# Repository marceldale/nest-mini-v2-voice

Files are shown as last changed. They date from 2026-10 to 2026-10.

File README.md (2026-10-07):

# Open voice satellite board for the Google Nest Mini (2nd gen)

A drop-in replacement board that turns a Google Nest Mini (2nd gen) into a fully local voice
assistant for Home Assistant. Started from the open design by
[iMike78](https://github.com/iMike78/nest-mini-drop-in-pcb) (nest-mini-drop-in-pcb,
CERN-OHL-S v2) and since then reworked, verified and extended into its own board. Everything
that was changed, and why, is in [CHANGES.md](CHANGES.md); the people and projects this one
stands on are named under [Credits](#credits).

> [!WARNING]
> **Status (5 Oct 2026): rev A2 in production at JLCPCB (2 boards, ordered 2 Oct 2026, completion
> expected around 14 Oct 2026).** Every change has been
> verified on paper only — netlist, ERC, DRC with schematic parity, datasheets, firmware source.
> The rotations of all 31 changed or new parts were checked in JLCPCB's assembly preview, and the
> board was ordered with the two fixed options (via filling, ENIG). **Nothing has been checked on
> hardware yet.** Until bring-up results are published here, **do not manufacture from these
> files.** Watch the repository for updates.

> [!NOTE]
> This status line changes again when the boards have been brought up. The steps are tracked in
> the roadmap below; the order itself is in [CHANGES.md](CHANGES.md#rev-a2-ordered-2-oct-2026).




## What it is

The Google Nest Mini (2nd gen) is a well-built little speaker: a good 40 mm driver, a
clean enclosure, two microphones and a touch surface. What ties it to Google is only the
circuit board inside.

This project replaces that board. You open the Nest Mini, take out Google's electronics
and put this board in its place. Speaker, housing, base plate and touch surface stay as
they are. What you get is a fully local voice assistant for Home Assistant: wake word,
speech and echo cancellation run on the device (ESP32-S3 + XMOS XU316), nothing leaves
your network, and the speaker still plays music and announcements.

Under the hood it follows the Home Assistant Voice Preview Edition: same processor
pair, same audio architecture, same ESPHome firmware base — fitted into the Nest Mini's
size, power and mounting constraints.

**What you need:** a Nest Mini (2nd gen), this board (assembled), a Home Assistant
installation and a USB-C cable for the ESP32. The XMOS gets its first image from the ESP32 itself
(a two-step button in Home Assistant; written and compiled, not yet run on hardware — see
Highlights), or over JTAG (J4, an XTAG4 adapter). Wi-Fi can be set up over Bluetooth (Improv,
confirmed by touching the centre button, as on Voice PE). If you
run it from USB rather than from the Nest Mini's own 14 V base plate, use a supply that can give
**1 A** — at full LED brightness the board draws up to 0.8 A, so a plain 500 mA charger is not
enough. On USB alone the amplifier has no supply — PVDD comes only from the 14 V rail (R66) — so
the speaker stays silent while microphones, LEDs and Wi-Fi work; the log then shows a PVDD
under-voltage fault or a `tas58xx` set-up error. That is expected, not a defect.

**What it is not:** a finished consumer product. It is an open hardware design at
prototype stage (see status above). No affiliation with Google.

## Highlights

* **XMOS flash written from the ESP32.** A bus switch (U16, after the Satellite1 principle) lets
  the ESP32 write the XMOS flash directly; the ESPHome component
  [`xmos_flasher`](firmware/esphome/components/xmos_flasher/README.md) does it from a two-step
  button in Home Assistant. **Written and compiled, not yet run on hardware.** JTAG stays as the
  fallback: J4 is an xSYS2 pad field, an XTAG4 plugs on 1:1. Later updates run over I²C (DFU) from
  the ESP32.

  **What the button overwrites:** the whole **1 MiB boot partition** of the XMOS flash U11 is
  erased (256 sectors) and rewritten with the factory image `firmware/xmos/ffva_v1.3.1_factory.bin`
  (286 720 bytes), checked against its MD5 and read back; everything after the image must read
  FFh. An image that a later DFU update put there is replaced by 1.3.1 as well. The data partition
  above 1 MiB is not touched, and the flash status registers are only read, never written — a
  write-protected flash is reported, not unlocked. It works on USB alone or on 14 V (all LEDs
  are switched off meanwhile; load below 0.5 A), needs the enable switch first and takes about 15 s;
  on success the ESP32 restarts.

* **Audio path as on Voice PE.** ESP32 feeds the amplifier and the echo reference on one
  line; XU316 is the clock master. Works with the unmodified Voice PE XMOS firmware.

* **Power without operating rules.** Upstream, USB-C and the 14 V supply must never be
  connected at the same time, and even USB alone back-feeds the 14 V rail through the
  buck converter (a known issue). This board adds an ideal diode (LM66100) behind the
  5 V converter and a small switch that disables the USB supply while 14 V is present.
  Result: plug in USB, 14 V or both, in any order, without risk to the board or the host
  PC.

* **XU316 core on a buck converter.** Upstream feeds the 0.9 V core from a 200 mA linear
  regulator dropping 2.4 V, while the XU316 draws about 300 mA typical and up to 1 A under
  DSP load: the regulator would overheat and the XMOS would brown out. This board uses the
  TPS62065 with 2 A. Also: touch controller wired, antenna matching at the antenna, mic-3 path removed, EasyEDA-checked
  footprints, every part with an LCSC number.

* **Expansion connector (12-pin FPC)** for an add-on ring board. We wanted more than a
  voice satellite: presence detection (radar over UART), temperature/humidity (I²C), IR
  transmit and receive for controlling TV or air conditioning, and an LED ring. None of
  this fits inside the Nest Mini housing (the mounting plate sits flush on the board), so
  the connector stays unpopulated there and the board works as a plain Nest Mini
  replacement. In a custom enclosure it connects to a ring board — LEDs, IR emitters and
  receivers, radar module — that is planned as the next project. The main board carries
  the signals, the ring board carries the sensors.

## Roadmap

- [x] Design review against upstream, Voice PE and Gen1 ([CHANGES.md](CHANGES.md))
- [x] Rev A2 schematic and layout: XMOS flash via ESP32, Voice PE audio path, power without
      operating rules, expansion connector routed
- [x] Rev A2 silkscreen: pin-1 marks, test point labels, revision and date; no DRC warnings left
- [x] Independent audit of rev A2; critical and layout-relevant findings fixed (CHANGES.md section 10)
- [x] Rev A2 manufacturing files regenerated after the audit fixes (`fertigung/`, 1 Oct 2026)
- [x] Rotation check of the 31 changed or new parts in the fabricator's assembly preview
      (JLCPCB preview, 2 Oct 2026; U18, U16, U5, Q4 corrected in the CPL beforehand, Y1 by order remark)
- [x] ESP32-side flasher for the XMOS image — written and compiled, not yet run on hardware
      (`firmware/esphome/components/xmos_flasher/`; fallback: J4 with an XTAG4)
- [x] Rev A2 ordered: 2 assembled boards (5 bare PCBs), JLCPCB, 2 Oct 2026
- [ ] Bring-up: resistance check, power rails, XMOS flash via ESP32
- [ ] Audio, microphones, echo cancellation, touch, LEDs
- [ ] Wi-Fi sensitivity against a reference device
- [ ] Firmware release (ESPHome YAML + XMOS factory image)
- [ ] Ring board and enclosure files
- [ ] Certification plan
- [ ] Crowd Supply campaign

## Trademarks

Google and Google Nest Mini are trademarks of Google LLC. This project is not affiliated with,
endorsed by or sponsored by Google. Home Assistant and ESPHome are projects of the Open Home
Foundation / Nabu Casa. XMOS and xcore are trademarks of XMOS Ltd. All trademarks belong to
their respective owners and are used here only to say what this board is compatible with.

## Licences

| What | Licence |
|---|---|
| Hardware — schematic, layout, our footprints, manufacturing data | **CERN-OHL-S v2** |
| ESPHome YAML, Python tools, documentation | **MIT** |
| XMOS firmware image under `firmware/xmos/` | **XMOS Public Licence v1** — not ours |
| ESPHome component `xmos_flasher` under `firmware/esphome/components/` | **GPL-3.0-only** for the C++ files — derived from [FutureProofHomes/Satellite1-ESPHome](https://github.com/FutureProofHomes/Satellite1-ESPHome) (`memory_flasher`, © Mischa Siekmann, commit `8f8906c`), whose `LICENSE` is the ESPHome licence: C/C++ under GPLv3 without "or any later version", Python under MIT. `__init__.py`, the README and the host test are **MIT**. See [`LICENSES/GPL-3.0-only.txt`](LICENSES/GPL-3.0-only.txt) |
| ESPHome component `tas58xx` under `firmware/esphome/components/` | **GPL-3.0-or-later** — © mrtoy-me, based on work by Andriy Malyshenko (sonocotta); patched by us (start-up order, loop bandwidth), see [`firmware/esphome/PATCH.md`](firmware/esphome/PATCH.md) |
| KiCad library excerpts in `lib_lokal/` | **CC-BY-SA-4.0**, © KiCad Libraries Contributors |
| Parts of `lib_lokal/` (vendor footprints and symbols) | **terms not established** — see below |

Full texts are in [`LICENSES/`](LICENSES/). Files that can carry a comment header do carry an
`SPDX-License-Identifier`; for KiCad documents, Gerbers and binaries the assignment is in
[`REUSE.toml`](REUSE.toml), following the [REUSE](https://reuse.software) specification.

**One honest gap**, written up in
[`LICENSES/LicenseRef-Vendor-Model-Terms-Not-Established.txt`](LICENSES/LicenseRef-Vendor-Model-Terms-Not-Established.txt):

* The vendor 3D models the board references are **not** part of this repository: we hold no
  licence document for any of them. The 3D view therefore shows those parts without a body;
  fabrication and assembly do not need them.
* Parts of `lib_lokal/` have a similar problem: ten of the 23 footprints in `Onju.pretty` carry a
  SnapEDA or EasyEDA note, `New_Library.kicad_sym` is SnapEDA, and the Seeed and reSpeaker symbols
  come from Seeed's project. They arrived with the upstream design and we pass them on unchanged.
  This directory **cannot** be left out — without it the design does not open.

**`lib_lokal/` and the two library tables are versioned on purpose.** The design references every
symbol and footprint through `${KIPRJMOD}/lib_lokal/`, so a clone without them opens with empty
placeholders. The directory holds trimmed excerpts, not whole libraries: `Device.kicad_sym` is
17 kB here against 2 374 kB in a KiCad 9.0.9 installation. KiCad's library licence grants an
exception for designs that *use* the libraries but states that it does not apply when they are
redistributed as a collection — which is what this directory does — so those files keep
CC-BY-SA-4.0 with attribution.

The C++ code in this repository is the patched copy of the ESPHome component `tas58xx`
(GPL-3.0-or-later) and the component `xmos_flasher` (GPL-3.0-only, because its source states GPLv3
without "or later"), both under `firmware/esphome/components/`; see the table above.
CERN-OHL-S v2 is a **strongly reciprocal** licence: if you make and distribute a board from
these files, or from a modified version of them, you have to make the complete source of your
version available under the same licence. See
[`LICENSES/CERN-OHL-S-2.0.txt`](LICENSES/CERN-OHL-S-2.0.txt), sections 3.2 and 4.

---

# For reference

Everything below is the technical detail — useful once you have a board in your hand, and not
needed to understand what the project is.

## Test points

Eighteen pads, all bare copper, nothing to populate. Sixteen are on the microphone side; the touch
electrodes are on the LED side. The silkscreen carries a short name next to each pad — the full net
name would not fit on a 68 mm board.

| Marking | Ref | Net | Side | Position | What you should see |
|---|---|---|---|---|---|
| `3V3` | TP1 | `+3V3` | microphone side | 163.00 / 74.50 | 3.3 V |
| `5V_SW` | TP3 | `/Power/+5V_SW` | microphone side | 121.40 / 102.00 | about 5 V, **before** the ideal diode U18 |
| `1V8` | TP4 | `+1V8` | microphone side | 145.70 / 71.50 | 1.8 V |
| `VDD` | TP5 | `VDD` | microphone side | 130.40 / 81.60 | 0.9 V |
| `3V3` | TP6 | `+3V3` | microphone side | 107.40 / 94.60 | 3.3 V |
| `XRST` | TP11 | `XU316_RST` | LED side | 126.10 / 66.50 | logic; high = XU316 held in reset |
| `MUTE` | TP12 | `MUTE` | microphone side | 140.90 / 116.80 | logic; follows the mute slider |
| `PA_EN` | TP13 | `AUDIO_PA_EN` | microphone side | 130.70 / 109.10 | logic; high = amplifier enabled |
| *(no marking)* | TP14 | `ELEC2` | LED side | 159.20 / 89.90 | touch electrode, right |
| *(no marking)* | TP15 | `ELEC1` | LED side | 135.82 / 119.53 | touch electrode, centre |
| *(no marking)* | TP16 | `ELEC0` | LED side | 114.20 / 88.90 | touch electrode, left |
| `5V` | TP17 | `+5V` | microphone side | 122.42 / 105.55 | about 5 V, **after** U18 — below TP3 by I × 79 mΩ (LM66100 R_ON): ≈ 8 mV per 100 mA, 55…65 mV at 0.7…0.8 A |
| `14V` | TP18 | `+14V` | microphone side | 143.90 / 109.43 | 14 V from the base plate |
| `RST` | TP19 | `ESP_RST` | microphone side | 118.58 / 79.30 | logic; low = ESP32 in reset |
| `BOOT` | TP20 | `ESP_BOOT` | microphone side | 121.84 / 81.75 | logic; low at power-up = boot mode |
| `GND` | TP21 | `GND` | microphone side | 120.58 / 64.74 | 0 V reference, next to U8 |
| `GND` | TP22 | `GND` | microphone side | 128.74 / 104.08 | 0 V reference, next to U14 |
| `VMIC` | TP23 | `VDD_MIC` | microphone side | 105.10 / 88.35 | 3.3 V microphone supply |

The three touch points carry no silkscreen: they sit inside the electrode rings on the LED side,
where any lettering would end up on copper. Their names are `T_R`, `T_C` and `T_L` in the schematic.

**The pair TP3 / TP17 is the one to measure first.** TP3 sits before the ideal diode U18, TP17
after it. The difference is the load current times U18's on-resistance (79 mΩ typical, LM66100 datasheet):
under 20 mV at idle, about 55…65 mV at 0.7…0.8 A; in USB-only operation TP3 should read
roughly 0 V, because the 14 V rail is then dead and the diode blocks the path back into it.

## Connectors

The board carries a designator and a pin-1 dot for every connector; the pinouts are here rather than
on the silkscreen, where they would not be legible at 0.5 mm pitch.

### J6 — ribbon cable to the LED ring board, 12 way, 0.5 mm pitch

| Pin | Net | | Pin | Net |
|---|---|---|---|---|
| 1 | `GND` | | 7 | `UART_RX` |
| 2 | `+5V` | | 8 | `I2C_SDA` |
| 3 | `+5V` | | 9 | `I2C_SCL` |
| 4 | `GND` | | 10 | `IR_TX` |
| 5 | `LED_DOUT` | | 11 | `IR_RX` |
| 6 | `UART_TX` | | 12 | `+3V3` |

Pin 1 is the one nearest the dot. `LED_DOUT` continues the LED chain from LED6 through R80, so the
ring board's first LED is index 6 as far as the firmware is concerned.

### POWER_IN1 — flat flex to the base plate, 10 way, 0.5 mm pitch

| Pin | Net | | Pin | Net |
|---|---|---|---|---|
| 1 | `GND` | | 6 | `GND` |
| 2 | `MUTE` | | 7 | `+14V` |
| 3 | `GND` | | 8 | `+14V` |
| 4 | `GND` | | 9 | `+14V` |
| 5 | `GND` | | 10 | `+14V` |

**Confirmed pin for pin against an independent design:** the schematic of
[Onju Voice](https://github.com/justLV/onju-voice) (`hardware/Onju-Home.SchDoc`, a replacement
board for the same Nest Mini 2nd gen) has the same ten-way connector as J1, and all ten pins
agree — 1 and 3–6 `GND`, 2 `MUTE`, 7–10 `14V`. Metering it on an original is optional; the quick
check is in `CHANGES.md` ("POWER_IN1: the pinout is now confirmed against a second source").

### J4 — XMOS JTAG pad field, 2×5, 1.27 mm pitch, unpopulated

The pin-out is the **xSYS2 JTAG-only header** of the XU316 datasheet (appendix G.3, figure 25), so
an XTAG4 plugs on **1:1** — pin 1 to pin 1. Pin 1 is marked by the silkscreen dot.

| Pin | Net | | Pin | Net |
|---|---|---|---|---|
| 1 | `+1V8` (VREF) | | 2 | `TMS` |
| 3 | `GND` | | 4 | `TCK` |
| 5 | `GND` | | 6 | `TDO` |
| 7 | `GND` | | 8 | `TDI` |
| 9 | `GND` | | 10 | `RST_N` |

VREF is 1.8 V on pin 1, with 100 nF (C103) right next to it. There is no 5 V and no 3.3 V on this
field. Up to the audit fixes of 1 Oct 2026 the field carried a rotated, non-standard pin-out with
VREF on pin 6; a board made from an older revision needs an adapter.

## Before bring-up

> [!NOTE]
> **Amplifier driver.** The ESPHome core component `tas58xx` (TAS5805M) arrives with ESPHome 2026.10.
> Until then use ESPHome `dev`, or the patched copy under `firmware/esphome/components/tas58xx`, which
> `nest-mini-v2-voice.yaml` loads by default and which builds with ESPHome 2026.9.0. A configuration for
> the core component is [`nest-mini-v2-voice-kerntreiber.yaml`](nest-mini-v2-voice-kerntreiber.yaml)
> (ESPHome `dev` / 2026.10 or later; it adds the 175 kHz loop bandwidth the core component does not set yet).

> [!CAUTION]
> **Do not burn `EFUSE_STRAP_JTAG_SEL` on the ESP32-S3.** Rev A2 uses GPIO3 and GPIO39 to
> GPIO42 as an SPI bus to the XMOS flash. In the factory state JTAG runs over the
> USB-Serial/JTAG controller and those pins are free; burning the eFuse switches JTAG to
> those pins and breaks the XMOS flash path. Details in
> [CHANGES.md](CHANGES.md#do-not-burn-efuse_strap_jtag_sel-esp32-s3).

## Manufacturing files

**`fertigung/` holds the rev A2 set**, generated after the audit fixes on 1 Oct 2026: Gerbers and
Excellon drill files, `gerber_jlcpcb.zip` for upload, BOM and CPL for JLCPCB, BOM and assembly
drawing for PCBWay. [`fertigung/ABLAUF.md`](fertigung/ABLAUF.md) documents the commands that
produce it and the checks each one prints — nothing in that directory is edited by hand.
**It is not released**: the board has never been fabricated, and two checks are still open (see
below).

Before ordering, these are the points to watch; the full list with the evidence is under
["Before you order" in CHANGES.md](CHANGES.md#before-you-order-the-seven-things-to-get-right):

* **0.10 mm minimum track width** for the two UART signals — fabricable at JLCPCB without a
  surcharge, but not everywhere.
* **Via-in-pad:** board vias reach into 23 pads (58 vias, all same-net), among them three signal
  pads and the large pads of U8 and U10. Order the vias **Epoxy Filled & Capped**.
* **U11 must be the `IQ` variant** of the W25Q32JV, not `IM` — the footprint cannot tell them
  apart, and only `IQ` has the QE bit set at the factory.
* Seven same-net via pairs sit exactly at the **0.2 mm hole-to-hole limit**.
* **J1** (Molex 1054500101, C134092) is stocked but flagged “process difficult” in the BOM
  check — confirm it by hand.
* Stack-up: 4 layers, 1.6 mm, **JLC04161H-7628**; surface finish chosen at order time.

Placement corrections by hand are **no longer needed**: rev A1 shipped a CPL with 19 of them, and
rev A2 fixes the footprint origins themselves instead (X1, J5, J1), so the CPL exporter
writes a correct CPL directly; the remaining nineteen corrections are applied automatically.

**Two things are still open**, both for the operator and both listed in
[`fertigung/DREHLAGEN_PRUEFEN.md`](fertigung/DREHLAGEN_PRUEFEN.md):

1. **31 parts need checking in JLCPCB's assembly preview** — those whose LCSC number changed
   since rev A1 (U5, LED2–LED5, J6, R76, R77, R80, X1, J1) or that are new (U16, U18, U19, Q4),
   nine from the audit fixes (L1, L2 with a new footprint; C20, C100 with new numbers;
   C105–C109 new, all unpolarised), and seven from the pin audit and the order (Y1 with a new number — the one
   where rotation matters, a 90° error puts the crystal on the ground pads, and it has no model in
   the preview, so the order carries the remark "Y1 orientation per silkscreen pin-1 corner mark
   (top-left)"; R72, C17, C63, C98, R35 with new numbers; R81 new). The first preview on 2 Oct 2026
   found U18 and U16 turned; a recomputation of all 42 polarised parts against the fabricator's
   footprints corrected four rotations (U18, U16, U5, Q4) — see `CHANGES.md`. C110 is not fitted and not in the CPL.
   For them the fabricator's own footprint decides the zero orientation, and that has not been
   compared yet. Everything else was checked in rev A1 and has not moved since.
2. **Two order options are fixed for this board** and have to be selected because they are not in
   the Gerbers: via covering ***Epoxy Filled & Capped*** (vias reach into 23 pads) and surface
   finish **ENIG** — decided, not optional (0.40 mm pitch, QFN thermal pads, the J4
   spring-contact field, test points and touch electrodes). Both are in "Before you order" in
   `CHANGES.md`.

The upstream design and its own documents are at
[iMike78/nest-mini-drop-in-pcb](https://github.com/iMike78/nest-mini-drop-in-pcb).

## Credits

This board exists because other people published theirs first.

* **[iMike78](https://github.com/iMike78/nest-mini-drop-in-pcb)** — *nest-mini-drop-in-pcb*,
  the design this one forks. The board outline, the mounting geometry, the microphone and touch
  arrangement and a great deal of the layout are the designer's work.
* **[Onju Voice](https://github.com/justLV/onju-voice)** (Justin Alvey) — the first drop-in
  board for the Nest Mini, and the origin of the `Onju` footprint library this project still uses.
* **[Home Assistant Voice PE](https://github.com/esphome/home-assistant-voice-pe)**
  (Nabu Casa / Open Home Foundation) — the audio architecture this board follows: the same
  ESP32-S3 + XMOS XU316 pair, the same clocking, and the XMOS firmware it runs.
* **[Satellite1](https://github.com/FutureProofHomes/Satellite1-ESPHome)** (FutureProofHomes)
  — the method for flashing the XMOS from the ESP32, which is what makes this board
  programmable without a debugger.
* **[ESPHome](https://esphome.io) and [Home Assistant](https://www.home-assistant.io)** — the
  firmware and the platform all of it runs on.

## How to follow or contribute

Star or watch the repository. **Issues and Discussions are handled here, in this repository:**
Discussions for questions, Issues for errors in the design or the documentation. Hardware
support starts after bring-up. Reference thread: Home Assistant community, topic 860001.

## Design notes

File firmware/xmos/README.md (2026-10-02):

# XMOS XU316 factory flash image

`ffva_v1.3.1_factory.bin` is the factory boot image for **U10 (XU316-1024-QF60B-C24)** and its
boot flash **U11 (W25Q32JVSSIQ, 4 MB)**. It contains the XTC boot loader and the factory
application, ready to be written to the SPI flash.

## Source notice (XMOS Public Licence v1, clause 2.3)

This file is compiled code. **The source code of the software it is built from is available under
the terms of the XMOS Public Licence v1** — a copy of which is in this directory as
`LICENCE-XMOS-PUBLIC-LICENCE-v1.rst` — from:

* <https://github.com/esphome/voice-kit-xmos-firmware> — the FFVA firmware for the Home Assistant
  Voice Preview Edition, tag **`v1.3.1`** (released 2024-09-17)

Nothing in the firmware was changed here. The `.xe` release artefact was repackaged into a flash
image by `xflash`; no source file was modified, added or removed.

Clause 2.2.2 of that licence permits commercial distribution only while the software is used on a
device designed, licensed or developed by XMOS. That is the case here: it runs on the XU316.

## Provenance

| | |
|---|---|
| Built from | `ffva_v1.3.1.xe`, 5 779 572 bytes, MD5 `7233589645bce7f7289c47136c0792ae` |
| Downloaded from | <https://github.com/esphome/voice-kit-xmos-firmware/releases/download/v1.3.1/ffva_v1.3.1.xe> |
| Tool | XMOS XTC Tools **15.3.1**, `xflash` build 61-0e6d8350 (2024-07-04) |
| Built on | 2026-09-30 |

## How this file was produced

```
xflash --factory ffva_v1.3.1.xe --boot-partition-size 0x100000 -o ffva_v1.3.1_factory.bin
```

The build is deterministic and the result does not depend on the target description: the same
286 720 bytes come out with `--target-file NC-VOICE-KIT.xn`, with an XN whose flash `Type` is changed
from `S25FL116K` to `W25Q32JV`, and with `--boot-partition-size` set to `0x80000` or omitted
entirely. The target description is compiled into the `.xe`, and the boot-partition size is metadata
rather than padding. So this file can be reproduced from the public release asset at any time, and
the checksums in `MD5SUMS` are the check.

## Size against the flash

| | Bytes | Share |
|---|---|---|
| This image | 286 720 (280.0 KiB) | — |
| Boot partition (`0x100000`) | 1 048 576 | 27.3 % used |
| U11 flash (W25Q32JVSSIQ) | 4 194 304 | **6.8 % used** |
| Left for the data partition | 3 145 728 (3 MiB) | — |

## Writing it

This image is for an external programmer or for assembly-time programming. **Over JTAG you do not
need it** — `xflash` writes directly from the `.xe`:

```
xflash --quad-spi-clock 50MHz --factory ffva_v1.3.1.xe --boot-partition-size 0x100000
```

The XTAG4 goes onto the J4 pad field **1:1**: J4 follows the xSYS2 JTAG-only pin-out of the XU316
datasheet (appendix G.3) — 1 VREF (`+1V8`), 2 TMS, 4 TCK, 6 TDO, 8 TDI, 10 RST_N, 3/5/7/9 GND; pin 1
is marked by the silkscreen dot. The pad
field is unpopulated — solder or use spring contacts. `xflash --list-devices` must show the adapter
and the device first. Afterwards power-cycle the board: the ESPHome log has to show
`[voice_kit] DFU version: 1.3.1` (about 3 s after the ESP32 resets the XU316) and must not show
`Communication with Voice Kit failed` before the first-time programming counts as done. From then on
updates go over DFU via I²C from the ESP32.

None of the XTC tools is on the search path on the design machine; load the environment per call:

```
cmd /c "cd /d <dir> && "C:\Program Files\XMOS\XTC\15.3.1\SetEnv.bat" && xflash …"
```

`W25Q32JV` is one of the 15 flash devices natively supported by `libquadflash`
(`target/include/QuadSpecEnum.h`, `WINBOND_W25Q32JV = 13`), so no `--spi-spec` file is needed and
nothing depends on SFDP auto-detection.

One thing to watch on the first write: the firmware's own target description sets
`QE_REGISTER = flash_qe_location_status_reg_0` and leaves `QE_BIT` commented out. Our part carries the
`IQ` order suffix, where the QE bit is factory-fixed to 1, so it should not be needed. If `xflash`
complains about the QE bit, set it in a local XN.

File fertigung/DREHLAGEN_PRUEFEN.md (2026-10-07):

# Drehlagen und Positionen fuer die JLCPCB-Vorschau — Soll-Zustand

Stand: **02.10.2026**, nach der JLCPCB-Vorschau berichtigt (U18, U16, U5, Q4; Y1-Bemerkung; R35).
Zuvor: 01.10.2026, erzeugt aus `CPL_JLCPCB.csv` und der Platine (rev A2 Endstand).
Die Fassung vom 21.09.2026 ist ersetzt; sie nannte U1, U2, C1, C2, R37, R38, R51, R64
und FB3, die es nicht mehr gibt, und kannte die in E2.3, E4, E5c und F7.3 neu
eingefuegten Bauteile nicht.

**Grundlage:** `ft_cpl.py` (Logik des Fabrication Toolkit) plus
`werkzeug/jlc_korrektur.csv` (19 Zeilen). Die Korrekturen stammen aus einem Abgleich mit
dem EasyEDA-Footprint der jeweiligen LCSC-Nummer; dieser Footprint bestimmt JLCPCBs
Nullage und Mittelpunkt.

* **Konvention**, an den laut Vorschau richtigen Teilen bestaetigt:
  * oben: CPL-Drehung = Drehung des EasyEDA-Footprints
  * unten: CPL-Drehung = 360° − Drehung des gespiegelten EasyEDA-Footprints
  * Bestaetigt oben an U8 und U9, unten an U10, U11, Q1, Q3 und X1; am 02.10.2026 an allen
    42 gepolten und mehrpoligen Teilen nachgerechnet (Abschnitt „Berichtigung").
* **Pin 1** ist die Lage von Pad 1 relativ zur Padmitte, in der Ansicht der Vorschau:
  oben in Draufsicht, unten in Unteransicht — also seitenverkehrt zur Draufsicht.
  Die Werte unten sind aus unserem Footprint gerechnet.
* In der Vorschau pruefen: rosa Punkt an der angegebenen Ecke; Bestueckungsdruck-Marke
  an derselben Ecke; das Gehaeuse deckt alle Pads.

## Berichtigung nach der JLCPCB-Vorschau vom 02.10.2026

Die Bestellung wurde angehalten: die Vorschau zeigte U18 mit Pin 1 oben links statt unten links
(VIN/VOUT vertauscht), U16 mit Pin 1 unten rechts statt unten links und Y1 nur als Platzhalter.
Daraufhin wurde **jedes gepolte oder mehrpolige Bauteil** (42 Zeilen, Tabelle unten) gegen den
EasyEDA-Footprint seiner LCSC-Nummer nachgerechnet, nicht nur die drei gemeldeten: Footprint laden,
an die CPL-Mitte legen (unten in x gespiegelt), in 45°-Schritten drehen und gleichnamige Pads
zaehlen (`werkzeug/easyeda_abgleich.py`, Daten `pruefung/easyeda_pads_2026-10-02.json`).

**Vier Drehungen waren falsch**, alle vier jetzt in `werkzeug/jlc_korrektur.csv` (19 Zeilen):

| Bauteil | LCSC | Seite | CPL bisher | CPL jetzt | Abgleich mit dem EasyEDA-Footprint | Folge der alten Drehung |
|---|---|---|---|---|---|---|
| **U18** | C2869734 | oben | 270° | **0°** | 6/6 Pads in gleicher Reihenfolge; Pin 1 unten links (`/Power/+5V_SW`). EasyEDA setzt die Padreihen bei ±1,10 mm, unser Footprint bei ±0,89 mm — 0,21 mm je Reihe, symmetrisch nach aussen, die Anschluesse liegen auf den Pads | Gehaeuse quer, VIN/VOUT vertauscht (Meldung aus der Vorschau) |
| **U16** | C129313 | unten | 90° | **0°** | 10/10 Pads, max. 0,04 mm; Pin 1 in der Vorschau (Unteransicht) unten links | Pin 1 unten rechts (Meldung aus der Vorschau) |
| **U5** | C133796 | oben | 0° | **270°** | 5/5 Pads, max. 0,13 mm; EasyEDA hat Pin 1 unten rechts (Endung `-BR`), unser Footprint unten links | Eingangs- und Ausgangsseite quer; die alte Korrekturzeile „unverdreht deckungsgleich" war falsch |
| **Q4** | C383201 | oben | 0° | **180°** | 3/3 Pads, max. 0,03 mm; Pin 1 (`USB_EN_GATE`) oben links | Gate/Source auf der Drain-Seite; Q1 und Q2 mit derselben Nummer waren richtig, weil fuer sie eine andere Regel greift |

Alle uebrigen 38 Zeilen stimmen mit dem EasyEDA-Footprint. Nicht als Zaehlung, sondern im
Einzelnen belegt sind:

* **J5:** EasyEDA zerlegt jeden der beiden 7-mm-Kontaktstreifen in zwei Pads (1+4, 2+3); bei 225°
  liegen 1 und 4 auf unserem Streifen 1, 2 und 3 auf Streifen 2 — richtig.
* **D6:** 1→1 und 2→2 bei 270°, je 0,32 mm Versatz (anderer Padabstand), richtig.
* **U3/U7:** 16/17 — das Waermepad ist bei uns in Teilflaechen zerlegt; alle Anschlusspads 0,04 mm.
* **MK1/MK2:** 4/8 — Massering wie unter „Einzelhinweise".
* **SW1/SW2:** 2/4 — Taster, 180°-symmetrisch, Pads 1/2 und 3/4 paarweise verbunden.

**Y1 (C49158179):** EasyEDA liefert fuer die Nummer kein Bauteil („Component not found",
abgefragt 02.10.2026); die Vorschau zeigt nur einen Platzhalter, und der Bestuecker legt das
Teil von Hand auf. Die Drehung in der CPL (270°) bleibt; massgeblich ist die Bestueckungsdruck-Marke:
der Winkel im Bestueckungsdruck sitzt an der Ecke **oben links**, und dort liegt Pad 1
(`XTAL_N`) — aus der Platine nachgemessen (Winkel 117,03…119,57 / 67,83…70,77 mm, Pad 1 bei
117,75 / 68,60). **Bemerkung fuer JLCPCB im Bestellformular:**

> Y1 orientation per silkscreen pin-1 corner mark (top-left).

**R35:** neue Nummer **C100510** (LIZ Elec CR0402FF6800G, 680 Ω 1 % 0402) statt C25130, Ersatz auf
Angabe des Betreibers. Ungepolt; Zeile in der Tabelle des Pin-Audits.

Quelle der Footprint-Daten: JLCEDA/EasyEDA Official Library (https://lceda.cn/,
https://easyeda.com), abgerufen am 02.10.2026 ueber
`easyeda.com/api/products/<LCSC>/components`.

## JLCPCB-DFM-Rückfrage LED-Polarität (05.10.2026) — Ansichtskonvention und Sollage

**Ansicht in JLCPCBs DFM-Bildern:** Die Unterseite wird **links-rechts gespiegelt** gezeigt, so dass
der Bestückungsdruck lesbar ist: **J1 oben links**, auf der LED-Seite liegt **LED5 links, LED2 rechts**.
Das ist dieselbe Ansicht wie KiCads „Flip board view“ (Spiegelung um die senkrechte Achse) und wie die
Spalte „Pin 1 in der Vorschau“ dieser Datei für Bauteile auf der Unterseite. Die Oberseite wird
ungespiegelt gezeigt (J1 oben rechts).

**Befund (Betreiber, DFM-Bild zu SMT026100262223):** Das JLCPCB-Modell zeigte bei LED2–LED5 „+“ und den
Pin-1-Punkt **unten links**, „−“ oben rechts, DI oben links, DO unten rechts. In dieser Ansicht liegt
unser Pad 1 (+5V) aber **oben rechts** → Modell **um 180° falsch**. LED1 war richtig. Der Betreiber hat
JLCPCB um eine 180°-Drehung von LED2–LED5 und ein neues Bild gebeten (05.10.2026). **Ergebnis:** JLCPCB hat
LED2–LED5 um 180° korrigiert; neues Bild vom 05.10.2026 zeigt +5V oben rechts in der gespiegelten
Unteransicht — vom Betreiber freigegeben. LED1 bestätigt, **LED6 nicht ausdrücklich bestätigt** (Sichtprüfung
bei der Inbetriebnahme, Arbeitsnotizen, nicht veröffentlicht: HANDGRIFFE Schritt 0.7). Fertigung freigegeben, Fertigstellung ca. 14.10.2026.

**Merkregel für künftige Vorschauen bei JLCPCB:** Oberseite ungespiegelt (J1 oben rechts); Unterseite
links-rechts gespiegelt (J1 oben links). Die Spalte „Pin 1 in der Vorschau“ dieser Datei gilt genau in dieser
Ansicht. Ein Modell, dessen Pin-1-Punkt an einer anderen Ecke liegt, ist zu beanstanden — auch wenn der
EasyEDA-Abgleich nummerngleich passt (LED2–LED5, 05.10.2026).
Widerspruch zum EasyEDA-Abgleich vom 02.10.2026: dort passen bei CPL 90° alle 4 Pads des EasyEDA-Footprints
von C2909058 nummerngleich auf unsere Pads. JLCPCBs Bestückmodell weicht also vom EasyEDA-Footprint ab
(Pin-1-Lage), oder die Nummerierung im EasyEDA-Footprint passt nicht zum Gehäuse — ungeklärt. Für eine
Folgefertigung: Arbeitsnotizen (nicht veröffentlicht), HANDGRIFFE Abschnitt 6, F4.

**Sollage je LED in JLCPCBs Ansicht**

| Bauteil | Seite / Ansicht | +5V | GND | DIN | DOUT | Gehäusemerkmal |
|---|---|---|---|---|---|---|
| LED2, LED3, LED4, LED5 (SK6812-EC20, Pin 1 = VDD) | unten, gespiegelt (J1 oben links) | **oben rechts** (Pad 1) | unten links (Pad 3) | unten rechts (Pad 4) | oben links (Pad 2) | Kerbe auf der Gehäuseunterseite an der Kante +5V/DOUT, also **oben**; IC-Chip an der Kante GND/DIN (unten) |
| LED1 (SK6812D-EC3210R, westliche Lasche) | oben, ungespiegelt (J1 oben rechts) | 2. Pad von Süden (Pad 4) | 2. Pad von Norden (Pad 1) | Südende (Pad 3) | Nordende (Pad 2) | Linse nach Westen (Platinenkante); kein Punkt im Datenblatt |
| LED6 (SK6812D-EC3210R, östliche Lasche) | oben, ungespiegelt | 2. Pad von Norden (Pad 4) | 2. Pad von Süden (Pad 1) | Nordende (Pad 3) | Südende (Pad 2) | Linse nach Osten (Platinenkante) |

Reihenfolge auf der LED-Seite in dieser Ansicht von links nach rechts: LED5, LED4, LED3, LED2; der DO jeder
LED zeigt zum DI der links benachbarten. Sollbild: `pruefung/jlcpcb_led_sollage_2026-10-05.png` (dort in der
anderen Spiegelung, oben/unten — Pad-Netze gleich).

## Was nach rev A1 neu zu pruefen ist

Fuer diese **15** Bauteile hat sich die LCSC-Nummer geaendert oder das Bauteil ist neu.
JLCPCB hinterlegt dann einen anderen EasyEDA-Footprint, und der bestimmt die Nullage.
**Nur diese Zeilen muss der Betreiber in der Vorschau durchsehen** — alles andere war
in rev A1 abgeglichen und ist seither unveraendert.

| Bauteil | Seite | Drehung | Mitte X / Y | Pin 1 (Netz) | warum neu |
|---|---|---|---|---|---|
| **J1** | oben | 135° | 152.9000 / -65.8000 | unten (GND) | in E5.3 als FP_SMD gekennzeichnet, Position daher aus dem Ursprung |
| **J6** | oben | 270° | 157.9750 / -93.7810 | unten rechts (GND) | neu in E5c; Nummer in E7 von C25744/C324723 auf C424659 berichtigt |
| **Q4** | oben | 180° | 157.0000 / -83.9000 | oben links (/Power/USB_EN_GATE) | neu in E4; Nummer C383201 erst in E7 eingetragen; Drehung am 02.10.2026 von 0° berichtigt |
| **R76** | oben | 0° | 156.4000 / -81.8000 | links (+14V) | Nummer in E7 von C17168 (0 Ohm!) auf C26083 (1 M) berichtigt |
| **R77** | oben | 0° | 157.1000 / -80.8000 | links (/Power/USB_EN_GATE) | Nummer in E7 von C17168 (0 Ohm!) auf C25778 (330 k) berichtigt |
| **R80** | oben | 0° | 154.7000 / -90.6900 | links (/LEDs/LED6_DOUT) | Nummer in E7 von C25744 (10 k!) auf C25076 (100 R) berichtigt |
| **U5** | oben | 270° | 141.0000 / -75.9650 | unten links (+3V3) | Typ MIC5365-1.8 -> TLV70018DCKR (C626087 -> C133796), E5.2; Drehung am 02.10.2026 von 0° berichtigt |
| **U18** | oben | 0° | 124.8000 / -106.7000 | unten links (/Power/+5V_SW) | neu in E4; Nummer C2869734 erst in E7 eingetragen; Drehung am 02.10.2026 von 270° berichtigt |
| **LED2** | unten | 90° | 125.2624 / -89.1135 | oben rechts (+5V) | Typ SK6805-EC20 -> SK6812-EC20 (C2890036 -> C2909058), E6 |
| **LED3** | unten | 90° | 132.2500 / -89.1000 | oben rechts (+5V) | Typ SK6805-EC20 -> SK6812-EC20 (C2890036 -> C2909058), E6 |
| **LED4** | unten | 90° | 139.2000 / -89.1000 | oben rechts (+5V) | Typ SK6805-EC20 -> SK6812-EC20 (C2890036 -> C2909058), E6 |
| **LED5** | unten | 90° | 146.1000 / -89.1000 | oben rechts (+5V) | Typ SK6805-EC20 -> SK6812-EC20 (C2890036 -> C2909058), E6 |
| **U16** | unten | 0° | 121.5000 / -70.2500 | unten links (unconnected-(U16-D1+-Pad1)) | neu in E2.3; Drehung am 02.10.2026 von 90° berichtigt |
| **U19** | unten | 0° | 118.4500 / -84.4500 | unten rechts (GND) | neu in F7.3; Nummer C12495 erst in E7 eingetragen |
| **X1** | unten | 270° | 133.0000 / -59.5000 | oben links (Net-(U10-XIN)) | Ursprung in E5.3 auf das Bezugszentrum gesetzt |

Bei den vier Ring-LEDs ist die Erwartung, dass sich **nichts** aendert: beide LED-Typen
haben die Anschluesse an denselben Stellen (Datenblaetter SK6805-EC20-001 Rev. A1 und
SK6812-EC20-001 Rev. A/2, je Seite 4), und die CPL-Werte sind vor und nach dem Wechsel
gleich. Zu pruefen ist allein, ob JLCPCBs Footprint fuer C2909058 dieselbe Nullage hat
wie der fuer C2890036. **Ergebnis 05.10.2026: nein** — JLCPCBs Modell lag um 180° falsch (Abschnitt
„JLCPCB-DFM-Rückfrage LED-Polarität“).

## Nach den Audit-Fixes vom 01.10.2026 zusaetzlich zu pruefen

Die CPL ist aus dem Stand nach den Audit-Fixes neu erzeugt. **Neun** Zeilen kommen hinzu. Alle sind
ungepolt (Kondensatoren, Spulen); in der Vorschau zu pruefen ist nur, dass das Gehaeuse mittig auf
beiden Pads sitzt und nichts versetzt ist.

| Bauteil | Seite | Drehung | Mitte X / Y | LCSC | warum neu |
|---|---|---|---|---|---|
| **L1** | oben | 90° | 121.0125 / -109.5615 | C719179 | neuer Footprint `L_Bourns_SRP4020TA` (Audit M18): Pads 1,5 x 2,4 mm bei ±1,85 mm statt Cenker-Landmuster; LCSC-Nummer unveraendert |
| **L2** | oben | 90° | 112.0000 / -98.0500 | C719179 | wie L1 |
| **C100** | oben | 0° | 133.6000 / -82.3000 | C40059 | neue Nummer (120 pF statt 22 pF, Audit M2) |
| **C20** | oben | 0° | 137.5896 / -75.1115 | C1779 | neue Nummer (4,7 µF statt 10 µF, Audit M2) |
| **C105** | unten | 270° | 124.3000 / -115.9800 | C307331 | neu (Audit M1), 0402 auf B.Cu unter U3 |
| **C106** | unten | 270° | 115.7500 / -106.4300 | C1525 | neu (Audit M1), 0402 auf B.Cu unter U7 |
| **C107** | oben | 0° | 143.0000 / -65.9400 | C19702 | neu (Audit M3), 0603 |
| **C108** | oben | 315° | 105.6000 / -85.1000 | C1525 | neu (Audit M11), 0402 schraeg neben MK1 |
| **C109** | oben | 0° | 168.6000 / -92.2000 | C1525 | neu (Audit M11), 0402 neben MK2 |

J4 (xSYS2-Padfeld, Audit K2) ist DNP und steht nicht in der CPL.

## Nach dem Pin-Audit vom 02.10.2026 zusaetzlich zu pruefen

Die CPL ist aus dem Stand nach H1–H6 und den Entscheidungen vom 02.10.2026 neu erzeugt. **Sieben** Zeilen kommen hinzu (C110 ist DNP und steht nicht in der CPL). Y1 ist das einzige
Teil, bei dem die Drehung zaehlt: um 90° verdreht laegen die Quarzanschluesse (Pins 1/3) auf den
GND-Pads (2/4). Um 180° verdreht ist gleichwertig (der Quarz ist symmetrisch).

| Bauteil | Seite | Drehung | Mitte X / Y | LCSC | warum neu |
|---|---|---|---|---|---|
| **Y1** | oben | 270° | 118.3000 / -69.3000 | C49158179 | neue Nummer (JLYE Y201640MDBCX, ±10 ppm, Pin-Audit H1); Pin 1 oben links (Net-(U8-XTAL_N)), Pin 3 zu XTAL_P — JLYE-Datenblatt „Connection“: 1/3 Quarz, 2/4 GND. **Kein EasyEDA-Modell**, Bemerkung an JLCPCB: „Y1 orientation per silkscreen pin-1 corner mark (top-left)“ |
| **R72** | unten | 180° | 139.8100 / -82.1000 | C25798 | neue Nummer (75 kΩ statt 200 kΩ, H2) |
| **C17** | oben | 180° | 138.9700 / -73.1150 | C19702 | neue Nummer (10 µF statt 4,7 µF, H4); dieselbe Nummer wie C13/C18/C107 |
| **R81** | unten | 270° | 116.1000 / -84.9000 | C25744 | neu (H3), 0402 auf B.Cu neben U19 |
| **C63** | unten | 0° | 122.7550 / -60.7500 | C52923 | neue Nummer (1 µF statt 100 nF, U10-B1) |
| **C98** | unten | 180° | 139.8000 / -83.1000 | C1525 | neue Nummer (100 nF statt 1 µF, MPR121-Datenblatt) |
| **R35** | unten | 90° | 131.6000 / -60.6000 | C100510 | neue Nummer (LIZ Elec CR0402FF6800G, 680 Ω 1 %, statt C25130), Ersatz bei der Bestellung 02.10.2026 |

## Alle gepolten und mehrpoligen Bauteile

Spalte „Abgleich": Herkunft der Drehung. Zusaetzlich sind **alle** Zeilen am 02.10.2026 gegen
den EasyEDA-Footprint nachgerechnet (Abschnitt „Berichtigung").

| Bauteil | Seite | Drehung | Mitte X / Y (mm) | Pin 1 in der Vorschau (Netz) | Abgleich |
|---|---|---|---|---|---|
| AE1 | oben | 45° | 113.7747 / -66.9253 | unten links (Net-(AE1-Pad1)) | rev A1 |
| C89 | oben | 315° | 155.5934 / -110.5934 | oben links (PVDD) | rev A1, korrigiert |
| D3 | oben | 45° | 149.9606 / -69.5323 | unten links (GND) | rev A1 |
| D4 | oben | 45° | 149.2606 / -68.8323 | unten links (GND) | rev A1 |
| D5 | oben | 0° | 114.4502 / -81.4710 | links (ESP_3V3) | rev A1 |
| J1 | oben | 135° | 152.9000 / -65.8000 | unten (GND) | **NEU PRUEFEN** |
| J5 | oben | 225° | 160.8106 / -105.6288 | unten rechts (Net-(C86-Pad1)) | rev A1, korrigiert |
| J6 | oben | 270° | 157.9750 / -93.7810 | unten rechts (GND) | **NEU PRUEFEN** |
| LED1 | oben | 270° | 100.5202 / -89.0869 | oben rechts (GND) | rev A1, korrigiert |
| LED6 | oben | 90° | 171.1100 / -89.0668 | unten links (GND) | rev A1, korrigiert |
| MK1 | oben | 225° | 104.1227 / -82.3469 | rechts (Net-(MK1-DATA)) | rev A1 |
| MK2 | oben | 45° | 167.4438 / -96.0810 | links (Net-(MK2-DATA)) | rev A1 |
| POWER_IN1 | oben | 0° | 141.3104 / -120.2010 | oben rechts (GND) | rev A1, korrigiert |
| Q4 | oben | 180° | 157.0000 / -83.9000 | oben links (/Power/USB_EN_GATE) | **NEU PRUEFEN**, EasyEDA 02.10., korrigiert |
| R76 | oben | 0° | 156.4000 / -81.8000 | links (+14V) | **NEU PRUEFEN** |
| R77 | oben | 0° | 157.1000 / -80.8000 | links (/Power/USB_EN_GATE) | **NEU PRUEFEN** |
| R80 | oben | 0° | 154.7000 / -90.6900 | links (/LEDs/LED6_DOUT) | **NEU PRUEFEN** |
| SW1 | oben | 270° | 115.3000 / -85.0000 | oben rechts (ESP_RST) | rev A1 |
| SW2 | oben | 270° | 119.0200 / -85.0000 | oben rechts (ESP_BOOT) | rev A1 |
| U3 | oben | 270° | 122.0500 / -114.5625 | oben links (Net-(L1-Pad1)) | rev A1, korrigiert |
| U4 | oben | 0° | 153.4000 / -84.7000 | unten links (+5V) | rev A1, korrigiert |
| U5 | oben | 270° | 141.0000 / -75.9650 | unten links (+3V3) | **NEU PRUEFEN**, EasyEDA 02.10., korrigiert |
| U6 | oben | 180° | 135.7000 / -78.8600 | oben rechts (GND) | rev A1, korrigiert |
| U7 | oben | 270° | 112.9800 / -103.2300 | oben links (Net-(L2-Pad1)) | rev A1, korrigiert |
| U8 | oben | 90° | 124.4000 / -70.0000 | unten links (Net-(U8-LNA_IN)) | rev A1 |
| U9 | oben | 90° | 127.2000 / -60.3000 | unten rechts (/ESP32-S3R8/SPI_CS0) | rev A1 |
| U14 | oben | 270° | 136.2000 / -103.3000 | oben links (GNDA) | rev A1, korrigiert |
| U18 | oben | 0° | 124.8000 / -106.7000 | unten links (/Power/+5V_SW) | **NEU PRUEFEN**, EasyEDA 02.10., korrigiert |
| Y1 | oben | 270° | 118.3000 / -69.3000 | oben links (Net-(U8-XTAL_N)) | **NEU PRUEFEN** (neue Nummer C49158179, H1; kein EasyEDA-Modell, nach Bestueckungsdruck) |
| D1 | unten | 225° | 152.2606 / -64.3323 | oben rechts (GND) | rev A1 |
| D6 | unten | 270° | 138.4000 / -76.2000 | oben (Net-(U12-2Y)) | rev A1 |
| LED2 | unten | 90° | 125.2624 / -89.1135 | oben rechts (+5V) | **NEU PRUEFEN** |
| LED3 | unten | 90° | 132.2500 / -89.1000 | oben rechts (+5V) | **NEU PRUEFEN** |
| LED4 | unten | 90° | 139.2000 / -89.1000 | oben rechts (+5V) | **NEU PRUEFEN** |
| LED5 | unten | 90° | 146.1000 / -89.1000 | oben rechts (+5V) | **NEU PRUEFEN** |
| Q1 | unten | 180° | 137.3000 / -56.6000 | oben links (VBUS) | rev A1 |
| Q2 | unten | 270° | 123.0000 / -63.0000 | unten links (Net-(Q2-G)) | rev A1, korrigiert |
| Q3 | unten | 180° | 138.2800 / -94.5000 | oben links (Net-(Q3-B)) | rev A1 |
| U10 | unten | 180° | 137.8749 / -64.6003 | unten rechts (/XMOS/QSPI_D1) | rev A1 |
| U11 | unten | 90° | 127.2000 / -76.2000 | unten rechts (/XMOS/QSPI_CS_N) | rev A1 |
| U12 | unten | 180° | 135.0000 / -76.5000 | oben rechts (GND) | rev A1, korrigiert |
| U13 | unten | 180° | 132.9625 / -94.5000 | oben links (+5V) | rev A1, korrigiert |
| U15 | unten | 90° | 142.9000 / -83.6000 | unten rechts (/ESP32-S3R8/TOUCH_IRQ) | rev A1, korrigiert |
| U16 | unten | 0° | 121.5000 / -70.2500 | unten links (unconnected-(U16-D1+-Pad1)) | **NEU PRUEFEN**, EasyEDA 02.10., korrigiert |
| U19 | unten | 0° | 118.4500 / -84.4500 | unten rechts (GND) | **NEU PRUEFEN** |
| X1 | unten | 270° | 133.0000 / -59.5000 | oben links (Net-(U10-XIN)) | **NEU PRUEFEN** |

## Ungepolt oder 180°-symmetrisch

Widerstaende, Kondensatoren, Spulen und die beiden Taster. Hier ist die Drehung ohne
Bedeutung; zweipolige ungepolte Teile und SW1/SW2 zeigen gegenueber dem
EasyEDA-Footprint teils 180° Unterschied, was nicht geaendert wurde.

| Footprint | Bauteile |
|---|---|
| `BLM18PG121SN1D` | FB2 90°, FB4 90°, FB5 0° |
| `C_0402_1005Metric` | C5 180°, C16 180°, C24 90°, C26 0°, C27 180°, C28 270°, C29 180°, C30 90° (unten), C31 0°, C32 0°, C33 90° (unten), C34 90° (unten), C35 90° (unten), C36 0°, C37 180°, C38 90°, C39 90°, C40 90°, C41 0°, C42 90°, C43 90°, C44 270°, C45 0°, C46 0°, C47 180°, C48 90° (unten), C49 180°, C50 0°, C51 0°, C52 180°, C53 180°, C54 0° (unten), C55 0°, C56 0°, C57 270°, C58 180° (unten), C59 180°, C60 0°, C61 180° (unten), C62 180° (unten), C63 0° (unten), C65 180° (unten), C66 0° (unten), C67 0°, C68 270° (unten), C69 270° (unten), C70 270° (unten), C71 225°, C72 45°, C78 180°, C83 90°, C88 0°, C92 90°, C93 180° (unten), C94 180° (unten), C95 180° (unten), C96 180° (unten), C97 270°, C98 180° (unten), C99 0° (unten), C100 0°, C101 180° (unten), C103 0°, C104 90° (unten) |
| `C_0603_1608Metric` | C6 90°, C7 90°, C8 270°, C9 270°, C12 270°, C13 270°, C17 180°, C18 180°, C21 270°, C25 270°, C64 180° (unten), C74 180°, C75 180°, C76 180°, C77 180°, C80 270°, C82 270°, C90 90°, C91 90° |
| `C_0805_2012Metric` | C3 270°, C4 270°, C10 180°, C11 270°, C14 270°, C15 270°, C19 0°, C20 0°, C22 270°, C23 270°, C79 90°, C81 90°, C84 270°, C85 270°, C86 90°, C87 270° |
| `L_0402_1005Metric` | L3 270°, L4 90°, L5 270° |
| `L_Cenker_CKCS4020` | L1 90°, L2 90° |
| `L_Murata_DFE201610P` | L8 270° |
| `MTQH404030S100MBT` | L6 180°, L7 180° |
| `R_0402_1005Metric` | R1 315°, R2 225° (unten), R3 225° (unten), R5 135°, R7 180°, R8 180°, R9 180°, R14 180°, R15 180°, R20 0°, R21 0°, R22 180°, R24 0°, R27 0°, R28 0°, R29 270°, R30 270°, R31 180°, R32 90°, R33 180°, R34 180° (unten), R35 90° (unten), R36 180° (unten), R39 180° (unten), R40 0° (unten), R41 180° (unten), R42 0° (unten), R43 180° (unten), R44 180° (unten), R45 270° (unten), R46 270° (unten), R47 0° (unten), R48 180° (unten), R49 0° (unten), R50 180° (unten), R52 90° (unten), R53 180° (unten), R54 90° (unten), R55 180°, R56 90° (unten), R57 0°, R58 270° (unten), R59 135°, R60 315°, R62 45°, R63 315°, R65 90° (unten), R70 0°, R71 90°, R72 180° (unten), R73 180° (unten), R74 90°, R75 0°, R79 0° |
| `R_0603_1608Metric` | FB1 225° (unten), R11 0°, R12 270°, R13 90°, R17 0°, R18 270°, R19 90°, R67 180° (unten) |
| `R_0805_2012Metric` | R68 270°, R69 90° |
| `R_1206_3216Metric` | R66 90° |

## Einzelhinweise

* **Y1:** Auch fuer die neue Nummer C49158179 liefert EasyEDA keinen Footprint ("Component not
  found", 02.10.2026; vorher ebenso fuer C424431); **nicht abgleichbar**. Bei einem 4-Pin-Quarz
  vertauscht eine 90°-Drehung Quarz- und Masseanschluesse. Pin 1 (XTAL_N) muss oben links liegen,
  an der Ecke mit dem Winkel im Bestueckungsdruck. Bemerkung an JLCPCB: „Y1 orientation per
  silkscreen pin-1 corner mark (top-left)".
* **MK1/MK2:** EasyEDA teilt den Massering in vier Flaechen, unser Footprint hat einen
  Ring mit zwei Pads. Die Signalpads und die Schallöffnung decken sich; in rev A1 war
  das in der Vorschau richtig.
* **C89** (Polymer-Elko): Pad 1 ist **PVDD**, also der Plus-Anschluss. Die
  180°-Korrektur der Fabrication-Toolkit-Regel `^C_Elec_` ist zurueckgenommen.
* **J1** (USB-C): die vier Schirmlaschen sitzen in durchkontaktierten Langloechern.
  Pruefen, dass das Gehaeuse auf allen 24 Signalpads und den vier Laschen liegt.

Erzeugt mit `scratchpad/e6/h1_drehlagen.py` aus CPL und Platine; Berichtigung vom 02.10.2026
von Hand nach `werkzeug/easyeda_abgleich.py`, jede geaenderte Zahl dort nachgerechnet.

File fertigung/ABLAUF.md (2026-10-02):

<!--
SPDX-FileCopyrightText: 2026 marceldale
SPDX-License-Identifier: MIT
-->

# How this directory is generated

Everything in `fertigung/` is produced from the KiCad files by the scripts in `werkzeug/`.
Nothing here is edited by hand. Run the steps in this order from the project root; each one
overwrites its own output.

## Step zero: check the BOM fields

```bash
python fertigung/werkzeug/bom_pruefen.py .
```

**Run this before generating anything.** It exists because E7 found ten wrong or missing part
numbers, and none of them was visible to ERC, DRC or the schematic-parity check — those look at
nets, not at order fields. The worst of them would have fitted R76 and R77, the divider that sets
Q4's gate voltage, with **0 Ω links**, which is a short from +14 V to ground.

It checks six things: schematic against layout for every component (number and value); no
populated part without a number; no number hiding in a field no exporter reads (`LCSC`,
`Supplier Part`); one number under two different values; resistor-style MPNs or descriptions on
parts that are not resistors; and, for the Uniroyal `0402WGFxxxxTCE` numbers, the encoded value
against the value field. It exits non-zero if it finds anything.

One known-good exception is built in: `C221897` sits on SW1 and SW2 with the value fields "Reset"
and "BOOT" — the same button, labelled differently.

What it cannot do is check a number against its LCSC product page. It prints the list of all 86
numbers with their URLs and the components that use each one; that part is handwork, and it is
where the J6, R80, R76 and R77 errors were actually settled.

```bash
python fertigung/werkzeug/fertigung.py nest-mini-v2-drop-in-pcb.kicad_pcb nest-mini-v2-drop-in-pcb.kicad_sch fertigung
```

That one command produces the JLCPCB set: Gerbers and Excellon drill files in `gerber/`
(plus drill maps as PDF), `gerber_jlcpcb.zip` for upload, `BOM_JLCPCB.csv` and
`CPL_JLCPCB.csv`. It prints three things worth reading:

* **BOM zusammengefasst** — part numbers used by more than one value or footprint. Two are
  expected: `C383201` (Q1, Q2, Q4 — the same MOSFET on two footprint variants of SC-70-3)
  and `C221897` (SW1, SW2 — the same button, labelled Reset and BOOT). Anything else means
  a part number is on the wrong component; that is how the J6 and R80 errors were found.
* **ohne LCSC** — components with no part number. Must be empty.
* **in CPL, nicht in BOM / in BOM, nicht in CPL** — both must be empty.

Then the PCBWay set:

```bash
python fertigung/werkzeug/bom_einzeln.py . fertigung/werkzeug/bom_einzeln.csv
python fertigung/werkzeug/pcbway_bom.py fertigung/werkzeug/bom_einzeln.csv
python fertigung/werkzeug/pcbway_xlsx.py fertigung/werkzeug/bom_einzeln.csv fertigung/pcbway/BOM_PCBWay.xlsx
```

`pcbway_bom.py` fetches manufacturer, MPN, description and package for every part number from
JLCPCB's parts API and **compares the MPN against the schematic**. Two differences are known
and deliberate — the part number names what is actually ordered, the MPN field what the design
asked for:

| Part | Schematic | Ordered |
|---|---|---|
| J5 | TE 1775443-2 | TE 5-1775443-2 (C5162845), variant of the same series |
| D6 | RB521S30T1G | RB521S30T1G-DW (C27636108), packaging variant |

Any **third** difference is a finding, not noise. (Until the audit fixes of 1 Oct 2026 there were
four: L8 and C100 now carry the ordered part in the schematic — L8 Sunlord WPN201610U1R0MTY01,
Isat 3.0 A min / 3.5 A typ per the Sunlord catalogue; C100 is FH 0402CG121J500NT, 120 pF.)

The assembly drawing needs KiCad's own Python, because it plots through pcbnew:

```bash
"C:/Program Files/KiCad/9.0/bin/python.exe" fertigung/werkzeug/bestueckzeichnung.py nest-mini-v2-drop-in-pcb.kicad_pcb <scratch>/kopie.kicad_pcb
"C:/Program Files/KiCad/9.0/bin/python.exe" fertigung/werkzeug/bestueck_plot.py <scratch>/kopie.kicad_pcb <scratch>/plot
```

The two resulting PDFs are joined into `pcbway/Bestueckungszeichnung.pdf`. `bestueckzeichnung.py`
works on a **copy** — it adds designators, outlines, pin-1 dots and polarity marks to the Fab
layers and removes DNP parts, and none of that belongs in the design file.

Finally `pcbway/Positionen_KiCad.csv`, the plain KiCad position export, as a cross-check against
the CPL:

```bash
kicad-cli pcb export pos --format csv --units mm --side both --exclude-dnp --output fertigung/pcbway/Positionen_KiCad.csv nest-mini-v2-drop-in-pcb.kicad_pcb
```

## Before handing anything to a fabricator

1. **Run `bom_pruefen.py` and read the LCSC pages it lists.** See above.
2. Zones must be filled and the fill must be current. Check it, do not assume it: fill the zones
   in a copy and compare the filled areas against the saved ones. For the set generated after the
   production state (2 Oct 2026, after C110): 11 582.99 mm² over 15 zone layers (13 zones), saved and
   refilled equal. One zone (`+14V` on In2) can alternate between 147.28 and 147.32 mm² from one fill
   to the next — a fill-iteration effect, 0.03 %; the Gerbers are made from the saved state. (After the audit
   fixes of 1 Oct 2026 the total was 11 596.11 mm²; H6 perforates the `VDD` area on In2 under U10.)
3. Read `DREHLAGEN_PRUEFEN.md` and work through the **15 + 9 + 7 new rows** (rev A1 → A2, the
   audit fixes and the pin-audit fixes; Y1 is the one where rotation matters, and it has no model in the preview) in JLCPCB's
   assembly preview. Those are the parts whose LCSC number changed since rev A1, or that are new;
   for them the fabricator's own footprint decides the zero orientation, and nobody has compared
   it yet.
4. Read "Before you order" in `CHANGES.md` — seven points, including the 0.10 mm track width and
   the `IQ` variant of U11.
5. **Select the two order options.** They are not in the Gerbers; nobody will ask twice:
   * **Via covering: *Epoxy Filled & Capped*.** The board vias reach into **23 pads (58 vias, all same-net)**, measured after the pin-audit fixes of 2 Oct 2026: the via centre lies inside 14 pads — J6.11, R79.2, R80.1 (signal), C99.1, U11.6, L1.2 (supply), C47.2 and C60.2 (GND, on F.Cu above the U10 paddle, two of the H6 vias), and the large pads of U8 (9 vias) and U10 (32 vias: 16 GND, 4 in each VDD paddle) — and in 9 more pads part of the drilled hole reaches into the solder-mask opening (C65.1, J1.B6, J4.4, J4.6, LED2.1, TP21, TP22, U19.2, U19.4).
     An open via wicks solder out of the joint in reflow. Our vias are 0.30 mm drill / 0.40 mm
     diameter, inside the 0.15–0.55 mm range the process supports.
   * **Surface finish: ENIG.** 0.40 mm pitch on four parts, QFN thermal pads, the J4 spring-contact
     pad field, eighteen test points and three touch electrodes all want a planar finish. Exposed
     copper is 7.64 % of the board area, well under the 30 % above which JLCPCB adds an area
     surcharge.

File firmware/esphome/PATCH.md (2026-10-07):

<!--
SPDX-FileCopyrightText: 2026 marceldale
SPDX-License-Identifier: MIT
-->

# Local copy of `tas58xx` with a start-up patch

`components/tas58xx/` is the ESPHome external component
[mrtoy-me/esphome-tas58xx](https://github.com/mrtoy-me/esphome-tas58xx) at commit
`89f29cfd687200e908a6459404abfbb513adb17d` (branch `main`, the newest state on 1 Oct 2026),
copied unchanged in one commit and patched in the next, so `git diff` between the two shows the
patch exactly. `nest-mini-v2-voice.yaml` loads it with `external_components: source: type: local`.

## Why

The TAS5805M on this board is wired for PBTL (outputs 23+26 and 17+20 paralleled). The original
start-up writes a register table (`tas58xx_minimal.h`) that ends with

```
{ 0x02, 0x00 },   // DEVICE_CTRL_1: BTL
{ 0x54, 0x00 },   // AGAIN: 0 dB
{ 0x03, 0x03 },   // DEVICE_CTRL_2: PLAY
```

and only afterwards `configure_registers_()` sets PBTL (`set_dac_mode_`, DEVICE_CTRL_1 bit 2) and
the analog gain (`set_analog_gain_`, −12 dB). For that short time the amplifier plays in BTL at
full analog gain into paralleled outputs. The TAS5805M datasheet (SLASEH5D, 7.5.3.1 step 4) asks
for the device to be set into Hi-Z, configured, and only then put into PLAY.

## The patch

| File | Original | Patched |
|---|---|---|
| `tas58xx_minimal.h` | `{ 0x03, 0x03 }` (PLAY) at the end of the table | `{ 0x03, 0x02 }` (Hi-Z) |
| `tas58xx.h` | `ControlState tas58xx_control_state_;` — never initialised (the comment says "initialised in setup", `setup()` does not) | `ControlState tas58xx_control_state_{CTRL_HI_Z};` |
| `tas58xx_minimal.h` | `{ 0x53, 0x00 }` — class-D loop bandwidth 80 kHz | `{ 0x53, 0x60 }` — 175 kHz (pin audit U14-B2, added 2 Oct 2026) |
| `tas58xx.cpp` `update()` | every fault is cleared on the next 1 s update, DC and over-current included | DC and over-current faults (CHAN_FAULT bits 0–3) are not cleared; nothing is cleared while one is present, the output stays off until the device restarts (added 5 Oct 2026, as in the ESPHome core component; SLASEH5D 7.5.3.3.1/2: a DC fault re-trips only after 570 ms) |

With both, `configure_registers_()` runs: `set_deep_sleep_off_()` (no write, state is Hi-Z) →
`set_modulation_scheme_()` → `set_dac_mode_(PBTL)` → `set_analog_gain_(−12 dB)` →
`set_state_(CTRL_PLAY)`, which now writes PLAY because the state differs. Without the
initialisation, a random start value could equal `CTRL_DEEP_SLEEP` (then `set_deep_sleep_off_`
writes PLAY before PBTL) or `CTRL_PLAY` (then PLAY would never be written).

**Why 175 kHz (U14-B2).** Register 0x02 is 0x04 here (FSW_SEL = 000 = 768 kHz, PBTL, BD). The
datasheet's field description of ANA_CTRL (table 7-27) says "With Fsw=768kHz, 175kHz bandwidth should
be selected for high audio performance", section 7.3.8.2 says "Same Fsw, Better THD+N performance
with higher BW", and table 7-3 allows 175 kHz for BD at 768 kHz (rule Fsw ≥ 3 × BW: 768 ≥ 525 kHz).
The datasheet's PBTL curves are measured with exactly this set-up (768 kHz, 10 µH / 0.68 µF, BD,
175 kHz), and its example start-up script writes `w 58 53 60`. The value is written while the device
is still in Hi-Z. On the sample: read back 0x53 (expect 0x60) and compare THD+N before/after.

Not changed: the undocumented register `0x46 = 0x01`, whose source comment says "SR 96KHz; for
48KHz use 0x11" while this bus runs at 48 kHz. TI lists the address as reserved; the effect has to
be checked on the sample (read back register 0x71 for clock errors) before touching it.

## Licence

The upstream repository has no licence file. Its README states that the component is based on
work by Andriy Malyshenko (sonocotta) licensed under GPL-3.0, so the copy is distributed here under
**GPL-3.0-or-later** (`LICENSES/GPL-3.0-or-later.txt`), with mrtoy-me and Andriy Malyshenko named as
authors and our two modifications marked with a dated notice at the top of each changed file
(GPL-3.0 section 5 a). The assignment is in `REUSE.toml`. This file (`PATCH.md`) is our own text, MIT.

The same change was submitted to the upstream repository as PR #4. Status: PR #4 closed; per maintainer's comment in mrtoy-me/esphome-tas58xx#4 the start-up order is covered by his development branch and by the ESPHome core driver (esphome/esphome#19971).

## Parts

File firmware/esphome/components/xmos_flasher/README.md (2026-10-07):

<!--
SPDX-FileCopyrightText: 2026 marceldale
SPDX-License-Identifier: MIT
-->

# `xmos_flasher` — write the XU316 factory image from the ESP32

The XU316 boots from its own SPI flash U11 (W25Q32JVSSIQ), which is **empty as delivered**. Once an
image is in it, `voice_kit` keeps it current over I²C (DFU). This component fills an empty or damaged
U11 from the ESP32-S3, without a JTAG adapter: it writes `firmware/xmos/ffva_v1.3.1_factory.bin`
(286 720 bytes) over the bus switch U16, verifies it and restarts.

## Operation (Home Assistant)

1. Supply the board from USB or from 14 V (base plate or bench supply at TP18); see "Supply" below.
   The device must have been up for 30 s, and its last restart must not have been a brown-out.
2. Switch on **"XMOS-Flash freigeben"** (configuration entity). It switches itself off after 60 s.
3. Press **"XMOS-Flash schreiben"** within those 60 s. The wake word, the voice assistant and media
   playback are stopped first.
4. Watch **"XMOS-Flash Status"** (`connect` → `identify` → `erase` → `write` → `verify` → `done`) and
   **"XMOS-Flash Fortschritt"** (%). It takes about 15 s (erase 256 × 45 ms typical, 1 120 pages of
   about 1.5 ms, 1 MiB read back at 4 MHz); each `loop()` call works for up to 20 ms, so the write is
   not paced by ESPHome's 16 ms loop interval.
5. On success the ESP32 restarts after 3 s; the log must then show `[voice_kit] DFU version: 1.3.1`.
   On failure the status reads `failed: <stage> <reason> at 0x<address>`, the bus is released and the
   XU316 is let out of reset; nothing restarts. Pressing the button again repeats the whole write.

Nothing happens at start-up: the component only acts on the button.

## What it does on the bus

| Step | Action | Evidence |
|---|---|---|
| connect | GPIO46 high: Q2 pulls `RST_N` low (XU316 in reset) **and** U16 connects D± to its 2D side (`S` = 1, `OE` = GND), so GPIO39 reaches `QSPI_CS_N` and GPIO40 `QSPI_D1`. 10 ms settle. SPI2 is set up on GPIO3 (CLK), GPIO4 (MOSI = D0), GPIO40 (MISO), GPIO39 (CS), mode 0, 4 MHz. | Netlist: `XU316_RST` = U8.52 GPIO46, R47, U16.9 S, TP11; `QSPI_CLK` = U8.8, U11.6, U10.5; `QSPI_D0` = U8.9, U11.5, U10.59; `XMOS_SPI_CS_N` = U8.44, U16.8; `XMOS_SPI_MISO` = U8.45, U16.7; U16.3/4 = `QSPI_CS_N`/`QSPI_D1`. TS3USB221 table 7-1: OE low, S high → D = 2D. In reset the XU316's GPIOs are inputs with weak pull-downs (XU316 datasheet section 8). |
| identify | First 16 clocks of FFh (ends a continuous-read mode the XU316 may have left), wait while BUSY (an interrupted DFU erase/program), then 66h + 99h software reset (tRST 30 µs) — never during BUSY, the datasheet warns of data corruption. Then 9Fh must return **EF 40 16**; 35h is read and **QE must be 1** (the IQ part has QE fixed at 1; with QE = 0 `/HOLD` would be active and is pulled low by the XU316 in reset). SR1 BP0–2/TB/SEC and SR2 CMP must be 0 (otherwise erase/program would be ignored silently) — the status registers are never written, a protected flash is reported, not unlocked. | W25Q32JV datasheet: JEDEC ID table, QE bit S9 ("factory fixed default for … IQ"), section "Enable Reset (66h) and Reset Device (99h)", block-protect bits. |
| erase | 06h + 05h (WEL must be set), 20h for each 4 KiB sector of the **whole 1 MiB boot partition** (256 sectors), busy-polled with 05h, 1 s timeout per sector. The data partition above 1 MiB is not touched. | tSE 45 ms typ / 400 ms max. Boot partition 0x100000 as the image was built (`firmware/xmos/README.md`). |
| write | One 256-byte page per loop: 06h, 02h, busy-poll (10 ms timeout), then 03h read-back and byte compare. The last page is padded with FFh. | tPP 0.4 ms typ / 3 ms max; 03h up to fR = 50 MHz. |
| verify | 03h over the whole boot partition, 4 KiB per loop: MD5 of the first 286 720 bytes against `MD5SUMS`, and every byte after the image must be FFh (no stale upgrade image). | |
| release | SPI bus freed, **GPIO3/4/39/40 back to floating inputs first**, then GPIO46 low: U16 isolates CS/MISO and the XU316 boots from U11. On success the ESP32 restarts (`App.safe_reboot()`), so `voice_kit`, the microphones and the amplifier come up in their normal order. | |

The image is **embedded at compile time** (`image_file`, `md5_file` in the YAML). The build fails if
its MD5 does not match `MD5SUMS` or if it does not fit the boot partition. There is no download at
run time. Cost: firmware image 2 283 639 → 2 600 735 bytes (32.0 % of an 8 MB OTA slot).

## Limits

* No lock against a running `voice_kit` DFU update or against automations that restart the wake word
  during the write: the flash is not at risk (the XU316 is in reset, the ESP owns the bus), but a DFU in
  progress is aborted and audio components log errors until the restart.
* The SPI pins are given as plain numbers, so ESPHome does not flag a second use of GPIO3/4/39/40 in the
  YAML; keep them free (the YAML comment lists them as reserved).
* After a failure the wake word stays stopped until the next restart.

## Supply: USB alone or 14 V

Since 2 Oct 2026 the write is allowed on **USB alone** as well as on 14 V (operator's decision; before
that it was refused without PVDD). Conditions, checked in the YAML before the button is accepted:

* **`+5V` present.** The board has no voltage sensor for `+5V` or VBUS that the ESP32 can read — the
  only VBUS sense (`VBUS_DETEC`, Q1) goes to the XU316 (X1D09), which is held in reset while writing.
  The check is therefore one of plausibility: the ESP32 runs from `+5V` through U7, has been up for at
  least **30 s** with Wi-Fi (transmit bursts) and its last restart was **not a brown-out**
  (`esp_reset_reason() != ESP_RST_BROWNOUT`). During the write the load is lower than in that
  operation (table below), so a supply that carried it carries the write. That `+5V` (TP17) is above
  4.5 V is measured once at bring-up (USB alone: TP17 ≈ VBUS − I × 50 mΩ, AP22802 R_DS(on)).
* **All LEDs off** while writing: switched off before the write starts and held off by a 250 ms
  `interval` for as long as `xmos_flasher.in_progress` is true (touch feedback included).

**Load during the write**, from `+5V` (U7 and U6 efficiency taken as 90 % and 85 % — an assumption, not a
datasheet figure for this operating point):

| Consumer | Datasheet | from `+5V` |
|---|---|---|
| ESP32-S3R8, Wi-Fi connected (receive) | RX 88 mA (ESP32-S3 datasheet v2.2, table 5-8, CPU idle) | 65 mA |
| ESP32-S3R8, CPU busy (SPI, MD5) | + 33 mA (table 5-9: dual core 66.2 mA against WAITI 32.9 mA at 240 MHz) | 24 mA |
| ESP32-S3R8, transmit burst | TX 802.11b at 21 dBm, 340 mA peak (table 5-8); the YAML sends at 8.5 dBm | + 185 mA peak |
| U11 W25Q32JV, page program / sector erase | I_CC5 page program / I_CC6 sector erase **25 mA** max., 20 mA typ. (W25Q32JV datasheet rev. G, DC electrical characteristics) | 18 mA |
| rest of `3V3` (U9 flash, VDDIO, `1V8`, MPR121, TAS5805M DVDD) | flash 10 mA, DVDD 18 mA (SLASEH5D 6.5), rest estimated 20 mA | 35 mA |
| XU316 core `VDD` 0.9 V, **in reset** | no reset figure in the datasheet; bounded by I(VDD) typ. 300 mA running (XM014429B fig. 36) | ≤ 64 mA |
| microphones `VMIC` | a few mA (10 mA taken) | 10 mA |
| LEDs | off | 0 |
| amplifier | stopped; PVDD absent on USB | 0 |
| **Sum** | | **≈ 0.22 A typical, ≈ 0.40 A with a transmit burst — below 0.5 A** |

U4 (current limit ≥ 2.2 A, AP22802) and U18 (1.5 A) are far above this. A USB 2.0 port without power
negotiation supplies 500 mA, a USB 3.x port 900 mA; the receptacle presents 5.1 kΩ on CC (R1/R5).

## Origin and licence

Derived from **FutureProofHomes/Satellite1-ESPHome** (commit `8f8906c`, 2 Oct 2026), components
`memory_flasher` and `satellite1/memory_flasher` (`xmos_flashing.cpp/.h`) by Mischa Siekmann. That
repository is under the ESPHome licence: C/C++ files under **GPLv3**, Python under **MIT**. It does
not say "or any later version", so the C++ files here are marked **GPL-3.0-only** (not "or later")
and `__init__.py` **MIT**, both naming the original author.

Taken over: the stage machine run from `loop()` one bounded step at a time; page program with WEL
check, busy poll and read-back compare; padding of the last page with FFh; MD5 over the written image
against the expected value; JEDEC check before writing; image embedded as a PROGMEM array with a
compile-time MD5 check; progress weighting by time rather than bytes.

Changed for this board (the line-by-line comparison is in the project's working notes):

* **Bus access.** Satellite1 switches all lines through its own bus and stays an `spi` device of its
  hub. Here CLK and D0 are wired permanently to the XU316, so the SPI bus exists only during a write
  and the pins are returned to floating inputs before the XU316 leaves reset. One GPIO (46) does reset
  and switching together.
* **Erase range.** Satellite1 erases the image sectors plus one (the upgrade-header sector). Here the
  whole 1 MiB boot partition is erased and verified as FFh after the image, because the target is an
  empty *or damaged* flash.
* **Verification.** Satellite1 hashes the stream it writes and keeps a persistent record. Here the
  flash is read back after writing and the MD5 is taken from the flash itself, plus the FFh tail.
* **Not taken over:** remote (HTTP) images, full-chip erase, factory-reset action, the persistent
  resume record across reboots and the unique-ID check. A write interrupted by a power loss leaves an
  invalid image; the remedy is simply to press the button again (the XU316 then fails its version
  read, and `voice_kit` reports it).
* Read with 03h instead of 0Bh (fast read); 4 MHz default instead of the hub's SPI clock.

## Files

| File | Licence |
|---|---|
| `xmos_flasher.h`, `xmos_flasher.cpp` | GPL-3.0-only (derived) |
| `flash_plan.h` | GPL-3.0-only (constants and `static_assert` checks) |
| `__init__.py` | MIT (derived) |
| `README.md` | MIT |
| `../../tests/test_xmos_flasher.py` | MIT — host test against a simulated W25Q32JV |

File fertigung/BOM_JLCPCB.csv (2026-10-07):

Comment | Designator | Footprint | LCSC Part #
2450AT18A100E | AE1 | Johanson_2450AT18x100 | C89334
22uF | C3,C10,C14,C22,C79,C81,C84,C85 | C_0805_2012Metric | C45783
10uF | C4,C15 | C_0805_2012Metric | C15850
10nF | C5,C16 | C_0402_1005Metric | C15195
4.7uF | C6,C80,C90 | C_0603_1608Metric | C19666
100nF | C7,C8,C25,C82,C91 | C_0603_1608Metric | C14663
220pF | C9,C21 | C_0603_1608Metric | C156398
100nF | C11,C19,C23 | C_0805_2012Metric | C49678
2.2uF | C12,C64 | C_0603_1608Metric | C23630
10uF | C13,C17,C18,C107 | C_0603_1608Metric | C19702
4.7uF | C20 | C_0805_2012Metric | C1779
1uF | C24,C31,C35,C39,C44,C53,C63,C68,C78 | C_0402_1005Metric | C52923
12pF | C26,C27,C29 | C_0402_1005Metric | C1547
1.2pF | C28 | C_0402_1005Metric | C327292
100nF | C30,C32,C33,C34,C37,C38,C41,C42,C43,C45,C46,C47,C49,C50,C51,C52,C55,C56,C57,C58,C59,C60,C61,C62,C65,C66,C67,C69,C70,C71,C72,C92,C93,C94,C95,C96,C97,C98,C99,C101,C103,C104,C106,C108,C109 | C_0402_1005Metric | C1525
2.4pF | C36 | C_0402_1005Metric | C48346
10uF | C40 | C_0402_1005Metric | C15525
20pF | C48,C54 | C_0402_1005Metric | C1554
0.22uF | C74,C75,C76,C77 | C_0603_1608Metric | C107083
100nF | C83,C88,C105 | C_0402_1005Metric | C307331
0.68uF | C86,C87 | C_0805_2012Metric | C107133
220uF | C89 | C_Elec_6.3x7.7 | C46550464
120pF | C100 | C_0402_1005Metric | C40059
TPD1E10B06DPYR | D1 | TPD1E05U06DPYR | C48260
PESD0402V05 | D3,D4 | D_0402_1005Metric | C19626254
LRB520S-30T1G | D5 | D_SOD-523 | C83680
RB521S30T1G | D6 | DIOM168X70N | C27636108
30R | FB1 | R_0603_1608Metric | C17305
120R | FB2,FB4 | BLM18PG121SN1D | C14709
600R | FB5 | BLM18PG121SN1D | C85833
usb_c | J1 | USB-C-SMD_TYPE-C-USB-18 | C134092
1775443-2 | J5 | 1775443-2 | C5162845
FH34SRJ-12S-0.5SH(50) | J6 | HRS_FH34SRJ-12S-0.5SH_50_ | C424659
2.2uH | L1,L2 | L_Bourns_SRP4020TA | C719179
3.3nH | L3 | L_0402_1005Metric | C16526
2.7nH | L4 | L_0402_1005Metric | C434826
2.2nH | L5 | L_0402_1005Metric | C162540
10uH | L6,L7 | MTQH404030S100MBT | C51883185
1uH | L8 | L_Murata_DFE201610P | C395545
SK6812D-EC3210R | LED1,LED6 | LED-SMD_4P_SK6812D-EC3210R | C2890041
SK6812-EC20 | LED2,LED3,LED4,LED5 | SK6805-EC20 | C2909058
MMICT390200012 | MK1,MK2 | MIC_T3902 | C3171752
FH34SRJ-10S-0.5SH_50_ | POWER_IN1 | HRS_FH34SRJ-10S-0.5SH_50_ | C324723
LBSS138WT1G | Q1,Q2,Q4 | SC-70-3_L2.1-W1.3-P0.65-LS2.1-BR / SOT-323_SC-70 | C383201
BC847B | Q3 | SOT-23 | C20069135
5.1k | R1,R5 | R_0402_1005Metric | C25905
22R | R2,R3 | R_0402_1005Metric | C25092
0R | R7,R14,R22,R24,R27,R28,R29,R30,R31,R40,R42,R43,R44,R45,R46 | R_0402_1005Metric | C17168
100k | R8,R9,R15,R41,R75 | R_0402_1005Metric | C25741
49.9R | R11,R17 | R_0603_1608Metric | C23185
210k | R12 | R_0603_1608Metric | C22952
40k | R13 | R_0603_1608Metric | C861392
68.1k | R18 | R_0603_1608Metric | C25976
22.1k | R19 | R_0603_1608Metric | C25961
10k | R20,R21,R49,R58,R79,R81 | R_0402_1005Metric | C25744
4.7k | R32,R33,R50,R70 | R_0402_1005Metric | C25900
1M | R34,R73,R76 | R_0402_1005Metric | C26083
680R | R35 | R_0402_1005Metric | C100510
47k | R36,R52,R65,R71 | R_0402_1005Metric | C25792
100R | R39,R47,R55,R56,R59,R60,R62,R63,R80 | R_0402_1005Metric | C25076
470k | R48,R54 | R_0402_1005Metric | C25790
3.3k | R53 | R_0402_1005Metric | C25890
1k | R57 | R_0402_1005Metric | C11702
0R | R66 | R_1206_3216Metric | C17888
0R | R67 | R_0603_1608Metric | C21189
0R | R68,R69 | R_0805_2012Metric | C17477
75k | R72 | R_0402_1005Metric | C25798
51k | R74 | R_0402_1005Metric | C25794
330k | R77 | R_0402_1005Metric | C25778
Reset / BOOT | SW1,SW2 | SW-SMD_4P-L4.2-W3.2-P2.15-LS4.5 | C221897
TPS62130 | U3,U7 | VQFN-16-1EP_3x3mm_P0.5mm_EP1.68x1.68mm_ThermalVias | C337502
AP22802AW5-7 | U4 | SOT-23-5 | C211404
TLV70018DCKR | U5 | SOT65P210X110-5N | C133796
TPS62065DSGR | U6 | Texas_DSG0008A_WSON-8-1EP_2x2mm_P0.5mm_EP0.9x1.6mm | C398352
ESP32-S3R8 | U8 | QFN40P700X700X90-57N | C2913194
W25Q128JVSIQ | U9 | SOIC-8_5.3x5.3mm_P1.27mm | C97521
XU316-1024-QF60B-C24 | U10 | XU316-1024-QF60B-C24 | C6617472
W25Q32JVSSIQ | U11 | SOIC-8_5.3x5.3mm_P1.27mm | C179173
SN74LVC125APWR | U12 | SOP65P640X120-14N | C7813
TLV73333PDBVR | U13 | TLV73333PDBVR | C134139
TAS5805MPWPR | U14 | TAS5805MPWPR | C478472
MPR121QR2 | U15 | MPR121QR2 | C91322
TS3USB221ERSER | U16 | TS3USB221ERSER | C129313
LM66100DCK | U18 | SOT-363_SC-70-6 | C2869734
74AHCT1G125 | U19 | SOT-353_SC-70-5 | C12495
24MHz 12pF | X1 | X4-SMD-2.0X1.6MM | C252273
40MHz | Y1 | Crystal_SMD_2016-4Pin_2.0x1.6mm | C49158179

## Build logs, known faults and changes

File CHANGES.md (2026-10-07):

# Changes relative to upstream

This design is a modified version of **[iMike78/nest-mini-drop-in-pcb](https://github.com/iMike78/nest-mini-drop-in-pcb)**.
The upstream design is licensed under the **CERN-OHL-S v2** (see `LICENCE`), and this
modified version is licensed under the same licence.

This file is the modification notice required by CERN-OHL-S v2 section 3.3(b).

Some entries point to the maintainer's working notes (`AENDERUNGEN.md` with its section numbers,
`AUDIT_REV_A2.md`, "the project notes"). **These notes are not published.** Each statement in this
file therefore carries its own evidence — datasheet page, source file and line, or a figure measured
on the design files in this repository — and the pointer only says where the work was logged.

| | |
|---|---|
| Upstream base | commit `7de6eec6` ("v2 hardware", 2026-05-16) |
| Modified by | marceldale, 2026-09-19 to 2026-10-02 |
| Tools | KiCad 9.0.9 (ERC/DRC/netlist via `kicad-cli`); ESPHome 2026.9.0 for the firmware configuration |
| Status | **Not yet manufactured or tested.** Every change below is verified on paper only: netlist, ERC, DRC and datasheets. None has been verified on hardware. |

## How each change was checked

For every change we compared the netlist before and after, ran ERC, and ran DRC with
schematic parity. The final state of the design is:

* **DRC: no errors, no unconnected pads, schematic parity clean.** 249 parts (including the
  unpopulated C110), 196 nets (after the decisions of 2 Oct 2026, section 11).
* **Eight warnings remain, all of them understood:**
  * Seven `hole_to_hole` at via pairs 0.500 mm apart, which leaves 0.200 mm between the
    0.300 mm holes against KiCad's 0.2495 mm setting. All seven pairs are **same-net**
    vias on `+14V` (3 pairs), `+5V`, `+3V3`, `ESP_3V3` and `PVDD` (one each), and JLCPCB's limit for same-net vias is exactly
    **0.2 mm**, so these are at the limit but inside it. They come from upstream.
  * One `connection_width` of 0.0864 mm in the `GND` zone on B.Cu, at 98.700 / 54.500 — a
    point **50.7 mm from the board centre**, so outside the 34.600 mm board outline. It is a
    neck in a part of the zone that the board edge cuts away; nothing is manufactured there.
* **No DRC exclusions.** The four that rev A1 needed are gone: the three
  `copper_edge_clearance` findings at the touch-electrode rings were solved by pulling the
  rings back from the hole edge (E5b.2), and `courtyards_overlap` J3/J4 went with J3 (E3).
* **No silkscreen warnings.** The 23 that rev A1 carried were worked off one by one in E5b.5.
* ERC reports **66** messages. **None of them is a circuit error** — they break down as:

  | Kind | Count | What it is |
  |---|---|---|
  | `power_pin_not_driven` | 21 | no `PWR_FLAG` on rails that are fed from a connector or a regulator whose output pin is not typed as a power output. Cosmetic. |
  | `unconnected_wire_endpoint` | 18 | wire stubs on the **root sheet**, left over from parts removed in E1, E5.1, E5.4 and E5.5. Cosmetic; they carry no net. |
  | `pin_to_pin` | 14 | 12 are "Unspecified meets Passive" from upstream symbols whose pins have no type. **Two are errors and both are deliberate**: U14 pins 26/23 (OUT_A+/OUT_A−) and 17/20 (OUT_B+/OUT_B−) are tied together because the TAS5805M runs in **PBTL** (datasheet figure 8-9) — the two bridges in parallel into one 4 Ω driver. That is the intended wiring, and ERC has no way to know it. |
  | `label_dangling` | 6 | labels with nothing on them: `XMOS_USB_P`/`XMOS_USB_N` (left from U2, removed in E1), `XL_DN0`/`XL_DN1` (left from R37/R38, E5.4), `SPI_CS_N`, `MIC_DATA_2`. |
  | `global_label_dangling` | 2 | `I2C2_SCL`, `I2C2_SDA` — a second I²C bus that this board does not use. |
  | `same_local_global_label` | 2 | `I2C_SCL` and `I2C_SDA` exist as both a local and a global label on the ESP32 sheet. Same net either way. |
  | `multiple_net_names` | 2 | `GNDA`/`DGND` at U14 (the amplifier has one ground reference, which is intended) and `I2S_DIN_SEC`/`I2S_DOUT` on the XMOS sheet. |
  | `pin_not_driven` | 1 | LED2's `DIN` is fed from LED1's `DOUT`, but LED1's symbol types its pins as *Unspecified* while LED2's types them properly. A symbol-library difference, not a wiring one. |

  The 26 messages in the first four rows that are **left-over artefacts** (6 dangling labels,
  2 dangling global labels, 18 wire stubs) sit on the root sheet and are worth cleaning up in
  the editor; they change nothing electrically. Everything else is either a property of the
  upstream symbols or, in the case of the two PBTL errors, the design working as intended.

---

## 1. Audio reference path and clocking (XU316 ↔ I²S)

**Why:** The firmware runs the ESP32 as I²S clock *secondary* and expects the XU316 to
generate the word clock and bit clock. On the board, however, the XU316 was not connected to
the I²S bus that feeds the amplifier. As a result, nobody generated the I²S clocks: no audio,
and no echo-cancellation reference.

**What:** We connected the XU316 to the I²S bus.

| Measure | Change | Commit |
|---|---|---|
| C1 | XU316 X1D01 (pin 10) → `I2S_LRCK` (tap at R29). The fan-out of pad 8 (VDDIO) and pad 9 (X1D00) was re-routed to make room. | `f6ecf19` (schematic), `09bdf3d`, `c01c038` (layout) |
| C2 | X1D10 (pin 13) → `I2S_BCLK` (tap at R30) | `64e04b1` |
| C3 | X1D34 (pin 53) → `I2S_DIN_ESP` (tap at R25). R25 was first set DNP, so ESP32 GPIO11 no longer drove the same net; in E5c-P5 **R25 was removed from the design altogether** and X1D34 (U10.53) now carries an explicit **no-connect**. **Superseded by E5d — see the note below.** | `bee3bd9`, `2d0813b` |
| C4 | X1D11 (pin 14) → `I2S_MCLK` | `1a7fdb9` |
| C6 | R23 and R26 were first set DNP, which separates ESP32 GPIO9 and GPIO12 from the MCLK node; in E5c-P5 **R23, R25 and R26 were removed from the design** — symbols, pads and stubs — because their pads walled in the east region. R24 (populated) stays, and so does R31 (X1D11 ↔ X0D36). No MCLK pin is used in the firmware. | `fed148e` |
| C7 | XU316 reset `XU316_RST` moved from ESP32 GPIO17 (U8.23) to **GPIO46** (U8.52), to match the routing. There was no via space for GPIO17 next to `AUDIO_PA_EN`. | `3dc22d3` |

**Correction to C3 (rev A2, E5d, 28.09.2026):** C3 gave the amplifier its I²S data from the
XU316 (X1D34 → `I2S_DIN_ESP` → U14.8/SDIN). That makes audio depend on the XU316 firmware
forwarding the stream. E5d moves U14.8 to `I2S_DIN_SEC` instead, so the amplifier now takes its
data straight from the ESP32:

    GPIO10 → R24 (0R, fitted) → I2S_DIN_SEC → U14.8 (SDIN)
                                             └→ R40 (0R, fitted) → X1D00 (XU316, AEC reference)

The clocks are unchanged and still come from the XU316 (C1: X1D01 → `I2S_LRCK`,
C2: X1D10 → `I2S_BCLK`). After E5d, X1D34 (U10.53) drives no target. R25 was removed in E5c-P5,
and U10.53 carries an explicit no-connect. `I2S_DIN_SEC` keeps its name on purpose, because it
still describes its source (the ESP32's second I²S peripheral). The net `I2S_DIN_ESP` no longer
exists.

**Why X1D34 stays a no-connect (E5d-N, 30.09.2026):**

* **Voice PE:** X1D34 goes through **R73 (0R, fitted)** to the AIC3204 input `DIN/MFP1`. ESP32
  GPIO11 also reaches that net, through R97 (0R, fitted).
* **The Voice PE firmware does not use that input.** ESPHome sets up the AIC3204 so that it
  takes its playback data on `SCLK/MFP3`, which is `I2S_DIN_SEC` from GPIO10
  (`aic3204.cpp`, lines 40–43). The XU316 firmware (ffva v1.3.1) writes no playback data to
  X1D34 at all: in `voice-kit-xmos-firmware` v1.3.1 the only `rtos_i2s_tx()` call on the playback
  bus is commented out (`src/ffva/src/main.c`, line 208) and the TDM branch is disabled
  (`appconfI2S_TDM_ENABLED 0`), so the output port 1K on X1D34 (`NC-VOICE-KIT.xn`, lines 50–65)
  only ever sends an empty buffer.
* **The TAS5805M has no equivalent.** It has a single SDIN, which now sits on `I2S_DIN_SEC`. A
  DNP resistor from X1D34 would therefore serve no purpose.
* **An XMOS-fed amplifier ("path F")** would need a modified XU316 firmware *and* a layout change.

Logged in the working notes (AENDERUNGEN, sections 83a and 100).

**Evidence:**

* The XU316 ports X1D01, X1D10, X1D11 and X1D34 are the ones the Home Assistant Voice PE
  (same ESP32-S3 + XU316 combination) uses for this I²S bus.
* **C7 strapping:** ESP32-S3 datasheet v2.2, Tab. 3-1 and 3-3. GPIO46 has a weak pull-down,
  and R48 (470 kΩ to GND) holds it low at reset.

## 2. Power

| Measure | What | Why | Evidence | Commit |
|---|---|---|---|---|
| A1 | 0.9 V core supply of the XU316 changed from LDO **TPS7A0309 (U6, SOT-23-5)** to a buck converter **TPS62065DSGR** (WSON-8) with 1 µH (L8), divider 51 k / 100 k (R74/R75), 22 pF feed-forward (C100; 120 pF since audit fix M2). C13/C18/C20 are now 10 µF (C20 4.7 µF since M2). | The LDO is rated 200 mA (TPS7A03 datasheet), while the XU316 core draws about 225–300 mA (XU316 datasheet). The LDO would also dissipate about 0.5 W in a SOT-23-5. The Voice PE also uses a buck converter for this rail. | TPS62065 datasheet: Vout = 0.6 V × (1 + 51/100) = 0.906 V; XU316 VDD range 0.855–0.945 V | `daf86a4`, `3ff45d1`, `ec8229c`, `9600d92`, `2506c3c`, `9f279f2`, `3c7bb45` |
| A2 | DEF pin of both TPS62130 (U3, U7) to GND through 0 Ω (R7, R14; previously 100 k); PG pull-ups R10/R16 DNP (PG left open) | On U3, DEF and PG were pulled up to +14 V through 100 kΩ, but their absolute maximum is 7 V. DEF high also raised both outputs by 5 %, to 5.25 V and 3.43 V, leaving 0.17 V margin to the ESP32-S3's 3.6 V limit. PG is not used. | TPS62130 datasheet (TI SLVSAG7F) sections 7.1 and 8.3; after the change +5V = 5.00 V and +3V3 = 3.27 V | `7ac93e5` |
| — | Three GND vias for ground islands without a via to the plane (at C25/C70 and two on B.Cu); one dangling via on `LED1-DOUT` removed | Found by filling the zones: isolated copper | DRC on the filled copy shows no islands | `0dcb0e5` |
| A1b | **FB3 removed**: the 600 Ω ferrite bead between the converter output and `VDD` is gone, `+0V9` and `VDD` are now one net (named `VDD`), and the 1.47 mm gap is closed with a 0.80 mm track on F.Cu. C13/C18/C20 stay. This also puts the converter's feedback (R74) on the same net as the XU316's VDD pins. | The bead's DC resistance eats the core rail's margin. See the table below. | Worst-case VDD at 830 mA: 0.746 V with the bead, 0.829 V with a 0 Ω link, **0.871 V without** — against a lower limit of 0.855 V | this commit |

| E5.2 | **U5 changed from MIC5365-1.8 to TLV70018DCKR** (LCSC C133796). Type, value,
manufacturer and part number only — the footprint stays. | The MIC5365 had no stocked part number;
the TLV70018 is a current TI part in the same package and is pin-compatible. | TI TLV700 datasheet
(SLVSA00E): the **DCK** suffix is SC70-5, which is the footprint already in use — not the DBV
(SOT-23-5) variant. Pin order IN/GND/EN/NC/OUT is the same in both (Micrel MIC5365/6 Rev. 3.1, pin
description p. 5; TI TLV700 SLVSA00E, pin functions p. 4). U5 runs from `+3V3` with `EN` tied high
and feeds **`+1V8`** — the XU316's VDDIOB18 bank (U10 pins 17, 26 and 31), the JTAG reference on
J4.6 and TP4. The swap raises the rating from 150 to **200 mA**, lowers the minimum input from 2.5
to 2.0 V and gives 85 mV dropout at 100 mA; the 1 µF in and out stay as they are. The land pattern
was checked against TI drawing DCK0005A (4214834/G, 11/2024): pitch 0.650 mm and pad width
0.400 mm match to the hundredth. | `737b487` |

**L8, the inductor of that converter, checked against the manufacturer's datasheet.** The
design asks for 1 µH at **≥ 2 A** saturation. The ordered part is not the Murata the design
names: LCSC C395545 is the **Sunlord WPN201610U1R0MTY01**, and LCSC publishes no product page for
that number, so the figures had to come from the manufacturer. From the Sunlord WPN datasheet,
table *WPN201610U Series*:

| | |
|---|---|
| Saturation current `Isat` | **3.60 / 3.80 A** |
| RMS current `Irms` | 3.10 / 3.40 A |
| DC resistance | 0.05–0.06 Ω |
| Self-resonant frequency | 63 MHz |

**The ≥ 2 A requirement is met with margin.** `Irms` also covers the 1 A peak the XU316 core
draws under DSP load. The Murata DFE201610P-1R0M the design was dimensioned around has 3.1 A and
70 mΩ, so the ordered part is equal or better in every figure that matters here.

**Checked, no change needed:**

* **A3:** All input capacitors on +14 V / PVDD are rated ≥ 25 V. This is why C83 and C88 keep
  the 50 V part instead of being merged into the 16 V one — see section 7.
* **A5:** D1 is fixed as TPD1E10B06DPYR (C48260). The value field and the footprint name disagreed; both are the same X1SON-2 package.

### Why the ferrite bead in the core path had to go (A1b)

Both references — the Home Assistant Voice PE and the designer's Gen1 board — put a ferrite bead
between the 0.9 V converter and the XMOS core rail. **This fork does not**, and the reason is
arithmetic.

The load is the XU316-1024-QF60B-**C24**: I(VDD) typically **225 mA**, maximum **830 mA**
(XU316-1024-QF60B datasheet, power consumption section, row I24). VDD must stay within
0.9 V ± 5 %, i.e. **0.855 … 0.945 V**.

The supply is the TPS62065 in PWM mode (MODE tied to +5 V through 0 Ω). From **SLVS833E**
(March 2010, revised October 2020), table "OUTPUT", p. 5: `Vref` 600 mV, `VFB(PWM)`
−1.5 % … +1.5 %, load regulation −0.5 %/A. With R74 = 51 k and R75 = 100 k the nominal output is
0.6 V × (1 + 51/100) = **0.906 V**. Worst case adds ±0.675 % from the 1 % divider resistors
(sensitivity (R1/R2)/(1+R1/R2) = 0.338).

The bead was a **BLM18KG601SN1D**, 600 Ω @ 100 MHz, **DCR 150 mΩ**, rated 1.3 A (LCSC C85833,
retrieved 30 Sep 2026) — so the current rating was never the problem; the DC resistance was. The
copper from the converter to the XU316 pins adds 14.5 mΩ over 18.22 mm.

| | with the 600 Ω bead | with a 0 Ω link (≤ 50 mΩ) | **without FB3** |
|---|---|---|---|
| VDD at 225 mA (typical) | 0.848 V | 0.871 V | **0.882 V** |
| VDD at 830 mA (maximum) | 0.746 V | 0.829 V | **0.871 V** |
| margin to the 0.855 V limit at 830 mA | **−109 mV** | **−26 mV** | **+16 mV** |

Only removing the bead holds in every calculated case. A 0 Ω link — considered first — still falls
26 mV short at maximum current, and raising the divider is no way out either: at 0.93 V nominal the
upper tolerance reaches 0.950 V, past the 0.945 V limit. Tapping the feedback behind the bead would
regulate the drop away, but it puts roughly 1 µH in the control loop of a 3 MHz converter (a pole
near 50 kHz) and needs an 18 mm high-impedance sense line across the board.

Two honest caveats: the ±1.5 % is a datasheet limit over temperature and input voltage, typically
the error is near 0 %; and 830 mA is the XU316's absolute maximum with all tiles at full clock,
while the FFVA firmware stays well below it. The calculation is the worst case — but a design that
does not survive the worst case has no margin left.

What the bead used to do, decoupling the core rail from the converter's switching noise, is now left
to the output capacitors (C17 4.7 µF, C18 10 µF, C20 10 µF) and the VDD decoupling at the XU316
(nine capacitors). **The 0603 land pattern is gone**, so re-fitting a bead is no longer a
no-cost option — if bring-up shows noise on the core rail, the fix is a bead of a few mΩ in the
0.80 mm link, which means a layout change.

`TP5`, the test point on this rail, now reads `VDD` rather than `+0V9`.

**A4, back-feed into +14V — corrected:** an earlier version of this file said this happens
only when USB-C and the 14 V supply are connected at the same time. That is wrong. It already
happens on **USB alone**, which is the documented way to flash the board ("Disconnect
POWER_IN before USB flashing" on the silkscreen):

* With the barrel connector unplugged, U4 (AP22802) puts VBUS on +5V.
* +5V reaches the `SW` node of U3 (TPS62130) through L1. With `VIN` at 0 V, `SW` exceeds its
  absolute maximum of `VIN` + 0.3 V (TPS62130 datasheet SLVSAG7F, page 4).
* The body diode of the integrated high-side switch conducts and charges the whole +14V rail,
  including PVDD with about 340 µF.
* Once +14V rises, R8 also enables U3, which then runs at 100 % duty cycle and ties `VIN` to
  `SW`. The +14V rail and PVDD end up at about +5V.

**Solved in rev A2:** the ideal diode U18 (LM66100DCK) in the output of U3 blocks the path, and Q4
with R76/R77 keeps U4 disabled while +14V is present. Both supplies may now be connected at the
same time, and the +14V rail stays at 0 V while the board runs from USB. See "Back-feed from USB
into +14 V — solved in rev A2" below, which gives the evidence (working notes: A4, finding 20; E4).

## 3. Amplifier (TAS5805M)

| Measure | What | Why / evidence | Commit |
|---|---|---|---|
| B1 | `ADR/FAULT` of U14: R70 changed from 0 Ω to GNDA to **4.7 kΩ to DVDD** | Sets the I²C address, TAS5805M datasheet Table 7-5 | `8a6df77` |
| B2 | C78 at `VR_DIG` changed from 100 nF to **1 µF** | Datasheet Table 8-5 (PBTL with inductor filter) | `fbccc6c` |
| B3/B4 | Firmware only: PBTL mode, address 0x2C, `analog_gain: -12dB` | See section 8 | — |
| K1 (audit) | **PBTL output pairing corrected:** U14 pins 26 + 23 (OUT_A+/OUT_A−) now go to L6, pins 17 + 20 (OUT_B+/OUT_B−) to L7. Upstream paired A+ with B+ and A− with B−, which in PBTL mode shorts half-bridges switching in opposite phase. Schematic and tracks only, all on F.Cu; the bootstrap capacitors stay on their own OUT pin | TAS5805M datasheet Figure 8-9, "Mono (PBTL) System Application Schematic", p. 84 | see git log |
| M8 (audit) | Speaker path L6/L7 → C86/C87 → J5 and the joining tracks at L6/L7 widened from 0.5 to **0.8 mm**; the B.Cu bridge of `Net-(C86-Pad1)` now uses **three vias at each end** instead of one | IPC-2221: 0.8 mm × 35 µm carries 2.03 A at 10 K rise; the speaker draws 1.31 A RMS with `analog_gain: -12dB` and 2.26 A unthrottled (12.6 K rise) | see git log |

## 4. Microphones, touch and antenna

| Measure | What | Why / evidence | Commit |
|---|---|---|---|
| D2 | MK3, C73, R61 set to DNP; R64 stayed populated. | The third microphone is not used: its data line is re-used by C4. (An earlier version of this file said R64 keeps U12 `1OE` at a defined level. That is wrong: R64 sits between `VDD_MIC` and MK3 `SELECT`, and U12 pad 1 had no copper. Fixed by B6.) | `ad378c0` |
| E5.1 | **The whole MK3 branch is now gone**: MK3, C73, R61, R51 and R64 are removed from the schematic and the board, together with their wires, three GND symbols and the label `MIC_DATA_M_2`. TP23 (`VDD_MIC`) was moved onto the copper that remains. | Leaving a populated-but-pointless branch in the design was the last reason for the two unconnected items DRC reported, and R64 fed a `VDD_MIC` stub that went nowhere. Netlist: 245 → 242 parts, 200 → 198 nets, no other net or node changed. | `5513330` |
| B6 | U12 (SN74LVC125A) pin 1 `1OE` connected to **GND** in the schematic and on the board. Pad 1 lies fully in the B.Cu GND fill that also connects pads 4 and 7, so no track is needed. Channel 1 is now permanently enabled: `1Y` = `1A` = `MUTE_ON`, a defined level on `MIC_DATA_2`, which goes to no XU316 port. | Pad 1 had no copper, so `1OE` was an open CMOS input on a populated part. The SN74LVC125A has no internal pull resistors and requires defined input levels. Built the same way as `2OE` (pin 4), which is already on GND. Netlist diff: only U12.1 `MIC_DATA_M_2` → `GND`. ERC unchanged. DRC: no new violation, unconnected items 3 → 2. | `b74d48b` |
| E1 | MPR121 touch controller (U15) connected: electrode ELEC1 and `TOUCH_IRQ` routed; the designer's copper rings around the three screw holes (B.Cu) serve as electrodes; test points TP14–TP16 placed on the board. | The touch electrodes were not connected in the layout. The schematic needed no change. | `26fb018` |
| G4 | Antenna matching network L3/L4/C28 moved next to the antenna feed. The mismatched feed line shrank from 7.47 mm to 4.29 mm (the antenna keep-out prevents going closer). One fence via removed. | Before the change, 7.47 mm of mismatched line (about 39° at 2.45 GHz) lay between the antenna and its matching network; now 4.29 mm (about 22°). | `14cee7d` |
| — | Antenna keep-out allows pads; GND via plus fill-exclusion area at the C46/C47 neck (0.072 mm copper neck removed) | DRC `items_not_allowed` / `connection_width` | `18d52cd` |

**G4b, RF trace width (`9f4e9bd`):**

* **What changed:** only the widths; no part and no trace was moved.
  * `LNA_IN` (ESP32 pin 1 → C28) went from 0.2 to **0.3 mm**.
  * The antenna feed `AE1-Pad1` (AE1 → L3) went from 0.2 to **0.4 mm**.
* **Clearance to the GND pour:**
  * Smallest gap per net: 0.1275 mm before and after (net-class clearance 0.125 mm).
  * The pour changes only at these traces: F.Cu GND −0.565 mm².
* **Checks:** DRC with schematic parity shows no new violations; ERC and the netlist are
  unchanged.
* **Impedance:** On the ordered stack-up (section 6) the 0.2 mm traces were estimated at
  about 65–73 Ω, and 0.4 mm at 50 Ω. By that estimate the feed is now close to 50 Ω, and
  `LNA_IN` at 0.3 mm is still above 50 Ω.
* **Teardrops (`11a1853`):** regenerated in the KiCad editor for the whole board.
  * The three teardrops on the RF nets now match the new widths.
  * 410 teardrops were added on 75 other nets, at pads and vias on all four copper layers
    (+49 mm² copper). None of them is on the RF nets.
  * Clearance of the RF nets, including their teardrops, to the GND pour stays 0.1275 mm.
  * DRC with schematic parity shows no new violations.

### The LED data line now has a 5 V level shifter (finding 10)

**What changed (F7.3):** a single buffer **U19 (74AHCT1G125GW, SOT-353-5, LCSC C12495)** sits
between the ESP32-S3 and the first LED. `OE` is tied to GND, `VCC` runs from +5V with a 100 nF
capacitor **C104** (LCSC C1525) 2.00 mm from the VCC pad. The old net `ESP_WS2812` was split into
`LED_DATA_3V3` (U8.27 → U19.2) and `LED_DATA_5V` (U19.4 → LED1.3).

**Why.** The LEDs run from +5V, and the SK6805/SK6812 family specifies `VIH` as **0.7 × VDD**, so
**3.5 V** at a 5 V supply. The ESP32-S3 guarantees only `VOH` ≥ **0.8 × VDD = 2.64 V**. Driving
`DIN` straight from a 3.3 V GPIO is therefore outside the LED's specification — it usually works
because the real threshold sits lower, but nothing in either datasheet promises it, least of all
across temperature and part spread. The 74AHCT1G125 closes both ends of the chain:

| Stage | Value | Requirement | Margin |
|---|---|---|---|
| ESP32-S3 `VOH` min → U19 `A` | 2.64 V | AHCT `VIH` max **2.0 V** | +0.64 V |
| U19 `Y` `VOH` min → LED1 `DIN` | **4.4 V** (VCC 4.5 V, I_OH −4 mA) | SK6812D `VIH` 3.5 V | +0.9 V |

The AHCT family is the right one here precisely because its inputs are TTL-compatible (`VIH` 2.0 V
instead of the 0.7 × VCC = 3.5 V an AHC or LVC part at 5 V would demand), so a 3.3 V logic level
drives it with margin while the output swings to the full 5 V rail.

**Deviation from Gen1 and the Voice PE.** Both drive their LEDs directly from a 3.3 V GPIO and work.
That is evidence the arrangement often functions, not that it is within specification; this board
keeps the shifter because the cost is one SC-70 part and one capacitor, and the first LED is the one
whose colour fidelity a marginal level would degrade first.

**Routing.** The outer layers have no corridor between U19 and U8, which is why the original line
already ran on In1.Cu. So the inner-layer run was brought to U19 instead of being detoured on the
LED side: the old 27.15 mm diagonal on In1.Cu was replaced by 15.27 mm (`LED_DATA_3V3`, from the U8
side) and 20.75 mm (`LED_DATA_5V`, on to LED1), with one via each next to the pads (T1
116.762/84.450, T2 120.138/83.900) and 1.61 mm of new copper on B.Cu. The alternative — cutting the
diagonal at its closest point to U19 — was found and rejected: it needed 36.0 mm of extra B.Cu track
across the LED side.

**Placement.** U19 sits at **118.450/84.450 on B.Cu** (LED side), 8.26 mm north-west of LED2,
8.84 mm from the nearest screw-hole edge and 7.44 mm outside the ELEC0 touch ring. The operator
confirmed on the sample that the clearance there — next to the shielded Google part — takes the
1.1 mm package. Sketch: `pics/u19_lage.svg`, drawn as seen when looking at the LED side.

**Checks.** ERC 72 (unchanged). Netlist: 241 → **243** parts, 201 → **202** nets, and per-pin the
diff shows only the five lines above. DRC with schematic parity **33 violations, 2 unconnected,
0 parity problems** — the same as before the change. Copper graph: both new nets form one component
each, no dangling ends. Zone islands 0. Clearances of the new copper ≥ 0.127 mm. Teardrops are
unchanged at 1051; the five new vias get theirs when the board is next opened in the editor.

### Why LED1 and LED6 sit on the microphone side, and stay there

The two edge LEDs on the tabs (`SK6812D-EC3210R`, side-emitting) are on **F.Cu**, the microphone
side, while the four ring LEDs are on B.Cu. That looks inconsistent, and an early prototype photo of
the designer's suggested it might be an oversight — in that photo every LED was still on one side.

It is not an oversight. On a dismantled H2C the original's **volume LEDs also sit on the underside,
the microphone side, and emit sideways outward**, into the light guides beside the two touch areas.
LED1 and LED6 reproduce that. Their purpose is the volume indication: the firmware turns `left_led`
(index 0 = LED1) and `right_led` (index 5 = LED6) on while the corresponding touch area is held.
LED6 is also the link that carries the chain onward — its output goes through R80 to J6.5 and the
LED ring board — so removing the two would mean re-wiring the chain end and shifting every LED index
in the firmware.

**Orientation checked.** The light has to leave toward the board edge, not toward the middle. The
part is a side emitter (LCSC C2890041: "SMD-4P 3.2 × 1.0 × 1.08 mm", mounting **side view**), and its
footprint marks the emitting face: `Onju:LED-SMD_4P_SK6812D-EC3210R` carries a closed silkscreen
rectangle from (−1.000 / 0.681) to (1.000 / 1.100), running the full length of the part and lying
outside its 1.0 mm wide body; the top-emitting footprint `Onju:SK6805-EC20` used for the ring has
no silkscreen at all (the footprint keeps that name; the part in it is now the SK6812-EC20,
which has the same outline and the same pad positions). Solving the part-to-board transform from the measured pad positions — not from an
assumed rotation convention — and checking it against all four pads gives:

| | Rotation | Emitting face points | Part lies | Result |
|---|---|---|---|---|
| LED1 | −90° | west (−x) | west of centre | **outward** |
| LED6 | +90° | east (+x) | east of centre | **outward** |

Both are correct, and the two are exact mirror images of each other. The one thing not proven from a
document is that the silkscreen rectangle really is the lens: the package drawing in the datasheet is
an image, and its text could not be extracted. Lighting LED1 on the sample settles it in seconds.

### What the LED ring draws from +5V (rev A2)

With LED2–LED5 changed to the SK6812-EC20, all six LEDs draw the same **12 mA per colour**; the
SK6805 was a 5 mA part, so the ring used to be visibly dimmer than the two edge LEDs.

| Item | Was | Now |
|---|---|---|
| LED2–LED5 | 4 × 3 × 5 mA = 60 mA | 4 × 3 × 12 mA = **144 mA** |
| LED1, LED6 (SK6812D-EC3210R) | 72 mA | 72 mA |
| TAS5805M `DVDD` through U7 | not counted | + 13 mA |
| **+5V total** | about 550 mA typical, 700 mA peak | **about 647 mA typical, 800 mA peak** |

U18 (LM66100, 1.5 A) and U3 (TPS62130, 3 A) still have plenty of margin, and the drop across U18
stays at about 63 mV.

**One thing to know when you power it from USB:** at full brightness the board pulls up to 0.8 A
from VBUS plus converter losses, so a plain 500 mA charger will not do. The receptacle is wired for
the full current anyway (R1/R5 = 5.1 kΩ), so any supply that can deliver 1 A or more is fine.

## 5. Footprints and fabrication rules

| Measure | What | Why | Commit |
|---|---|---|---|
| F2 | J1 (USB-C) SMD pads: `solder_paste_margin` changed from −100 to 0 | The 24 pads would have received no solder paste | `ba1286a` |
| F3 | J1 shield pads renamed from `"0"` to SH1–SH4 on GND | The shield had no net. This removes 4 parity errors. | `1d4c356` |
| F4 | Three extra 0.85 mm Edge.Cuts circles over the microphone ports removed | The footprint already has the 0.5 mm port; TDK T3902 DS-000357 p. 18 recommends 0.5–1 mm | `8b8205a` |
| — | U6 now uses the KiCad standard footprint `Texas_DSG0008A` | Part of A1 | `3ff45d1` |
| V2 | **Thermal holes enlarged to 0.3 mm, pads to 0.6 mm**; positions unchanged. U14: 24 pads 0.2 / 0.3 mm → **0.3 / 0.6 mm**. U3, U7: 4 pads each 0.2 / 0.5 mm → **0.3 / 0.6 mm**. The annular ring is now **0.15 mm**, the JLCPCB minimum for plated component holes (multilayer, 1 oz). The smallest hole on the board is now 0.3 mm. | 0.2 mm holes need a special drill option and cost more. These holes are marked as component holes in the drill file, and for those JLCPCB requires a 0.15 mm annular ring. Ring to ring: U14 0.60 mm, U3/U7 0.58 mm. Ring to copper of other nets: F.Cu ≥ 0.169 mm (U3/U7 pad 1), In2 0.50 mm (+5V plane), In1/B.Cu ≥ 1.0 mm. DRC with parity shows no new violations; ERC and the netlist are unchanged. Fill changes only at U14, U3 and U7. | `9d27103`, `3fd705f` |
| V3 | **Three tap vias moved out of their pads**, positions of the parts unchanged. R23.2 (`I2S_MCLK`) 129.900 / 73.200 → **129.400 / 74.271**; R29.2 (`I2S_LRCK`) 126.700 / 75.500 → **126.880 / 75.341**; R30.2 (`I2S_BCLK`) 127.500 / 75.500 → **128.060 / 75.831**. Each gets a 0.2 mm stub from the pad centre, and the track that continues on the other layer follows to the new via (R23 on In2.Cu, R29 and R30 on B.Cu). Since E5c-P5 R23 no longer exists; its via at 129.400 / 74.271 stays and remains part of the `I2S_MCLK` path (X1D11 to R24/R31), the 0.2 mm stub went with the pad. The three old 0.15 mm stubs and nine teardrops at the old positions were removed. | These three vias came from this fork (C1, C2 and C4). Their rings overlapped the pad copper and their drilled holes sat inside the pads' solder-mask openings, which a Eurocircuits DFM run reported as "Bohrungen in SMD". Via edge to its own pad is now 0.134–0.454 mm, smallest clearance to other copper 0.132 mm. DRC with schematic parity is unchanged; netlist identical, stub test unchanged. Pairings "hole inside a mask opening": 31 → 28. | `f0d524f` |
| V1 | **Five vias moved out of small pads** and connected with a 0.2 mm stub from the pad centre. U6 pad 1 (GND) 136.500 / 78.200 → 137.370 / 78.070; U9 pad 4 (GND) 130.788 / 58.395 → 131.907 / 58.095; C13 pad 2 (GND) 136.000 / 82.800 → 135.330 / 82.633; C70 pad 2 (GND, bottom) 131.500 / 80.350 → 131.060 / 80.180; C100 pad 1 (+0V9) 133.000 / 82.400 → 133.600 / 82.800, with the B.Cu track from 132.0 / 82.4 extended to the new via. The old in-pad stubs of C13 and C100 and three via teardrops at the old positions were removed. | A via in a small pad needs resin filling and a copper cap. The U9 via came from upstream, the other four from this fork (A1, `9f279f2`; C70 in `0dcb0e5`). Checked against the current board: no via is left in any SMD pad. Via edge to its own pad is 0.127–0.595 mm, to copper of other nets ≥ 0.127 mm, and the four GND vias connect to the In1 GND plane. DRC with parity shows no new violations; ERC and the netlist are unchanged. All fill changes lie within 0.7 mm of an old or new via position. Vias in SMD pads: 31 → 26. | `07ece05` |
| — | L6/L7 footprint changed from `XAL4040-103MEC` to `MTQH404030S100MBT`: lands 1.6 × 4.1 mm at ±1.35 mm; tracks unchanged | Replacement inductor, see section 7 | `f4fd33f` |
| — | DRC severities `lib_footprint_issues` / `lib_footprint_mismatch` set to *ignore*; DRC exclusions set for the electrode rings and J3/J4 | The upstream footprint libraries are not in the repository | `18d52cd`, `6836fe7` |

**Checked, no change needed: inner annular ring (IAR).** A Eurocircuits check run on the rev A1
data reported: *"Der gemessene Wert für Innenlagenrestring (IAR) (0,000 mm) stimmt mit keiner
der verfügbaren Optionen überein."* We measured every one of the 438 holes against all copper
on In1 and In2 (zone fills, pads, vias, tracks, teardrops):

| | In1.Cu | In2.Cu |
|---|---|---|
| 397 vias (0.3 / 0.4 mm) | 0.05 mm | 0.05 mm |
| U14 thermal holes | 2.52 mm | 0.149 mm |
| U3 / U7 thermal holes | 0.204 mm | 0.149 mm |
| J1 (4 slots) | 0.394 mm | 0.200 mm |

* **No hole meets inner copper without a ring.** The smallest inner ring is 0.05 mm, at the
  vias, on both inner layers.
* The **non-plated** holes (MK1 and MK2 at 0.5 mm; MK3 and U1 are gone since E5.1 and E1) have no copper
  at all on the inner layers; the nearest copper is 0.127 mm away. They are in their own file
  `…-NPTH.drl`, which carries the Gerber attribute `NonPlated`.
* No pad and no via uses "remove unused layers"; every one keeps its ring on all four layers.
* **This is not a design error.** The reported 0.000 mm does not match any hole in the data.
  The most likely reason is that the non-plated holes were measured as if they were plated,
  which happens when the NPTH file is not recognised as non-plated on upload.

**Checked, no change needed: C13 and C24 (Eurocircuits DFM).** The same check run reported
*"Bohrungen in SMD"* at C13, C30 and C38, and *"Bauteil möglicherweise außerhalb der Kontur"*
at C24.

* **C13 is clear since V1.** The via sits at 135.330 / 82.633, outside the pad: 0.145 mm from
  the pad copper and 0.115 mm from its solder-mask opening; the drilled hole is 0.195 mm from
  the copper and 0.165 mm from the opening. In `production/` (before V1) the via was still
  inside the pad, which explains the message if that data set was checked.
* **C24 is well inside the outline.** Its pads and mask opening are 8.53 mm from the nearest
  `Edge.Cuts` element, its courtyard 8.23 mm. The part sits at 116.400 / 81.000 and the board
  spans 98.6 / 54.7 to 173.1 / 125.0, 3212.6 mm².
  * `Edge.Cuts` holds the outline plus **four inner cut-outs** (18.9 mm² at 145.9 / 72.6,
    10.8 mm² each at 107.0 / 87.2 and 161.0 / 87.2, 9.1 mm² at 134.1 / 114.2). The nearest one
    is the 8.23 mm away. A checker that takes one of these as the board outline reports most
    parts as outside; that would explain the message, but we could not confirm it.
* **C30 has no via in the pad.** The nearest via is 0.090 mm from the pad copper, its hole
  0.140 mm; both vias belong to the same net and come from upstream.
* **C38 / C39:** see "Via holes inside a pad's solder-mask opening" under the known issues.

### When ordering: the board needs 0.10 mm minimum track width

Two signals, `UART_TX` and `UART_RX`, use the net class **`UART-eng`** with a track width of
**0.100 mm**; everything else stays at 0.150 mm and the clearance is 0.127 mm throughout. The
narrow sections are what makes the expansion connector J6 reachable at all (see "A track ran
lengthwise under the whole pad row of J6" under the known issues). A rule file
`nest-mini-v2-drop-in-pcb.kicad_dru` relaxes `track_width` and `connection_width` for this net
class only, so the DRC checks the rest of the board against 0.127 mm as before.

**JLCPCB fabricates this without a surcharge**, both pages retrieved 30 Sep 2026:

* `jlcpcb.com/capabilities/pcb-capabilities` — multilayer, 1 oz outer copper:
  "0.09 / 0.09 mm (3.5 / 3.5 mil)".
* `jlcpcb.com/help/article/in-what-cases-will-there-be-charged-extra` — extra cost only "if the
  trace width or spacing of multi-layer boards is 3.0-3.5mil" (20 % of the order amount for
  4–8 layers). **0.10 mm is 3.94 mil**, above that threshold; the margin to it is 0.011 mm.

**With any other fabricator, check this first.** A house that quotes 4 mil (0.1016 mm) as its
minimum would reject or surcharge these two tracks. Should that happen, the fix is not to widen
them — the channel to J6 does not fit two 0.15 mm tracks — but either to widen the channel (move
the ELEC2 electrode ring or the screw hole at 162.815 / 89.076) or to accept one of the two UART
signals staying unconnected, as rev A2 stood before this change.

### When ordering: the XMOS flash U11 stays at 4 MB (W25Q32JVSSIQ)

U11 is a **W25Q32JVSSIQ**, 32 Mbit = **4 MB**, LCSC C179173, 8-pin SOIC 208-mil. An 8 MB part was
considered and rejected. The reason is worth recording, because the three boards this design takes
its cues from do not agree with each other:

| Board | Flash at the XU316 | Size | Source |
|---|---|---|---|
| **Gen1** (`home-mini-DiP-v1`) | W25Q32JVSSIQ | **4 MB** | U9 on the XMOS sheet; `pruefung/gen1.net` puts U9 on `/XMOS/QSPI_CLK`, `QSPI_CS_N` and `QSPI_D0…D3`, so it is the XU316's boot flash (in Gen1 the XU316 is U8) |
| Satellite1 rev 6.1 | W25Q64JVSSIQ | 8 MB | `FutureProofHomes/Satellite1-Hardware`, `hat/rev6.1hatSCH.pdf`, U18, next to U17 `XU316-1024-QF60B-I32` |
| Voice PE v1.0 | ZB25VQ128DSJG | 16 MB | `home_assistant_voice_pe_schematic_v1.0_241009.pdf`, U15 |
| **this board, rev A2** | **W25Q32JVSSIQ** | **4 MB** | — |

**Why 4 MB and not more.** Two independent pieces of evidence point the same way:

* **The firmware says 4 MB.** The FFVA firmware this board runs describes its own target in
  `src/ffva/bsp_config/NC-VOICE-KIT/NC-VOICE-KIT.xn` (`esphome/voice-kit-xmos-firmware`, tag
  `v1.3.1`):

      <Device NodeId="0" Tile="0" Class="SQIFlash" Name="bootFlash" Type="S25FL116K"
              PageSize="256" SectorSize="4096" NumPages="16384">

  16384 pages × 256 bytes = **4 194 304 bytes = 4.00 MiB**. That is the geometry `xflash` is given
  when the image is built, and the boot partition the build system asks for is 0x100000 = 1 MiB. So
  the firmware is not merely *able* to live in 4 MB — 4 MB is what its target description declares,
  even though the Voice PE hardware it was written for physically carries 16 MB.
* **Gen1 proves it in hardware.** Gen1 runs this firmware family on exactly this 4 MB part, and
  Gen1 is built and shipped. For the 8 MB part there is no such proof on an XU316 of *this* variant:
  Satellite1 uses it, but with an `XU316-1024-QF60B-I32`, a different order grade.

Going to 8 MB would therefore have bought a margin nothing asks for, at about $0.55 more per piece,
and would have replaced a part proven in hardware with one that is not. If more room is ever
needed — a second firmware image, a larger data partition — `W25Q64JVSSIQ` (LCSC C179171) is the
drop-in: same package code `SS`, same `IQ` order suffix (QE bit factory-fixed to 1, so IO2/IO3 are
quad pins from power-up), tVSL 20 µs, Fast Read Quad I/O `EBh` (Winbond W25Q64JV, Rev J,
2018-03-27). Only the device ID changes with the capacity, so a boot image that hard-codes it must be
rebuilt.

**Measured.** The factory image was built with XTC Tools 15.3.1 and is **286 720 bytes
(280.0 KiB)**:

    xflash --factory ffva_v1.3.1.xe --boot-partition-size 0x100000 -o ffva_v1.3.1_factory.bin

That is **27.3 % of the 1 MiB boot partition and 6.8 % of the 4 MiB flash**, which settles the
capacity question by measurement and not by inference. The image comes out byte-for-byte identical
whether `--target-file NC-VOICE-KIT.xn` is given or not, whether the XN names `S25FL116K` or
`W25Q32JV`, and whether the boot partition is declared as 0x100000, 0x80000 or left out — the target
description is compiled into the `.xe`, and the boot-partition size is metadata rather than padding.

**The toolchain knows our part by name.** `W25Q32JV` is one of the 15 devices natively supported by
`libquadflash` (`target/include/QuadSpecEnum.h`, `fl_QuadFlashId`: `WINBOND_W25Q32JV = 13`, together
with W25Q16JV, W25Q64JV, W25Q128JV, three Spansion and eight ISSI parts; also listed in the tools
documentation under "List of devices natively supported by libquadflash"). So no `--spi-spec` file is
needed and nothing depends on SFDP auto-detection — `--noinq` exists to suppress the device query,
and `--spi-spec` to describe a part that is not on the list. Neither applies here.

Writing it to the board still needs the XTAG4 on J4; `xflash --list-devices` reports "No Available
Devices Found" until one is attached.

**The image is in the repository:** `firmware/xmos/ffva_v1.3.1_factory.bin`, with its checksums in
`MD5SUMS`, the exact build command and provenance in `firmware/xmos/README.md`, and a copy of the
XMOS Public Licence v1 alongside it. That licence covers compiled code only under its clause 2.2, so
the directory carries the source notice its clause 2.3 requires (where the source is, that nothing was
modified) and the clause 2.2.2 condition is met because the code runs on an XU316. Nothing in the
firmware was changed — the release `.xe` was only repackaged by `xflash`, and since that build is
deterministic the file can be reproduced from the public release asset at any time.

## 6. Board and silkscreen

* **Stack-up set to JLCPCB JLC04161H-7628** (`ba55b9f`). The board is 1.6 mm, 4 layers:
  prepreg 0.2104 mm (εr 4.4), core 1.065 mm (εr 4.6), inner copper 0.5 oz. The previous
  values were the KiCad defaults. The surface finish is not set in the project and is chosen
  at order time.
* **Silkscreen** (`6e97dd7`, and E5b.5 in `433136d` / `18f93b1`):
  * The upstream "MiciMike" logo and board titles were removed from both sides.
  * "CERN-OHL-S-2.0" and the USB flashing note were kept.
  * B.Silkscreen now carries: *"based on MiciMike Nest Mini v2 by iMike78 · CERN-OHL-S 2.0 ·
    modified"*, plus **`rev-a2` and the date**, once on each side.
  * **All 23 silkscreen DRC warnings are gone** (E5b.5). They were worked off one at a time and
    each step is logged: pin-1 and polarity marks were **moved**, never deleted, and only inside
    the sector of their present bearing from the part centre, so they still say what they said
    (U14, MK1, X1, POWER_IN1, U11); outline segments were **shortened from the offending end** in
    0.05 mm steps until clear, so they stay recognisable as an outline (SW1 twice, SW2 twice, L8);
    reference fields were offset; five orphaned digits on B.Silkscreen ("4", "1", "10", "1", "9")
    were removed — they were the pin numbers of J3 and TP10, which E3 took out, so they labelled
    nothing.
  * **Pin-1 marks** are present on J1, J4, J5, J6 and POWER_IN1. There are **no pin numbers** next
    to the connectors: at 0.5 mm pitch they would not be legible, so the pinouts live in the
    README instead.

### Test points (rev A2)

Rev A1 had eleven test points, several of them labelled only "TestPoint". Rev A2 brings the count
to **eighteen**, all bare copper with nothing to populate, and gives every one a short name on the
silkscreen next to the pad (the full net name does not fit on a 68 mm board):

| New | Net | Why |
|---|---|---|
| TP17 | `+5V` | **behind** the ideal diode U18 — together with TP3 in front of it, this is the pair that shows whether U18 works: about 55…65 mV of difference under load, and TP3 near 0 V on USB alone |
| TP18 | `+14V` | the rail from the base plate, at the input side |
| TP19 | `ESP_RST` | reset of the ESP32-S3 |
| TP20 | `ESP_BOOT` | boot mode of the ESP32-S3 |
| TP21, TP22 | `GND` | a reference next to U8 and one next to U14, so a probe does not need a long return path |
| TP23 | `VDD_MIC` | the 3.3 V microphone supply from U13, on the copper that remained after the MK3 branch came out |

The short names are **in the value field**, not in an extra text item, so there is one source for
them and schematic parity stays intact. TP3 was renamed `5V_SW` to match its net. The three touch
electrodes TP14–TP16 carry **no** silkscreen: they sit inside the electrode rings on the LED side,
where any lettering would land on copper. The full table with positions and expected readings is in
the README. I²C and SPI test points were considered and dropped — the buses are reachable at the
parts themselves, and the board has no room to spare.

### Touch electrode rings pulled back from the hole edge (E5b.2)

The three copper rings around the screw holes serve as the touch electrodes. In rev A1 they ran up
to the hole edge, which produced three `copper_edge_clearance` findings that had to be **excluded**
from DRC with a stated reason. Rev A2 pulls the inner edge of each ring back to **at least 0.25 mm**
from the hole edge. The electrode area is otherwise unchanged, so the capacitance seen by the MPR121
barely moves; the three exclusions are gone, and DRC now passes these rings without being told to
ignore them (`38aad27`).

### The land pattern of L6 and L7 against the manufacturer's datasheet (E5b.3)

L6 and L7 are the output inductors of the amplifier, changed in rev A2 from the Coilcraft
XAL4040-103MEC to the MetalLions MTQH404030S100MBT (C51883185) for cost. The land pattern had been
taken from the LCSC footprint, which is not a source. It was checked against the MetalLions
datasheet and found correct; the silkscreen outline around both parts was cleaned up at the same
time (`77439a9`).

The DC resistance matters here because it sits in the speaker path: the datasheet gives **92 mΩ
typical and 110 mΩ maximum** for the S100 variant. An earlier reading of 190/220 mΩ was a
transcription artefact — `pdftotext` had shifted the columns of the MetalLions catalogue.
* **Zone refills** (`3c7bb45`, `c4c0cf8`, `6cf4fc1`, `6836fe7`, `5e09946`, `289454b`,
  plus earlier ones in C and B) change fill polygons only.

## 7. Bill of materials

All populated parts carry an LCSC part number: **84 unique parts, 221 placements**, 814 solder
joints, 153 parts on F.Cu and 68 on B.Cu. Twenty-one items are marked DNP: the eighteen test
points, the J4 pad field and the two PG pull-ups R10/R16.

**Six gaps were found and closed in E7**, all of them in parts that rev A2 itself added — they
had their part number in the wrong field, or not at all, so the BOM and CPL exporters did not see
them. Each number was checked on its LCSC product page (1 Oct 2026) and against the footprint in
the layout:

| Part | What was wrong | Now |
|---|---|---|
| **R80** (100 R, LED data line to the ring board) | `LCSC Part #` held **C25744**, which is a **10 kΩ** resistor, and the MPN field said `0402WGF1002TCE` — also 10 kΩ. The value field said 100 R. | **C25076** (`0402WGF1000TCE`, 100 Ω ±1 %, 0402). Had this gone to fabrication, R80 would have been fitted with 10 kΩ and the data line to the ring board would not have worked. |
| **U18** (ideal diode) | no part number in any field | **C2869734** (LM66100DCKR, TI, SC-70-6) |
| **U19** (level shifter) | number only in a field named `LCSC`, which no exporter reads | **C12495** (74AHCT1G125GW,125, Nexperia, SOT-353) |
| **Q4** (USB lock-out) | number only in `Supplier Part` | **C383201** (LBSS138WT1G, LRC, SC-70; 50 V, 200 mA, V(GS(th)) max 1.5 V — the value the divider R76/R77 was dimensioned against) |
| **C104** (U19 decoupling) | number only in a field named `LCSC` | **C1525** (CL05B104KO5NNNC, 100 nF 16 V 0402; it sits on +5V, so 16 V is ample) |
| **R79** (10 k) | correct in the schematic, missing in the layout | **C25744** in both |

Changes compared with `7de6eec6`:

| Parts | Change | Why | Commit |
|---|---|---|---|
| U1, U2, U11, U14, C74–C77, C80, C82, C90, C91, R2–R4, R6, R66, R67 | Part numbers added (no number upstream) | Needed for assembly; each number was checked on the LCSC product page against value, package and rating | `7a514f0`, `a5ecf2b` |
| C86, C87 | Part number added: C107133 (680 nF 50 V X7R 0805) | The design asks for 100 V, which does not exist in 0805. 50 V is 3.5 × PVDD (decision) | `18da934` |
| R68, R69 | Changed from C17168 (0402) to **C17477** (0805 jumper, 2 A) | Package mismatch; these are the GND–GNDA links carrying amplifier return current | `309fdba` |
| R13 | Changed from C3016445 (4 in stock) to **C861392** (YAGEO 40 kΩ 0.1 %) | Availability. U3 output unchanged: 0.8 V × (1 + 210 049.9 / 40 000) = 5.001 V | `3fdd26e` |
| LED2–LED5 | Changed from C2890036 (**SK6805-EC20**) to **C2909058** (**SK6812-EC20**) | Availability (115 in stock against 37 174) and equal brightness across all six LEDs. Both types are 2 × 2 × 0.65 mm with the pads in the same places, so the footprint, the placement and the CPL rotation are untouched — only the part number changes. Costs 84 mA more on +5V, see below | this commit |
| L6, L7 | Changed from Coilcraft XAL4040-103MEC (about 8.6 $ each) to **MetalLions MTQH404030S100MBT** (C51883185): 10 µH, Isat 4.9 A, 92 mΩ | Cost. The firmware limit `analog_gain ≤ −12 dB` keeps the peak current at about 1.85 A. The land pattern was taken from the LCSC footprint; **the manufacturer datasheet still needs to be verified.** | `f4fd33f` |
| C1/C83/C88, C6/C17/C80/C90, C12/C64, C79/C81/C84/C85, R8/R9/R15/R41/R75, R73 | Replaced by JLCPCB *basic* parts of the same value and package, with at least the same voltage and equal or better tolerance. C6/C17/C80/C90 and C12/C64 change from X7R 10 V to **X5R 16 V**. | Fewer extended-part setup fees | `0f547c6` |
| Values | C13 2.2 → 10 µF, C18 4.7 → 10 µF, C20 100 nF → 10 µF, C78 100 nF → 1 µF, R7/R14 100 k → 0 Ω, R70 0 Ω → 4.7 k; new: L8, R74, R75, C100 | Sections 2 and 3 | see above |
| DNP | R10, R16 (the PG pull-ups). MK3, C73 and R61 were DNP in rev A1 and are now **removed** (E5.1) | Sections 1, 2 and 4 | see above |
| Removed | R23, R25, R26 (were DNP), J3, TP10, **J2**, **U1/U2 and their parts** (E1), **MK3/C73/R61/R51/R64** (E5.1), **R37/R38** (E5.4), **C2** (E5.5) | Sections 1, 2 and 4. C2 was the 100 nF decoupling capacitor of U2's VCC; U2 went out with the USB switch-over in E1, so C2 had been sitting on a net with nothing to decouple. The part count is now **242** with **198** nets. | see above |

**Kept deliberately:**

* **J1** (Molex 1054500101, C134092). No stocked USB-C receptacle fits the footprint.
  C134092 is a stocked part, but JLCPCB flags it as "process difficult" in the BOM check,
  where it has to be confirmed by hand.
* **L1/L2** (Bourns SRP4020TA on a Cenker footprint), as fabricated by the upstream designer
  since 2025.
* **C83 and C88 keep C307331** (Samsung CL05B104KB54PNC, 100 nF **50 V** X7R 0402) instead of
  being merged into C1525, the part used for the other 41 100 nF capacitors. C1525 is
  CL05B104KO5NNNC and rated **16 V**, while C83 and C88 sit on `PVDD` / `GNDA` — the
  TAS5805M supply, fed from the +14 V input through R66. 14 V on a 16 V part is 88 % of the
  rating; it breaks rule A3 above ("all input capacitors on +14 V / PVDD are rated ≥ 25 V"),
  the condition under which these two were moved to a basic part in the first place ("at least
  the same voltage"), and the decision taken for C86/C87 on the same rail (50 V, "3.5 × PVDD").
  All 41 C1525 sit on rails of 5 V or less — these two are the only 100 nF 0402 above 5 V in
  the design, which is why the second part number exists. Merging them would have saved **0.8
  cents** per board and one BOM line, and **no setup fee**: both parts are JLCPCB *basic*
  parts.

## 8. Firmware configuration (`nest-mini-v2-voice.yaml`, new file)

This file is derived from upstream `MiciMike.yaml`, which is unchanged in this repository.

* **Wi-Fi:** DHCP instead of a fixed IP. All credentials are read via `!secret` from
  `secrets.yaml`, which is not in the repository; `secrets.example.yaml` lists every key the YAML
  uses (`ssid`, `wifi_pass`, `api_key`) with placeholders — copy it to `secrets.yaml` and fill it in.
* **Touch:** `esp32_touch` replaced by the **MPR121** component (address 0x5A, channels 0/1/2).
* **I²S:**
  * `i2s_dout_pin` GPIO11 → **GPIO10**, which goes to the XU316 via R24 (see C3).
  * The ESP32 is `secondary` on both buses.
  * No MCLK pin.
* **Amplifier:** `tas58xx` in PBTL mode, address 0x2C, `enable_pin: GPIO18`,
  `analog_gain: -12dB`.
  * This gain limit **must not be raised**. The TAS5805M analog-gain scale refers to 29.5 V
    (datasheet Table 7-2). At −12 dB the peak output is 7.41 V, which gives about 1.85 A into
    4 Ω. The limit protects L6/L7 from saturation and also protects the 40 mm driver.
* **XU316 reset:** `reset_pin: GPIO46` (see C7).
* **Mute:** mute detect on GPIO1, not inverted.
* **Other:**
  * `rgb_order` replaced by `channel_colors` for ESPHome 2026.
  * `${device_name}` and `${friendly_name}` substitutions defined.
  * Five light effects were called but never defined. They are now defined: `pulse`, `slow_pulse`, `"Volume Display"` (taken from the Voice PE template), `show_volume` mapped to it, and `listening_ww` as the built-in `flicker`. The last one is an interpretation, not taken from a source.
  * Entity names translated to German.
* **Pin-audit fixes (1–2 Oct 2026), before the first power-up:**
  * **K-B1, sample rate:** the two resamplers and both media-player pipelines ran at 44 100 Hz while
    the I²S speaker is fixed at 48 000 Hz. As an I²S secondary it cannot change its rate and rejects
    the stream (`i2s_audio_speaker_standard.cpp`, lines 368–372, "Incompatible stream settings") —
    there would have been no sound. All four are now 48 000 Hz, as in the Voice PE.
  * **K-B2, LED effects:** the effects came from the Voice PE's 12-LED ring and wrote `it[0..11]`
    into a 4-LED partition; ESPHome does not check the index (`partition/light_partition.h`), so they
    wrote past the buffer. Every effect now works on `N = it.size()`, and `voice_assistant_leds` and
    `led_ring` span all six LEDs (index 0–5, left to right). Mic mute shows on the two outer LEDs,
    volume zero on the two middle ones.
  * **K-B3, LED timing:** `chipset: SK6812` gives T1H = 600 ns; the SK6812-EC20 needs ≥ 0.70 µs and
    the SK6812D-EC3210R 0.65–1.00 µs. Custom timing now: 300/900 ns for a 0, 800/400 ns for a 1.
  * **K-B4, amplifier start-up order:** `tas58xx` put the TAS5805M into PLAY (in BTL, at 0 dB) before
    it set PBTL and −12 dB. It is now loaded from a local, patched copy
    (`firmware/esphome/components/tas58xx`, upstream `89f29cf` plus two lines, see
    `firmware/esphome/PATCH.md`): the register table ends in Hi-Z, PLAY follows PBTL and the gain.
    The copy is GPL-3.0-or-later (© mrtoy-me, based on work by Andriy Malyshenko); the change was
    submitted upstream as PR #4, now closed; per maintainer's comment in mrtoy-me/esphome-tas58xx#4
    the start-up order is covered by his development branch and by the ESPHome core driver
    (esphome/esphome#19971).
  * **K-B5, start-up after the XU316 reset:** `setup_priority: 790` for the amplifier, below
    `voice_kit` (799), so PDN, configuration and PLAY follow the XU316 reset; the TAS5805M waits in
    Hi-Z for the clocks (datasheet 7.3.4). **The transition to PLAY is coupled to the XU316 being
    ready** (2 Oct 2026, review point B5-B2): ESPHome's `Application::setup()` (2026.9.0,
    `core/application.cpp` lines 64–65 and 78–102) sets components up in priority order and waits after
    each one until its `can_proceed()` is true; `VoiceKit::can_proceed()` (`voice_kit.h` line 127) is
    true only once the XU316 firmware version has been read over I²C and matches (about 3 s after the
    reset, or after a DFU update). The amplifier, at priority 790, is therefore configured only when
    FFVA is running and driving BCLK/LRCLK; until then R71 holds /PDN low and the outputs are
    high-impedance. That is the order of datasheet 7.5.3.1 (PDN, 5 ms, stable clocks, Hi-Z, DSP,
    PLAY). Only if `voice_kit` fails (no XU316) does set-up continue without clocks; the device then
    stays in clock-error Hi-Z (7.3.4). Checked at bring-up: register 0x71 = 0 after start, sound,
    and the `tas58xx` set-up logged after `[voice_kit] DFU version`.
    The same holds for the ESPHome core `tas58xx` component (ESPHome dev, commit
    `3cc4df4b3a5ce55efe26237ee99d71fff90b8e50`, `esphome/components/tas58xx/tas58xx.cpp`): `init_()`
    (lines 82–113) resets the device, writes the start-up table, PBTL and the gain and sets PLAY
    (line 107) inside `setup()`, without waiting for the I²S clock; only the mixer coefficients wait for
    it (line 112, `on_audio_started()` lines 214–222, `update()` lines 236–238), and the device itself
    waits in Hi-Z (`tas58xx.h` line 85). The datasheet asks for stable clocks before Hi-Z and DSP
    enable (7.5.3.1 step 4), so `setup_priority: 790` stays with the core component as well.
  * **Amplifier fault handling (5 Oct 2026):** the copy cleared every fault on the next 1 s update,
    DC and over-current faults included, which restarts the output while a DC fault (re-tripping only
    after 570 ms, datasheet 7.5.3.3) is present. It now leaves those faults set and the output off until
    the device restarts, as the core component does (`firmware/esphome/PATCH.md`).
  * **Amplifier faults:** the ADR/FAULT pin is not wired to the ESP32, so the fault registers are read
    over I²C with the `tas58xx` binary sensors (any fault, over-current and DC fault per channel, PVDD
    under/over-voltage, over-temperature warning and shutdown).
  * **Comments corrected:** the PLAY order, the `tas58xx` licence note (its README names GPL-3.0 code
    as the basis), `mixer_mode` (only written when EQ entities exist), and a note that GPIO3/GPIO4
    must stay unused because they share the XU316 QSPI bus.
* **Decisions of 2 Oct 2026 (commits `d1a3583`, `c6b3fb3`; see "Every open point decided"):**
  * **K-B8, sounds pinned:** the 16 sound files load from Voice PE commit `d4e6fa43` instead of the
    moving `raw/dev` branch. ESPHome checks no hash for `files:`; the commit fixes the content (all 16
    byte-identical with the earlier build).
  * **K-B9, models pinned:** `hey_jarvis`, `hey_mycroft` and the VAD model load from
    `esphome/micro-wake-word-models` at commit `40ff33f`. `okay_nabu` and `stop` exist only as release
    assets that GitHub reports as not immutable; their target sha256 values are noted in the YAML.
  * **K-B10:** `min_version: 2026.9.0` — the version every fix above was checked with (as in the
    Voice PE).
  * **K-B14:** the voice assistant takes microphone channels 0 and 1, as the Voice PE does; Home
    Assistant can then stream channel 1 (AEC + IC + NS, no AGC) to STT services that ask for it.
    Cost: 16 384 bytes of PSRAM.
  * **U8-B6:** a comment lists the GPIOs that are wired on the board but deliberately unused
    (GPIO3/4 on the XMOS flash bus, GPIO39/40 behind U16, GPIO9/11/12/48 on J6).
  * **U8-B12 / M13:** `psram: enable_ecc: true` is prepared as a commented-out option (85 °C instead
    of 65 °C ambient, 7.5 instead of 8 MB usable), and a diagnostic `internal_temperature` sensor
    feeds the temperature measurement M-T at bring-up.
  * **U14-B2:** the `tas58xx` register table sets **0x53 = 0x60**, class-D loop bandwidth 175 kHz for
    768 kHz switching (SLASEH5D table 7-27), written in Hi-Z before PLAY (`firmware/esphome/PATCH.md`).
* **Build check:** compiles with ESPHome 2026.9.0 / ESP-IDF 5.5.5 (after the decisions of 2 Oct 2026:
  RAM 43.0 %, flash 28.1 % of one 8 MB OTA slot, image 2 283 639 bytes); warnings only from
  third-party code and the deliberate strapping pin GPIO46.

### XMOS flash written from the ESP32 (`xmos_flasher`, 2 Oct 2026)

The bus switch U16 was in the hardware since rev A2; the software to use it is now there. The ESPHome
component `firmware/esphome/components/xmos_flasher/` writes the XU316 factory image
`firmware/xmos/ffva_v1.3.1_factory.bin` into U11 from the ESP32: GPIO46 holds the XU316 in reset and
switches U16, the ESP32 drives the flash over SPI2 (GPIO3/4/39/40, 4 MHz), checks the JEDEC ID
(EF 40 16), QE = 1 and the protection bits, erases the **whole 1 MiB boot partition**, writes and reads
back every page, verifies the MD5 against `firmware/xmos/MD5SUMS` and that the rest of the partition
is FFh, releases the bus and restarts. The data partition above 1 MiB is not touched; the status
registers are only read. The image is embedded at compile time; the build fails on an MD5 mismatch.

* **Trigger:** two steps in Home Assistant — switch "XMOS-Flash freigeben" (falls back after 60 s),
  then button "XMOS-Flash schreiben". Allowed on **USB alone** or on 14 V (changed on 2 Oct 2026; it
  was refused without PVDD before). Conditions: the device has been up for 30 s and did not last
  restart from a brown-out — a plausibility check, because no `+5V`/VBUS voltage is readable by the
  ESP32 — and all LEDs are held off while writing. Load during the write ≈ 0.22 A typical, ≈ 0.40 A
  with a Wi-Fi transmit burst (U11 programming 25 mA max., XU316 in reset); table in the component
  README, section "Supply".
* **Origin and licence:** derived from FutureProofHomes/Satellite1-ESPHome, commit `8f8906c`
  (2 Oct 2026), components `memory_flasher` by Mischa Siekmann. Its `LICENSE` (blob `746e0ab`) is the
  ESPHome licence: C/C++ files "published under the GPLv3 license", Python under MIT, with the GPL
  version 3 text attached; "or any later version" appears only in the GPL's own how-to-apply
  appendix, not as a grant. Hence **GPL-3.0-only** for `xmos_flasher.h/.cpp` and `flash_plan.h`
  (`LICENSES/GPL-3.0-only.txt`), **MIT** for `__init__.py`, both naming the original author.
* **Checked:** host test `firmware/esphome/tests/test_xmos_flasher.py` 6/6 against a simulated
  W25Q32JV (wrong JEDEC ID, QE = 0, protection bits, stuck bit, busy flash, oversize image, odd
  lengths); `esphome compile` without a warning from the component; a line-by-line review against
  Satellite1. **Not yet run on hardware** — bring-up steps in the build notes (first board).

### Wi-Fi set-up over Bluetooth (Improv) and MPR121 electrodes (2 Oct 2026)

* **BLE Improv as on Voice PE** (`home-assistant-voice.factory.yaml`, commit `d4e6fa43d6`):
  `esp32_ble` + `esp32_improv` with `authorizer: action` — the centre touch key (MPR121 channel 1)
  confirms a provisioning request, as `center_button` does on Voice PE. Bluetooth is switched off
  5 s after Wi-Fi connects and back on when Wi-Fi drops; the voice assistant waits for Bluetooth to
  be off before it starts (Voice PE's `va_connected_wait_for_ble`). The LED states for Improv were
  already in the YAML. Cost: firmware 2 600 751 → 2 941 675 bytes (36.2 %), RAM 43.6 → 49.9 %.
* **MPR121 ELE3–ELE11 are not open.** They share one net with **R73, 1 MΩ to GND** — the same as the
  Gen1 basis `7de6eec6`. The MPR121 datasheet (Rev. 4, 02/2013) has no pin rule for unused
  electrodes; it states that electrodes not enabled in the ECR and GPIOs not enabled are high
  impedance (section 5.14, GPIO), and that enabling only the used channels saves scan time
  (section 5.11). Auto-configuration is not used (ESPHome leaves register 0x7B at 0). ESPHome
  enables the electrodes as a range and never fewer than ELE0–ELE3 (`max_touch_channel` at least
  3, ECR = 0x84), so ELE3 — the common net — was measured as well, without effect on the three
  keys but for nothing. A boot action now writes ECR = **0x83** (ELE0–ELE2) after the component's
  set-up. No design change.

## 9. Production data (`production/`)

This folder is new. See `README.md`, section "This fork".

* **`production/jlcpcb/`**
  * `gerber_jlcpcb.zip`: 4 copper layers, masks, paste, silkscreen, outline, Excellon PTH/NPTH.
  * `BOM_JLCPCB.csv`: 83 rows, one row per LCSC number.
  * `CPL_JLCPCB.csv`: 221 placements.
  * `cpl_corrections.csv`: the 19 corrections.
  * `ROTATION_CHECK.md`: the target state for the preview check.

  The CPL follows the Fabrication Toolkit logic. 19 rows are corrected against the EasyEDA
  footprints JLCPCB uses: U14, U6, U3, U7, C89, U4, U5, U12, U13, U15, Q2, U2, J5 and U1 for
  rotation, and J1, X1, LED1, LED6 and POWER_IN1 for position.
* **`production/pcbway/`**
  * `BOM_PCBWay.xlsx` / `.csv`: manufacturer and MPN.
  * `positions_kicad.csv`: plain KiCad export (`--exclude-dnp`), the 221 populated parts; no
    JLCPCB corrections are applied.
  * `assembly_drawing.pdf`: top view, and bottom view mirrored.
  * `ASSEMBLY_FORM_COUNTS.md`: figures for the assembly form.

**Rev A1 production data** (after B6, G4b, the teardrop update, V1, V2 and V3) is in a separate folder,
**`fertigung_rev_a1/`**. The files in `production/` are left as they were, for the state
before B6.

* `fertigung_rev_a1/jlcpcb/gerber_jlcpcb.zip` was generated from the zone-filled board with the
  same options as before. Compared with `production/`:
  * **All four copper layers** change, because of the board-wide teardrops, the moved vias
    (V1, V3) and the larger thermal holes (V2).
  * **F.Cu** also changes at the widened RF traces (G4b).
  * **B.Cu** also changes around U12, where pad 1 now joins the GND fill (B6).
  * The PTH drill file changes, because eight vias moved (V1, V3) and 32 thermal holes are now
    0.3 mm (V2). Masks, paste, silkscreen and outline are identical apart from the date
    lines.
* `fertigung_rev_a1/pcbway/positions_kicad.csv` was regenerated (`--exclude-dnp`); its
  content is identical.
* BOMs, the JLCPCB CPL with its corrections, the rotation check, the assembly drawing and the
  form counts are copied unchanged. No part and no position changed.

## 10. Audit fixes before ordering (rev A2, 1 Oct 2026)

An independent audit of the rev A2 end state (`AUDIT_REV_A2.md`, working notes) found two
critical and several medium issues. They are fixed here, one commit each. K1 (PBTL output pairing)
is listed in section 3, K2 (J4 pin-out) under "J4 is now a pad field" below.

| Audit | What | Why / evidence | Commit |
|---|---|---|---|
| M1 | **C105, C106 (100 nF) added from AVIN to GND at U3 and U7**, on B.Cu right under each converter, each reached through one via next to the AVIN pin (pin 10). C105 is a 50 V part (`+14V`, rule A3), C106 16 V (`+5V`). There is no room on F.Cu: the courtyards of U3/C3 leave 0.26 mm, of U7/C14 0.02 mm. | TPS62130 datasheet (SLVSAG7F) p. 16: "it is required to place a capacitance of 0.1 μF from AVIN to AGND, to avoid potential noise coupling" | see git log |
| M2 | **U6 (TPS62065): C100 22 pF → 120 pF** (FH 0402CG121J500NT, C0G, LCSC C40059) and **C20 10 µF → 4.7 µF** (Samsung CL21A475KAQNNNE, LCSC C1779, same 0805 footprint). | TPS62065 datasheet (SLVS833E): feed-forward zero f = 1/(2π·R1·Cff) = 25 kHz (eq. 3/4) → 125 pF; with 22 pF the zero sat at 142 kHz, with 120 pF at 26 kHz. Effective output capacitance must stay within 4.5–22 µF (table 7.3): VDD carried 22.3 µF (24.3 µF at +10 %), now 17.0 µF (18.7 µF). | see git log |
| M3 | **C107 (10 µF X5R, 0603, LCSC C19702) added on `VDDIO`** of the XU316, on F.Cu at 143.0 / 65.94, 2.4 mm from VDDIO pin U10.38, tied to C56.1 and through its via to the VDDIO ring on In2. | XU316 datasheet p. 27 asks for a bulk capacitor of at least 10 µF per supply; `VDDIO` had only 100 nF parts behind the 120 Ω bead FB4, the nearest larger capacitor (C61) was 42 mm away. | see git log |
| M11 | **C108, C109 (100 nF) added at the VDD pins of MK1 and MK2**, behind the 100 Ω series resistors R62/R63 (which now form a 15.9 kHz low-pass with them). Both on F.Cu: the back side around the microphone holes is kept clear (board-edge bulge r 3.8 mm, probably for the gasket). For C109 the `VDD_MIC` track to R63 was re-routed around the new part and a GND stitching via moved from 169.6 / 93.5 to 169.0 / 94.9. | T3902 datasheet p. 15: "Decouple the VDD pin … with a 0.1 µF capacitor … as close to VDD as the PCB layout allows"; until now the only capacitors (C71/C72) sat before R62/R63. | see git log |
| M14 | **5 V main path widened:** `+5V_SW` from L1 to U18 (VIN) and `+5V` from U18 (VOUT) to the vias now 0.8 mm instead of 0.3 mm, and **four vias instead of one** into the `+5V` plane on In2. | IPC-2221: 0.3 mm × 35 µm carries 1.0 A at 10 K rise against a load of up to 1.7 A by datasheet limits; now 2.0 A (track) and 3.0–3.8 A (vias). The limit is the load switch U18 (LM66100, 1.5 A continuous). | see git log |
| M15 | **XU316 core feed (`VDD`) on In2 widened from 0.5 to 0.9 mm**, and all three `VDD` vias at the converter now join it on In2 (before only one). | IPC-2221 (inner layer, 0.5 oz): 0.395 A at 10 K before, 0.605 A now; at the XU316's budgetary 830 mA the rise drops from 54 K to 20.5 K, the drop from 9.4 to 5.2 mV. Wider does not fit through the gap in the `VDDIO` ring. Typical core current (225 mA) gives 1.1 K. | see git log |
| M16 | **USB VBUS branch from J1 to FB1 widened**: the two In2 tracks from 0.25 to 0.6 mm (they merge into one band of about 1.2 mm), the B.Cu link to FB1 likewise. | IPC-2221 (inner layer, 0.5 oz): 0.48 A at 10 K rise before, 0.90 A now; at 0.8 A the rise drops from 32 K to 7.6 K. | see git log |
| M18 | **L1/L2 land pattern matched to the ordered part.** New footprint `Inductor_SMD:L_Bourns_SRP4020TA` (pads 1.5 × 2.4 mm at ±1.85 mm, outer 5.2 mm) replaces `L_Cenker_CKCS4020`, whose pads ended under the body of the Bourns part. Field `Saturation` corrected from 4.2 A to 6 A. Test point TP17 (unpopulated) moved up 0.35 mm to clear the larger courtyard. | Bourns SRP4020TA datasheet, "Recommended Layout" (5.2 / 2.2 / 2.4 mm) and product table (2R2M: Isat 6.0 A). The matching Cenker part (C5291811) is weaker (3.4 A, ±30 %). | see git log |

## 11. Pin-audit fixes before ordering (rev A2, 1 Oct 2026)

A second independent audit went through every pin of U8 (ESP32-S3), U10 (XU316) and U14 (TAS5805M)
and through all function chains (pin audit, working notes `PIN_AUDIT_REV_A2.md`). It found no
critical hardware issue. The changes below were decided before ordering, one commit each; the
rows from U10-B1 on were added on 2 Oct 2026, when every remaining point was decided (see "Every open
point decided").

| Pin audit | What | Why / evidence | Commit |
|---|---|---|---|
| U8-B2 → H1 | **Y1 (40 MHz crystal) replaced by a ±10 ppm part:** JLYE Y201640MDBCX, LCSC C49158179 (3 014 in stock on 1 Oct 2026), same SMD2016-4P package and pin-out (1/3 crystal, 2/4 GND), same load capacitance 9 pF, so C26/C27 (12 pF) stay. The `Tolerance` field said "10ppm" although the fitted part (Yajingxin TAXM40M4ZCBCDT2T, C424431) is ±20 ppm; corrected. | Espressif ESP32-S3 Hardware Design Guidelines 1.3.5: "the accuracy of the selected crystal should be within ±10 ppm". JLYE datasheet (LCSC): tolerance ±10 ppm at 25 °C, stability ±20 ppm over −40…+85 °C, ESR ≤ 60 Ω (31–48 MHz), C0 ≤ 3 pF, drive ≤ 100 µW. Old part per LCSC: ±20 ppm / ±20 ppm. | see git log |
| K-B6 → H2 | **R72 (REXT of the MPR121) 200 kΩ → 75 kΩ 1 %**, UNI-ROYAL 0402WGF7502TCE, LCSC C25798 (JLCPCB "preferred extended", no setup fee; 45 660 in stock on 1 Oct 2026). Same 0402 footprint, value change only. | MPR121 datasheet pin 7: "Connect a 75 kΩ 1% resistor to VSS to set internal reference current". With 200 kΩ all charge currents scale by 0.375; ESPHome's `mpr121` uses fixed charge settings (no auto-configuration), and the pin audit's estimate put a finger touch at 2–8 counts against `touch_threshold: 12`. See "REXT at the MPR121" below. | see git log |
| U8-B7, K-B13 → H3 | **R81 (10 kΩ, 0402, LCSC C25744) added from `LED_DATA_3V3` to GND** at the input of the level shifter U19 (74AHCT1G125), on B.Cu at 116.1 / 84.9 (90°), pad 1 tied by a 0.66 mm track to the existing via at U19 pin 2, pad 2 in the GND fill. | Until the ESP32 configures GPIO21 (reset, ROM boot), the pin floats, and U19 then passes an undefined level to six SK6812 that sit on +5 V permanently — random colours or a lit ring at power-up. The 74AHCT1G125 input has no internal pull (datasheet: input leakage only); 10 kΩ pulls it low, and GPIO21 drives 3.3 V into it at 0.33 mA. | see git log |
| U10-B2 → H4 | **C17 (output of the 1.8 V LDO U5) 4.7 µF → 10 µF**, Samsung CL10A106KP8NNNC, X5R 10 V, LCSC C19702 (JLCPCB basic part), same 0603 footprint. `+1V8` feeds VDDIOB18 and USB_VDD18 of the XU316 and the JTAG reference on J4. | XU316 datasheet (XM014429B) section 13, p. 27: a bulk capacitor of at least 10 µF on each supply; `+1V8` had 4.7 µF as its largest part. The TLV70018 is stable with any effective output capacitance ≥ 0.1 µF and ESR < 200 mΩ (TLV700 datasheet 8.2.2.1), no upper limit; charging 10 µF at the 220 mA minimum current limit takes about 80 µs. | see git log |
| U8-B4 → H5 | **No external pull-down on GPIO45 — note only, no room.** Pin 51 sits between the `XU316_RST` escape (0.175 mm from the pad end) and the crystal tracks on F.Cu; on B.Cu right underneath is U16 with a GND pad. A resistor would need the crystal area re-routed. GPIO45 stays unconnected and relies on its internal weak pull-down (45 kΩ typ.), which keeps VDD_SPI at 3.3 V. | ESP32-S3 datasheet table 3-1: the strapping value is set by the internal weak pull-down "if the pins are not connected to any circuit" (GPIO45 → 0); table 3-4: GPIO45 = 0 → VDD_SPI 3.3 V from VDD3P3_RTC; table 5-4: R_PD 45 kΩ. GPIO45 has no copper at all, so nothing can couple in. Fallback without hardware: the eFuses `VDD_SPI_FORCE` = 1 and `VDD_SPI_TIEH` = 1 fix 3.3 V regardless of GPIO45 (table 3-4) — one-time, only if a sample ever shows the wrong flash voltage. | note only |
| U10-B3 → H6 | **15 vias added in the exposed pads of U10 (XU316):** 11 in the GND paddle (now **16**), one in each of the four VDD paddles (now **4 each**). All 0.4/0.3 mm through vias like the existing ones, at least 0.7 mm centre-to-centre (hole-to-hole ≥ 0.4 mm, rule 0.25 mm), placed by DRC against everything on the other three layers (one candidate at 136.45 / 63.17 hit C51 on F.Cu and was moved to 137.85 / 65.32). | XU316 datasheet (XM014429B) section 13.4: "16 vias in a 4 x 4 grid" in the ground paddle and four per VDD paddle; there were 5 and 3. The five existing GND vias (a cross) were kept, so the 16 are not a regular grid. Copper check after filling: `VDD` on In2 keeps **one island** and its outer bands are unchanged (all new GND vias lie inside the area spanned by the five old ones); only the interior gets perforated (31.7 → 24.9 mm²). GND In1 2790.8 → 2788.8 mm², one island; GND F.Cu 2196.4 → 2194.9 mm², 21 → 21 islands. | see git log |
| U10-B1 (and M19) | **C63 100 nF → 1 µF** (Samsung CL05A105KA5NQNC, X5R 25 V, LCSC C52923, already in the BOM), same 0402 footprint — the reset RC of the XU316 (R49 10 k to `+1V8`) goes from τ = 1 ms to 10 ms. Value change only, no copper. | XU316 datasheet section 13, p. 27: VDDIO must be valid before `RST_N` is released. Calculated before: boot start at 3.6–4.8 ms with `+3V3` at 2.44–3.03 V (limit 2.97 V), violated in 5 of 6 corners; now release at 8.4–13.7 ms, `+3V3` stable by 4.94 ms. The `voice_kit` reset pulse (1 ms through Q2) still discharges C63 in ≤ 10 µs. | `5a8c1ce` |
| C98 | **C98 (VREG of the MPR121) 1 µF → 0.1 µF** (Samsung CL05B104KO5NNNC, X7R 16 V, LCSC C1525, already in the BOM). | MPR121 datasheet pin 5: "Connect a 0.1 μF bypass cap to VSS"; section Power Supply: "a separate 0.1 μF decoupling ceramic capacitor on VREG". | `5a8c1ce` |
| U8-B1 | **C110 added as an unpopulated (DNP) 0201 footprint**: shunt trap on `LNA_IN`, 1.0 pF C0G (Murata GRM0335C1H1R0BA01D, LCSC C85893), F.Cu 119.15 / 74.40, 180°, pad 1 with a 0.2 mm stub to `LNA_IN`, pad 2 to a new GND via at 118.35 / 74.40. `LNA_IN` itself unchanged. | Today's matching network is kept (mismatch loss 0.55–0.80 dB; a CLC would gain 0.14 dB) but does not attenuate the second harmonic (+0.3 dB relative); with C110 about −24 dB. Fitted only after the VNA and harmonic measurements — see "Radio approval". Netlist 248 → 249 parts, DRC 8 → 8, parity 0. | `852b458` |
| U14-B2 | **Firmware: register 0x53 = 0x60** (class-D loop bandwidth 80 → 175 kHz) in the `tas58xx` table. | SLASEH5D table 7-27: "With Fsw=768kHz, 175kHz bandwidth should be selected for high audio performance"; Fsw ≥ 3 × BW holds (768 ≥ 525 kHz). Patch documented in `firmware/esphome/PATCH.md`. | `c6b3fb3` |
| M6b | **MPN field of R68/R69** corrected from `0402WGF0000TCE` to `0805W8F0000T5E` (schematic and layout). | The part (LCSC C17477) and the BOMs were already right; only the field named a 0402 part. | `c6b3fb3` |
| K-B8, K-B9, K-B10, K-B14, U8-B6, U8-B12 | **Firmware:** sounds and wake-word models pinned, `min_version`, two microphone channels, GPIO reserve comment, PSRAM-ECC option and temperature sensor. | See section 8, "Decisions of 2 Oct 2026". `esphome config` valid, compile successful. | `d1a3583` |

## Bring-up order: power it from a bench supply first

Decision of 1 Oct 2026. The first time this board is powered, it is **not** connected to the base
plate.

1. **Nothing connected.** Resistance check from each rail to ground, board unpowered: `+14V`,
   `+5V`, `+5V_SW`, `+3V3`, `ESP_3V3`, `+1V8`, `VDD`, `VDD_MIC`, `PVDD`. A short here is cheaper
   to find now than after 14 V has been applied.
2. **Bench supply on TP18 and a ground test point**, current limit set low — start at 100 mA.
   TP18 is `+14V` at 143.90 / 109.43; use TP21 (120.58 / 64.74) or TP22 (128.74 / 104.08) for
   ground. Bring the voltage up slowly and watch the current. The board draws its quiescent
   current through U3 and U7; the LEDs and the amplifier are off until firmware runs.
3. **Measure the rails in order:** TP18 `+14V` → TP3 `+5V_SW` → TP17 `+5V` → TP1/TP6 `+3V3`
   → TP4 `+1V8` → TP5 `VDD` (0.9 V) → TP23 `VDD_MIC` (3.3 V). Each one has to be right before
   the next matters. **TP3 against TP17** is the pair that shows whether the ideal diode U18
   conducts: about 55–65 mV of difference under load.
4. **USB next**, still without the base plate. On USB alone TP3 should read near 0 V while TP17
   carries about 4.9 V — that is Q4 having locked out U4's path into the 14 V rail. Then plug
   both in, in either order, and confirm nothing changes.
5. **The base plate last.** By then every rail, the ideal diode and the USB lock-out have been
   seen working, and the only new thing the base plate brings is the cable itself.

Why this order: a bench supply has a current limit, the base plate does not. Everything that can
be learned at 100 mA should be learned before 14 V arrives from a supply that will happily deliver
amps into a fault.

**Measurement plan.** Every point that could not be decided on paper (result MEASURE AT BRING-UP in
"Every open point decided") has a written procedure — what, with which instrument, target, limit, and
what follows from a deviation — in the maintainer's working notes (`HANDGRIFFE.md`, section
"Inbetriebnahme — Messvorschriften", in German, not published), as a complete plan with equipment list, target values with their datasheet references and a results
template, in twelve steps: 0 visual check against `fertigung/DREHLAGEN_PRUEFEN.md` (Y1 first) → 1 resistance
of every rail to ground → 2 bench supply at TP18, 100 mA limit, rails in order → 3 USB alone → 4 both →
5 flash the ESP32 → 6 XMOS image (bus flasher, XTAG4 as fallback) → 7 audio → 8 touch, LEDs, BLE Improv →
9 Wi-Fi against a reference board → 10 long run with temperature → 11 only then the base plate and the
housing. Two supply variants are written out: **A** with a bench supply (current limit 100 mA until
firmware runs, 500 mA up to Wi-Fi and LEDs, 1.5 A for audio) — recommended — and **B** without one: first
USB alone through a USB power meter (expected ≈ 0.2 A with firmware and LEDs off; above 0.3 A without
firmware means stop), then the 14 V adapter on TP18 through a 12 V halogen lamp in series (5 W for the
first power-up, about 0.45 A into a short; 20 W for audio, about 1.8 A into a short and ≈ 3.5 V drop at
0.8 A). The XMOS image can be written on USB alone (variant B, stage 1); the 14 V stage is for sound. Without the base plate the board is muted (MUTE floats high), so the microphones need a wire
from TP12 to ground on the bench. Target rails: `5V_SW` 5.00 V (4.83–5.18), `3V3` 3.27 V (3.16–3.37),
`1V8` 1.80 V (±2 %), `VDD` 0.906 V (0.886–0.926), `VMIC` 3.30 V (±1.4 %). The limits that matter most:

| Step | Measurement | Target | Limit / action |
|---|---|---|---|
| Rails | XU316 power-on, 4 channels (`+3V3` TP1, `+1V8` TP4, VDD TP5, `RST_N` J4.10) | when `+1V8` passes 1.62 V, `+3V3` ≤ 1.98 V; `RST_N` released only after `+3V3` ≥ 2.97 V | otherwise check C63 |
| Rails | `ESP_3V3` before any eFuse is burned | ≤ 3.30 V | above → do not burn |
| USB | USB alone | speaker silent, `tas58xx` PVDD fault or set-up error in the log; mics, LEDs, Wi-Fi work | expected, not a defect |
| 14 V | `+14V` at TP18 when plugging in; under full load | peak ≤ 17 V; ≥ 8.5 V at full volume | never ≥ 20 V (U3 absolute maximum): do not use that base/adapter |
| 14 V | 14 V removed during playback | output Hi-Z once `+14V` ≤ 4.2 V, no spike > 1 V at the speaker | |
| Firmware | XU316 boot after reset | first stable LRCK < 2.5 s; log `[voice_kit] DFU version: 1.3.1` | > 3 s → `voice_kit` timing |
| Firmware | TAS5805M registers | 0x53 = 0x60, 0x37 = 0x09, 0x38 = 0x40, 0x68 = 0x03, 0x71 = 0x00 | 0x46 A/B test 0x01 / 0x11 |
| Audio | `I2S_BCLK`/`I2S_LRCK` at U14 pins 7/6, ≥ 500 MHz scope, spring ground | peak ≤ 3.8 V, undershoot ≥ −0.5 V | otherwise edge measure in XU316 firmware or a fit change |
| Audio | OUT_A+ at C74 at 1 W and 6.9 W | peak ≤ 18 V, undershoot ≥ −1 V | otherwise 100 nF at PVDD pins 27/28 |
| Audio | AVDD at C80 | ≥ 4.75 V within 5 ms of PDN↑, ripple < 50 mVpp | otherwise C80 → 1 µF |
| Audio | LRCK frequency; speaker R_DC at J5 | 48 000 Hz ± 1.9 Hz; 2.8–3.6 Ω | R_DC ≥ 1.5 Ω |
| Audio | Touch (MPR121 counts) with music at full volume | noise < 6 counts, touch ≥ 24 counts | raise thresholds per channel |
| Radio | VNA at C28 (MV-3); harmonics (MV-5); RSSI (MV-4) | \|Γ\| against 35 Ω ≤ −10 dB over 2.400–2.484 GHz; harmonics ≤ −30 dBm ERP; RSSI at most 6 dB below a reference board, ≥ −67 dBm at `output_power: 8.5dB` | MV-5 fails → fit C110 and re-tune ("Radio approval") |
| Long run | Air 2–3 mm above U8 in the closed housing, ≥ 2 h at full volume | ≤ 53 °C at 23 °C room | 65 °C − (35 °C − room); above 53 °C → `enable_ecc: true` |
| Long run | Amplifier faults after 30 min full load | GLOBAL_FAULT1 / CHAN_FAULT = 0 | |

## Rev A2 ordered (2 Oct 2026)

| | |
|---|---|
| Order | JLCPCB **W2026100221436791**, placed 2 Oct 2026 |
| Bare boards | **Y5-13602167A** — 5 pieces, 4 layers, stack-up **JLC04161H-7628**, surface finish **ENIG**, via covering **Epoxy Filled & Capped** (points 2 and 6 below) |
| Assembly | **SMT026100262223** — 2 boards, Standard PCBA, assembled on both sides |
| Total | **€415.24**, including shipping and import charges |
| Assembly preview | all 31 changed or new parts checked on 2 Oct 2026; U18, U16, U5 and Q4 correct without manual adjustment after the CPL correction ("Four rotations corrected after the JLCPCB preview"); Y1 placed by the order remark (point 7 below) |
| Part substitution | R35 = **C100510** (LIZ Elec CR0402FF6800G, 680 Ω 1 %) instead of C25130, ordered |
| JLCPCB confirmations | **Production file** approved on 5 Oct 2026 after comparing JLCPCB's CAM data with ours (panel with break-off tabs, see below). **Parts placement** approved on 5 Oct 2026 after a DFM query on LED polarity: JLCPCB's model placed LED2–LED5 (SK6812-EC20, bottom side) rotated by 180°; corrected by JLCPCB to +5V (pin 1) at the top right in their mirrored bottom view, LED1 confirmed. Production released, completion expected around 14 Oct 2026 |
| Files | Gerber/drill files in this release are byte-identical to rev-a2-ordered; the files uploaded to JLCPCB on 2 Oct were generated at 08:41 from the same design and differ only in the creation timestamp. |
| Panel | JLCPCB put the board into a frame for assembly: 5 mm rails top and bottom, a routed gap, mouse bites at the break-off points reaching up to 0.13 mm into the outline, V-score at the top and bottom extreme points of the outline. Copper stays ≥ 0.227 mm from the mouse-bite holes. Deburr the break-off points if needed (bring-up step 0) |
| Mirrored bottom view | JLCPCB's DFM pictures show the bottom side mirrored left-right (J1 top left, LED5 left, LED2 right), as KiCad's "flip board view"; target positions per LED in `fertigung/DREHLAGEN_PRUEFEN.md` |

The order was made from the design files tagged `rev-a2.1` in this repository. The tag
`rev-a2-ordered` marks the state with this section added and stands on the **same design and
manufacturing files** as `rev-a2.1`; only the documentation differs.

## Before you order: the seven things to get right

Each of these has its own section with the evidence; this is the short list to hand to a
fabricator or to check in the order form. Points 2 and 6 are **order options that have to be
selected**, and point 7 is **a remark to enter in the order form**, not just things to check.

| # | What | Why it matters |
|---|---|---|
| 1 | **0.10 mm minimum track width** must be fabricable | `UART_TX` and `UART_RX` use the net class `UART-eng` at 0.100 mm. JLCPCB does 0.09 mm on a 4-layer board without a surcharge; a house quoting 4 mil (0.1016 mm) would reject or surcharge them. See "When ordering: the board needs 0.10 mm minimum track width". |
| 2 | **Order the vias filled: JLCPCB option *Epoxy Filled & Capped*** | The board vias reach into **23 pads (58 vias, all same-net)**, measured after the pin-audit fixes of 2 Oct 2026: the via centre lies inside 14 pads — J6.11, R79.2, R80.1 (signal), C99.1, U11.6, L1.2 (supply), C47.2 and C60.2 (GND, above the U10 paddle; two of the vias added in H6), and the large pads of U8 (9 vias) and U10 (32 vias) — and in 9 more pads part of the drilled hole reaches into the solder-mask opening (C65.1, J1.B6, J4.4, J4.6, LED2.1, TP21, TP22, U19.2, U19.4). **Do not order these untented and unfilled.** In reflow an open via inside a signal pad wicks solder out of the joint and down the barrel; the joint is left starved, and on a 0.30 mm FPC pad like J6.11 there is nothing to spare. Filling and plating over gives a flat, closed pad surface — JLCPCB's own description is "filled with epoxy resin or copper paste and then plated over to achieve an opaque and smooth finish", and it "forms flat surface after plugging, suitable for BGA and SMT holes". Our vias are 0.30 mm drill / 0.40 mm diameter, inside the 0.15–0.55 mm range the process supports and well under the 0.5 mm above which JLCPCB accepts no complaints about incomplete filling. See "Vias inside pads" and "Vias in the large pads of U8 and U10". |
| 3 | **U11 must be an `IQ` part, not `IM`** | `W25Q32JVSSIQ` (LCSC C179173). The `IQ` order suffix has the QE bit **fixed to 1 at the factory**, so IO2 and IO3 work as data lines out of the box — which is what the XU316 needs to boot from quad SPI. The `IM` variant trades that for a `/RESET` pin and does not have QE fixed. Same package code `SS` (8-pin SOIC 208 mil) for both, so the footprint will not tell them apart. See "When ordering: the XMOS flash U11 stays at 4 MB". |
| 4 | **Seven via pairs sit at the 0.2 mm hole-to-hole limit** | 0.500 mm centre to centre with 0.300 mm drills leaves 0.200 mm of material. JLCPCB's limit for **same-net** vias is exactly 0.2 mm (`jlcpcb.com/capabilities/pcb-capabilities`), and all seven pairs are same-net vias on `+14V` (3 pairs), `+5V`, `+3V3`, `ESP_3V3` and `PVDD` (one each). It is inside the limit with nothing to spare, so a house with a 0.25 mm rule will flag it. They come from upstream. |
| 5 | **J1 needs confirming by hand** | The USB-C receptacle (Molex 1054500101, LCSC C134092) is stocked but JLCPCB flags it "process difficult" in the BOM check, where it has to be confirmed manually. No stocked alternative fits the footprint. |

| 6 | **Surface finish: ENIG**, not HASL | Decision of 1 Oct 2026. Five things on this board want a flat, planar finish: the **0.40 mm pitch** of U8, U10, U15 and U6, where HASL's uneven solder domes bridge; the **QFN thermal pads**, which need to sit flat; the **J4 spring-contact pad field**, where an XTAG adapter presses onto bare pads and HASL's bumps give unreliable contact; the **eighteen test points**, measured with a probe tip; and the **three touch electrodes** on B.Cu, which are large bare-copper rings that have to stay planar and corrosion-free for the MPR121 to see a stable capacitance. ENIG gives all five; HASL gives none of them. |
| 7 | **Order remark: `Y1 orientation per silkscreen pin-1 corner mark (top-left).`** | EasyEDA has no model for Y1 (C49158179, "Component not found", 2 Oct 2026), so the assembly preview shows only a placeholder and the part is placed by hand. A 90° error puts the crystal on the ground pads. The silkscreen corner mark and pad 1 (`XTAL_N`) are both at the top left, measured from the board. See "Y1 has no model in the JLCPCB preview". |

Beyond those seven: the stack-up is set to **JLCPCB JLC04161H-7628** (1.6 mm, 4 layers, 0.5 oz
inner copper).

**What the two options cost is not published.** JLCPCB states the technical terms for both on
`jlcpcb.com/capabilities/pcb-capabilities` and `jlcpcb.com/help/article/pcb-via-covering`, and the
surcharge list on `jlcpcb.com/help/article/in-what-cases-will-there-be-charged-extra` names neither
a via-filling fee nor an ENIG base price (all three retrieved 1 Oct 2026). Both amounts come from
the interactive quote tool, which needs an account — so **no figure is given here rather than a
guessed one**. Two things *are* established:

* Via filling is free and standard on 6-layer and above; on a **4-layer** board it is charged.
* The ENIG **area surcharge** does not apply to this board. JLCPCB charges "$0.8992/m² … for
  every 1% for the portion exceeding 30%" of exposed copper. Measured from the board: the solder
  mask openings are **393.0 mm² on F.Mask (473 pads) and 174.3 mm² on B.Mask (272 pads)**, together
  567.3 mm² against 7 423.1 mm² of board area over both sides — **7.64 %**. Every via on the board
  is mask-covered, checked rather than assumed: they contribute **0.0 mm² in 0 openings**. (The
  vias that sit inside pads are enclosed by those pads' openings and already counted there.)
  7.64 % is far below the 30 % threshold, so only the ENIG base price applies.

### What two boards cost

Standard PCBA, assembled on both sides, **two boards** (decision of the operator, 1 Oct 2026).
Component prices and classifications from JLCPCB's own parts API, retrieved **1 Oct 2026**; the
full table of all **86** lines is in `pruefung/e7_jlcpcb_2026-10-01.csv`. Quantities are
`max(need + loss allowance, minimum order)` per line, which is how JLCPCB bills — at two boards
that minimum dominates for most passives, so the component cost does not halve against five.

| Item | Cost | How it is made up |
|---|---|---|
| Setup fee | 51.12 $ | double-sided Standard PCBA, independent of quantity |
| Stencil | 16.42 $ | double-sided, independent of quantity |
| Feeder loading | **131.58 $** | 86 part numbers × 1.53 $ — Standard charges this for basic and extended alike, and it does not shrink with the order |
| Solder joints | 2.60 $ | 814 joints × 2 boards × 0.0016 $ |
| Components | 102.63 $ | 34 basic, 52 extended |
| **Assembly total** | **304.36 $** | **152.18 $ per board** |
| Bare boards | **not retrieved** | 4 layers, 69.2 × 69.2 mm outline, 2 pieces. JLCPCB publishes no price list for this — it comes from the interactive quote tool, so it is **not stated here rather than guessed**. |

Most expensive lines: U10 (XU316) 26.24 $, MK1/MK2 6.20 $, U8 (ESP32-S3R8) 6.11 $, U15 (MPR121)
5.38 $, AE1 (antenna) 5.12 $, U9 (W25Q128) 5.10 $, U3/U7 (TPS62130) 3.69 $, the eight 22 µF
3.52 $.

**Where the money goes at this quantity:** the three quantity-independent items — setup, stencil
and feeder loading — come to **199.12 $, almost two thirds of the total**. The feeder loading alone
(131.58 $) exceeds the entire component cost. Per board the fixed share is 99.56 $, which is why
two boards cost 152.18 $ each where five cost 82.84 $ each. Reducing the number of distinct part
numbers is the one lever that matters here — which is why the 100 nF consolidation was examined at
all. It turned out not to be available: see section 7 on C83/C88.

**The number of part numbers was 84 in an earlier version of this table and is 86.** The earlier
figure was counted before E7 corrected J6 and R80: both carried `C25744`, the number of a 10 kΩ
resistor, which was already in the list, so two numbers were hidden behind one. Three numbers were
also missing from the price file altogether — `C133796` (U5, from E5.2), `C25778` (R77) and
`C424659` (J6) — and one was stale, `C626087`, the MIC5365 that E5.2 replaced. All four fixed; 86
numbers now match the schematic, the layout and the generated BOM.

For comparison, at larger quantities the fixed share stops dominating: the component cost per board
falls to about 36.84 $ at 30 boards and 30.02 $ at 100 (figures from section 34.4 of the working
log, on the 24 Sep price basis).

## Open points before or at bring-up

### POWER_IN1: the pinout is now confirmed against a second source

The ten-way FFC to the base plate is wired **pad 1 and 3–6 to GND, pad 2 to MUTE, pads 7–10 to
+14V**, with the two shield tabs unconnected. That assignment came from the designer's prototype and
was long carried here as unverified: `upstream/PCB_connections.xlsx` covers J2, J3, J4 and the test
points but **not** this connector (checked again on 1 Oct 2026 by reading the sheet out in full),
the two prototype photos show the orange flat cable but not its conductors, and none of the 18
upstream discussions touches connector pinouts.

**It is now confirmed from an independent design.** [Onju Voice](https://github.com/justLV/onju-voice)
by Justin Alvey is a replacement board for the *same device* — its README says "just make sure you
get the 2nd gen" — so it meets the same base-plate connector. Its schematic
(`hardware/Onju-Home.SchDoc`, branch `master`, Altium, 796 672 bytes, retrieved 1 Oct 2026) has a
ten-way connector **J1** whose nets were read out of the file by following the wires from each pin:

| Pin | Onju Voice J1 | this board | |
|---|---|---|---|
| 1 | `GND` | `GND` | same |
| 2 | `MUTE` | `MUTE` | same |
| 3 | `GND` | `GND` | same |
| 4 | `GND` | `GND` | same |
| 5 | `GND` | `GND` | same |
| 6 | `GND` | `GND` | same |
| 7 | `14V` | `+14V` | same |
| 8 | `14V` | `+14V` | same |
| 9 | `14V` | `+14V` | same |
| 10 | `14V` | `+14V` | same |

**All ten pins agree.** Two independent designs for the same device arrive at the same assignment,
which is as good as this gets without a meter on an original. The second ten-way connector in that
schematic, J3, carries `CHIP_PU`, `GPIO0`, `TXD0`, `RXD0` and `VBUART` — that is its programming
header, not the base plate.

The pin-1 mark on our board is the 0.4 mm silkscreen circle at 143.560/117.651, 1.30 mm above
pad 1. If you still want to meter it, the quick version: continuity from pads 1, 3, 4, 5, 6 to the
barrel jack's outer contact; the mute slider moves exactly pad 2; pads 7–10 read about 14 V.

* **Physical checks:**
  * Touch electrodes against the enclosure touch zones (E2).
  * POWER_IN1 pin-out: **confirmed** against the Onju Voice schematic, all ten pins (see
    below). Metering it on an original is optional now, not required.
* **Documents still to verify:**
  * Land pattern of L6/L7 against the MetalLions datasheet.
  * Row pitch of the U1 fixing pads (2.0 mm in the footprint, about 2.1 mm in the Nidec
    drawing).
* **Done in rev A2:** the A4 back-feed is blocked by U18 and Q4 (E4). (The RF trace width was
  carried out in G4b, `9f4e9bd`.)
* **The XMOS flash (U11) is empty as delivered.** The board has to be programmed once before
  the XU316 will run. Over-the-air and I²C updates from the ESP32 only work once a factory
  image is in the flash. The two ways in are JTAG at J4 with an XTAG adapter, or a test clip
  on U11. With an XTAG, `xflash` loads a flash loader over JTAG into the XU316's RAM and writes U11
  from there (XTC Tools Guide XM-014363-PC v15.3, section 5.1.7); the third way, writing U11 from the
  ESP32 through U16, is wired but has no firmware yet (see "QSPI bus isolation uses one switch" below).
* **Assembly preview:** check the Y1 orientation in the JLCPCB preview; there is no EasyEDA
  footprint to compare against.

## Checked against Gen1, deliberately left as they are

Three findings from the review list turned out to be either the designer's own choice or
solvable in firmware. They are recorded here so nobody re-opens them without the evidence.

### REXT at the MPR121: was 200 kΩ, now the datasheet's 75 kΩ (finding 4, changed in H2)

R72 (200 k) sits between GND and `Net-(U15-REXT)` at U15 pin 7. The MPR121 datasheet says
"External Resistor – Connect a 75 kΩ 1% resistor to VSS to set internal reference current", so the
internal reference current is a factor 2.67 smaller than the datasheet's nominal, which shifts
electrode charge time and sensitivity.

**Gen1 uses the same value.** In the Gen1 netlist (`pruefung/gen1.net`) the MPR121 is U2, and
`Net-(U2-REXT)` consists of U2.7 and **R2 = 200k**. The touch block of this fork was taken from
Gen1 on purpose (BAUTEILE.md 2.6), and Gen1 works. The MPR121's charge current and charge time are
register-configurable, so the effect is compensated in firmware if it ever shows up.
**No change.** Worth measuring on the sample: touch sensitivity of the three electrodes.

**Audit 1 Oct 2026 (M10), kept as a note:** the independent audit flagged this again as a deviation from the datasheet (medium). It stays at 200 kΩ for rev A2, for the reasons above. If touch is unreliable on the sample, the fix is a value change only: R72 → 75 kΩ 1 %.

**Changed after the pin audit (1 Oct 2026, H2):** R72 is now 75 kΩ 1 % (C25798). ESPHome's `mpr121` component sets fixed charge current and time and does no auto-configuration, so the firmware compensation assumed above is not available without a custom component; the pin audit estimated a finger touch at 2–8 counts against the threshold of 12 with 200 kΩ. Gen1 may tune its registers differently; this fork follows the datasheet.

### No pull-up on the MPR121 interrupt (finding 11)

`TOUCH_IRQ` consists of exactly two nodes, U15.1 (`IRQ`, an open-collector output) and U8.7
(GPIO2). **Gen1 is identical** — there, `/ESP32-S3R8/TOUCH_IRQ` is U2.1 and U6.7, also without a
resistor.

The ESPHome `mpr121` hub component has **no interrupt-pin option at all** (esphome.io, retrieved
30 Sep 2026: the hub takes only `address`, `id`, `touch_debounce`, `release_debounce`,
`touch_threshold`, `release_threshold`), so the line is not read; the component polls over I²C.
What remains is that GPIO2 would float. `nest-mini-v2-voice.yaml` therefore declares an internal GPIO
binary sensor on GPIO2 with `pullup: true`, which switches in the ESP32-S3's internal weak pull-up
of **typically 45 kΩ** (ESP32-S3 Series Datasheet v2.2, table 5-4 "DC Characteristics", p. 65).
**No hardware change.**
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

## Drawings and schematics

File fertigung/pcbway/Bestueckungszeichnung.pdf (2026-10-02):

# L3C24C28 C27 C26 C40 C31 C32C37R21 C29

# R22 R⁷⁴ L1

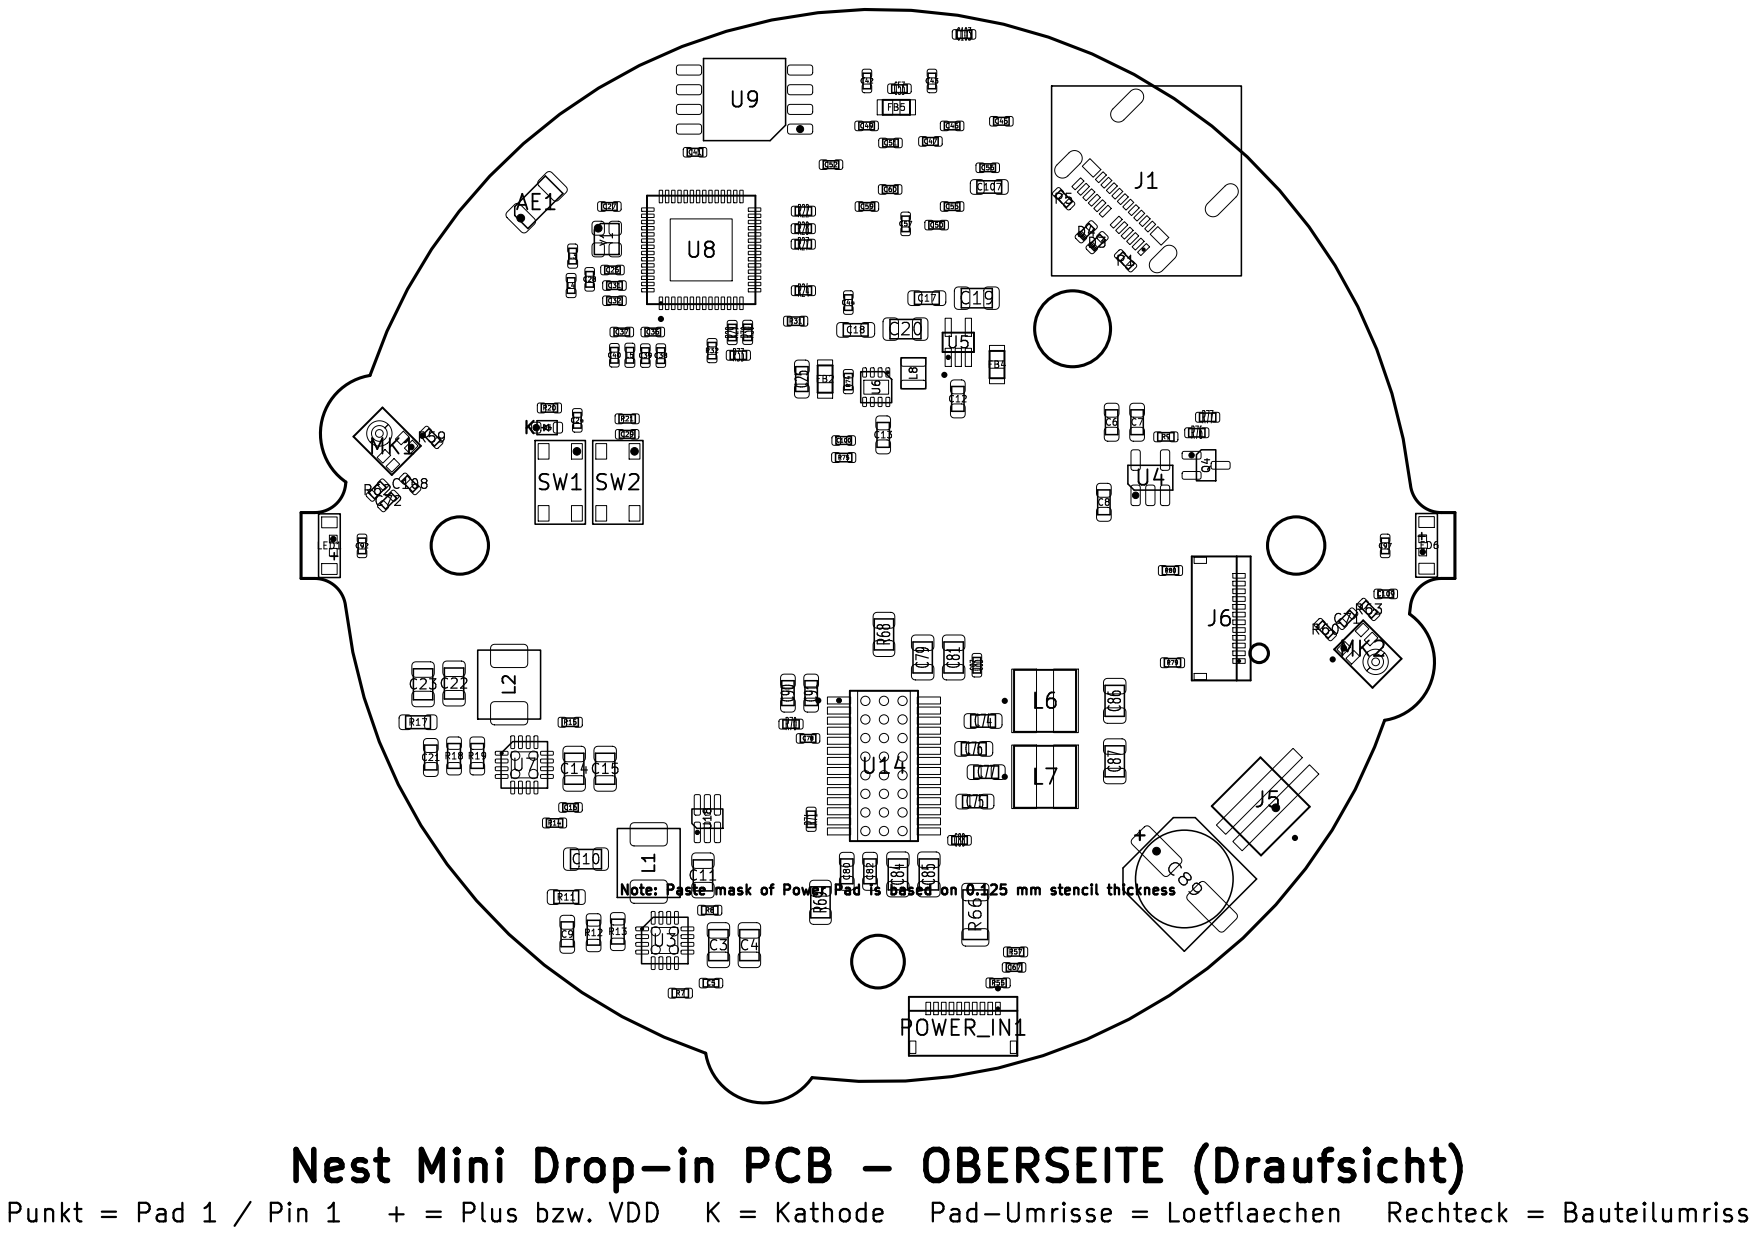
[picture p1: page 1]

# C33 R49 C63 R48 R47 R50 C96 C30 R65

## C35 C66 C68 C70 C95

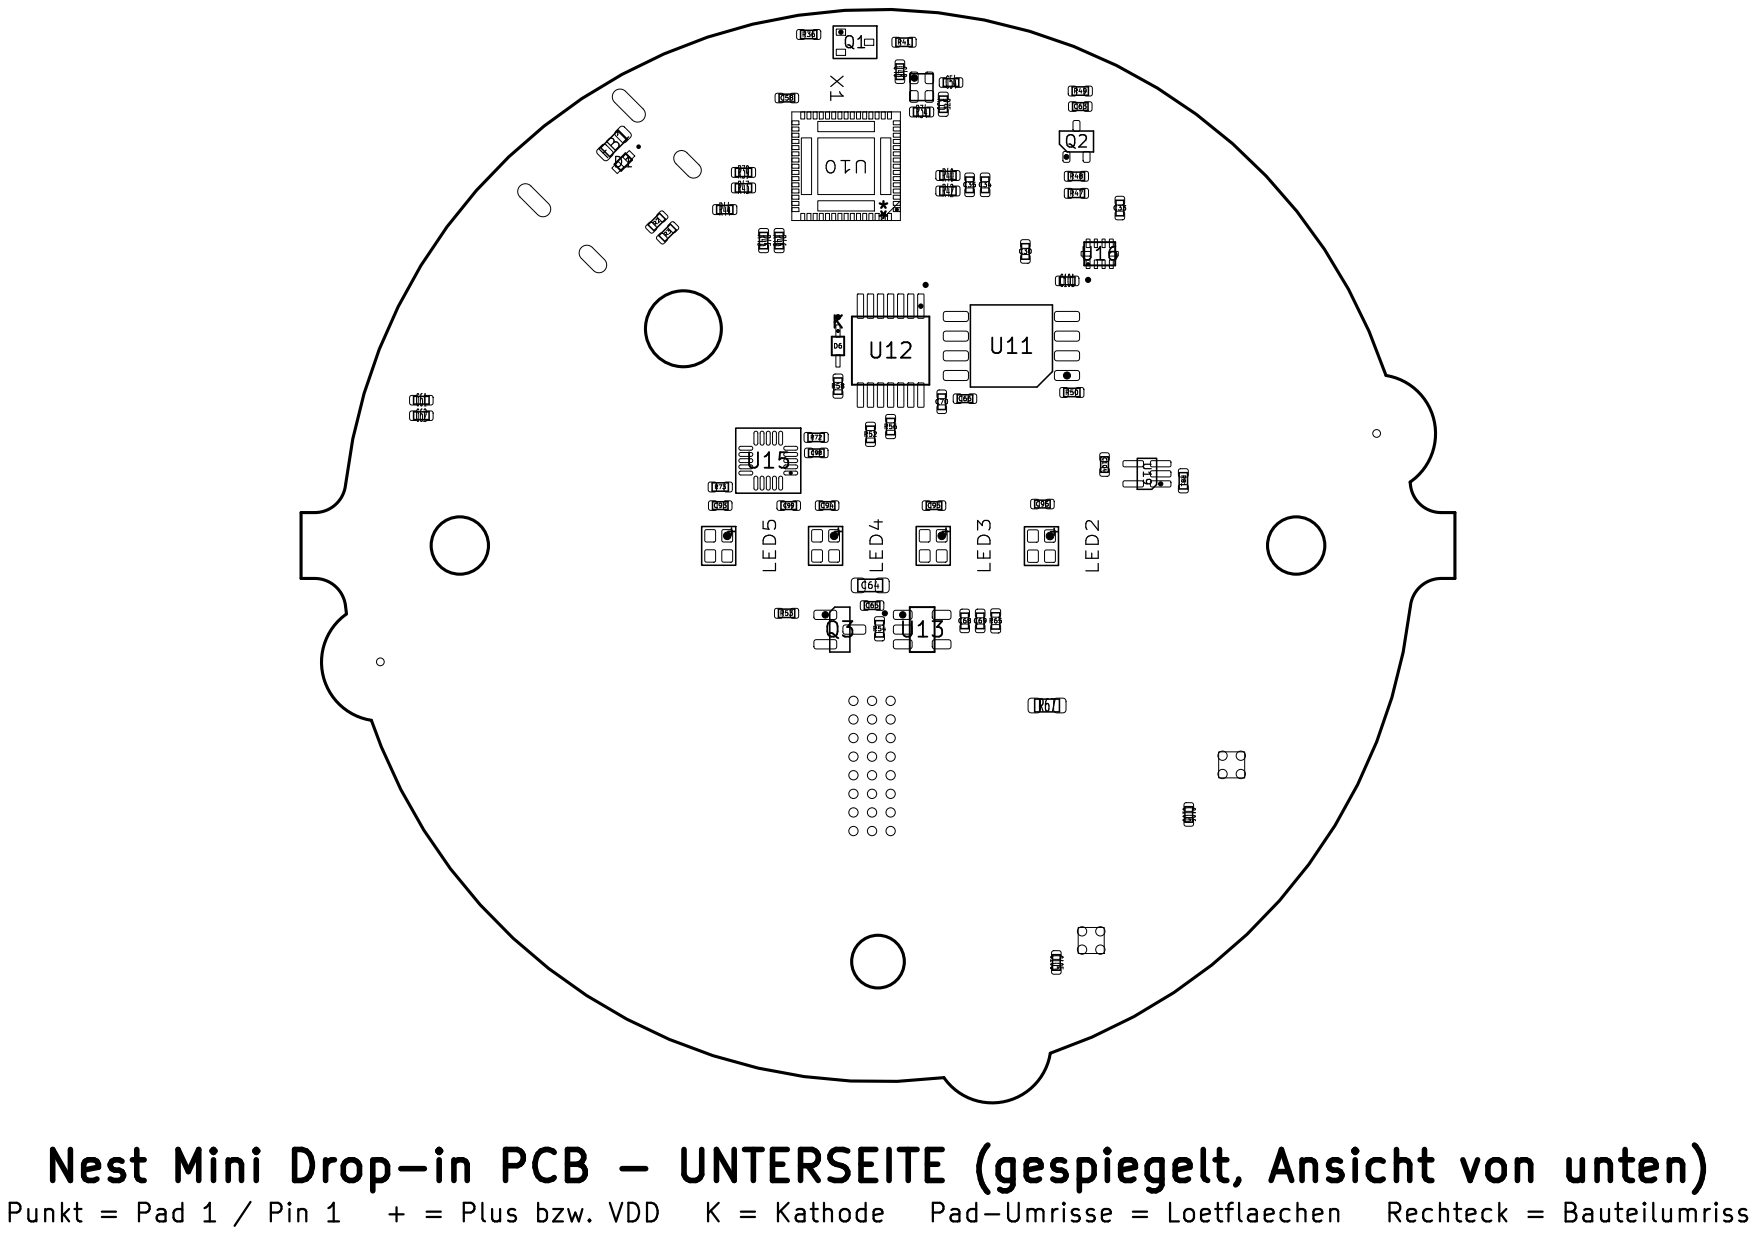
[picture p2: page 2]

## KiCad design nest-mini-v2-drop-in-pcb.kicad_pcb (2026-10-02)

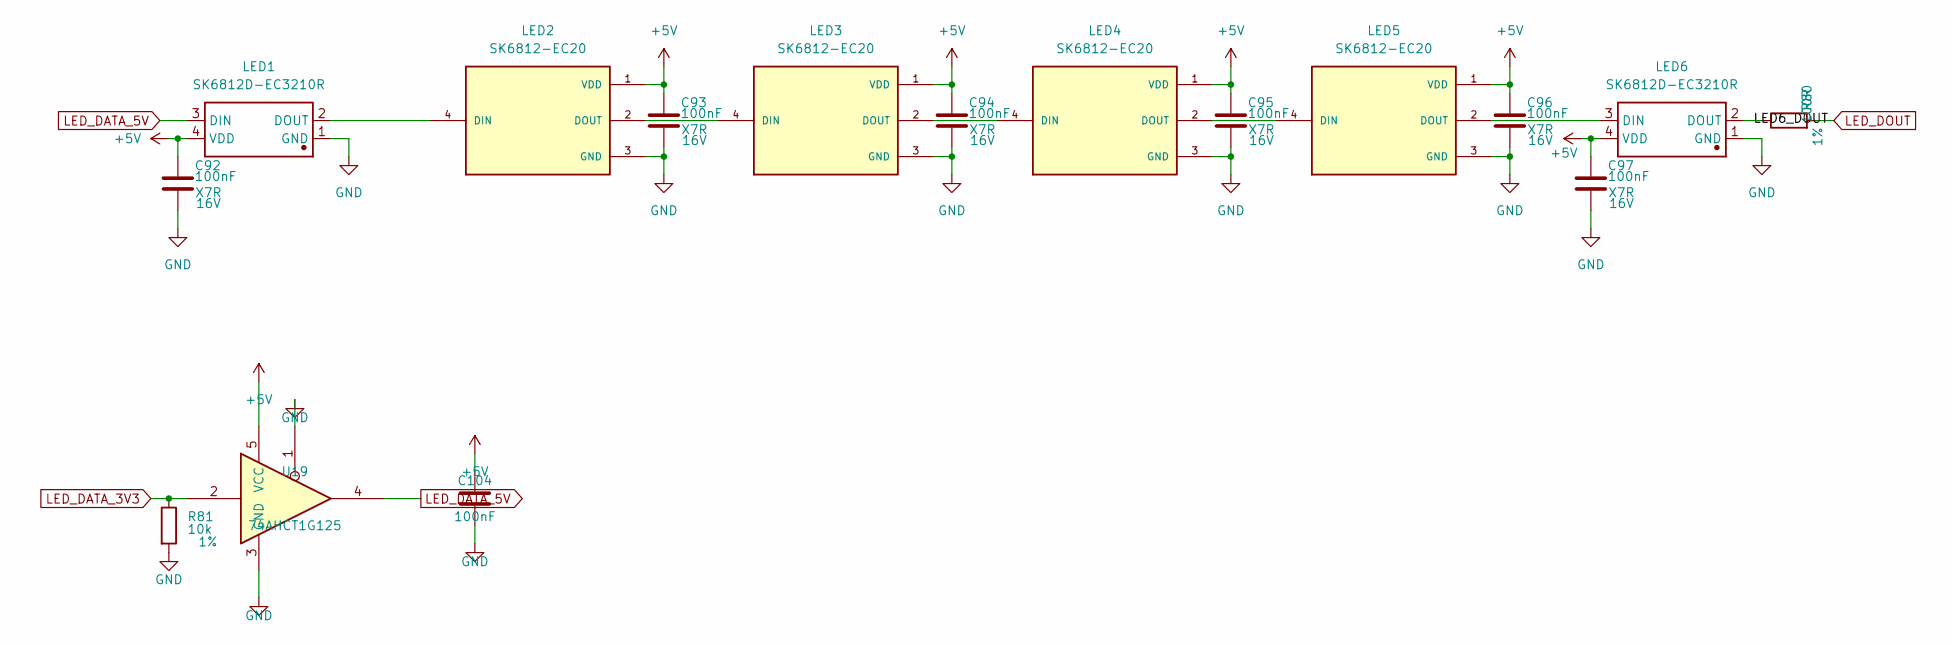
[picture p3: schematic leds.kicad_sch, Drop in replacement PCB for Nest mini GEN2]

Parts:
C92, C93, C94, C95, C96, C97: 100nF; C_0402_1005Metric; Voltage 16V; LCSC Part # C1525
C104: 100nF; C_0402_1005Metric; Manufacturer Part CL05B104KO5NNNC; LCSC Part # C1525
LED1, LED6: SK6812D-EC3210R; LED-SMD_4P_SK6812D-EC3210R; Manufacturer Part SK6812D-EC3210R; LCSC Part # C2890041
LED2, LED3, LED4, LED5: SK6812-EC20; SK6805-EC20; Manufacturer Part SK6812-EC20; LCSC Part # C2909058
R80: 100R; R_0402_1005Metric; Tolerance 1%; Manufacturer Part 0402WGF1000TCE; LCSC C25076
R81: 10k; R_0402_1005Metric; Tolerance 1%; Manufacturer Part 0402WGF1002TCE; LCSC C25744
U19: 74AHCT1G125; SOT-353_SC-70-5; Manufacturer Part 74AHCT1G125GW,125; LCSC Part # C12495

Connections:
+5V: C92.1, C93.1, C94.1, C95.1, C96.1, C97.1, C104.1, LED1.4 (VDD), LED2.1 (VDD), LED3.1 (VDD), LED4.1 (VDD), LED5.1 (VDD), LED6.4 (VDD), U19.5 (VCC); also elsewhere on the board
/LEDs/LED6_DOUT: LED6.2 (DOUT), R80.1
GND: C92.2, C93.2, C94.2, C95.2, C96.2, C97.2, C104.2, LED1.1 (GND), LED2.3 (GND), LED3.3 (GND), LED4.3 (GND), LED5.3 (GND), LED6.1 (GND), R81.2, U19.1, U19.3 (GND); also elsewhere on the board
LED_DATA_3V3: R81.1, U19.2; also elsewhere on the board
LED_DATA_5V: LED1.3 (DIN), U19.4
LED_DOUT: R80.2; also elsewhere on the board
unnamed: LED1.2 (DOUT), LED2.4 (DIN)
unnamed: LED2.2 (DOUT), LED3.4 (DIN)
unnamed: LED3.2 (DOUT), LED4.4 (DIN)
unnamed: LED4.2 (DOUT), LED5.4 (DIN)
unnamed: LED5.2 (DOUT), LED6.3 (DIN)

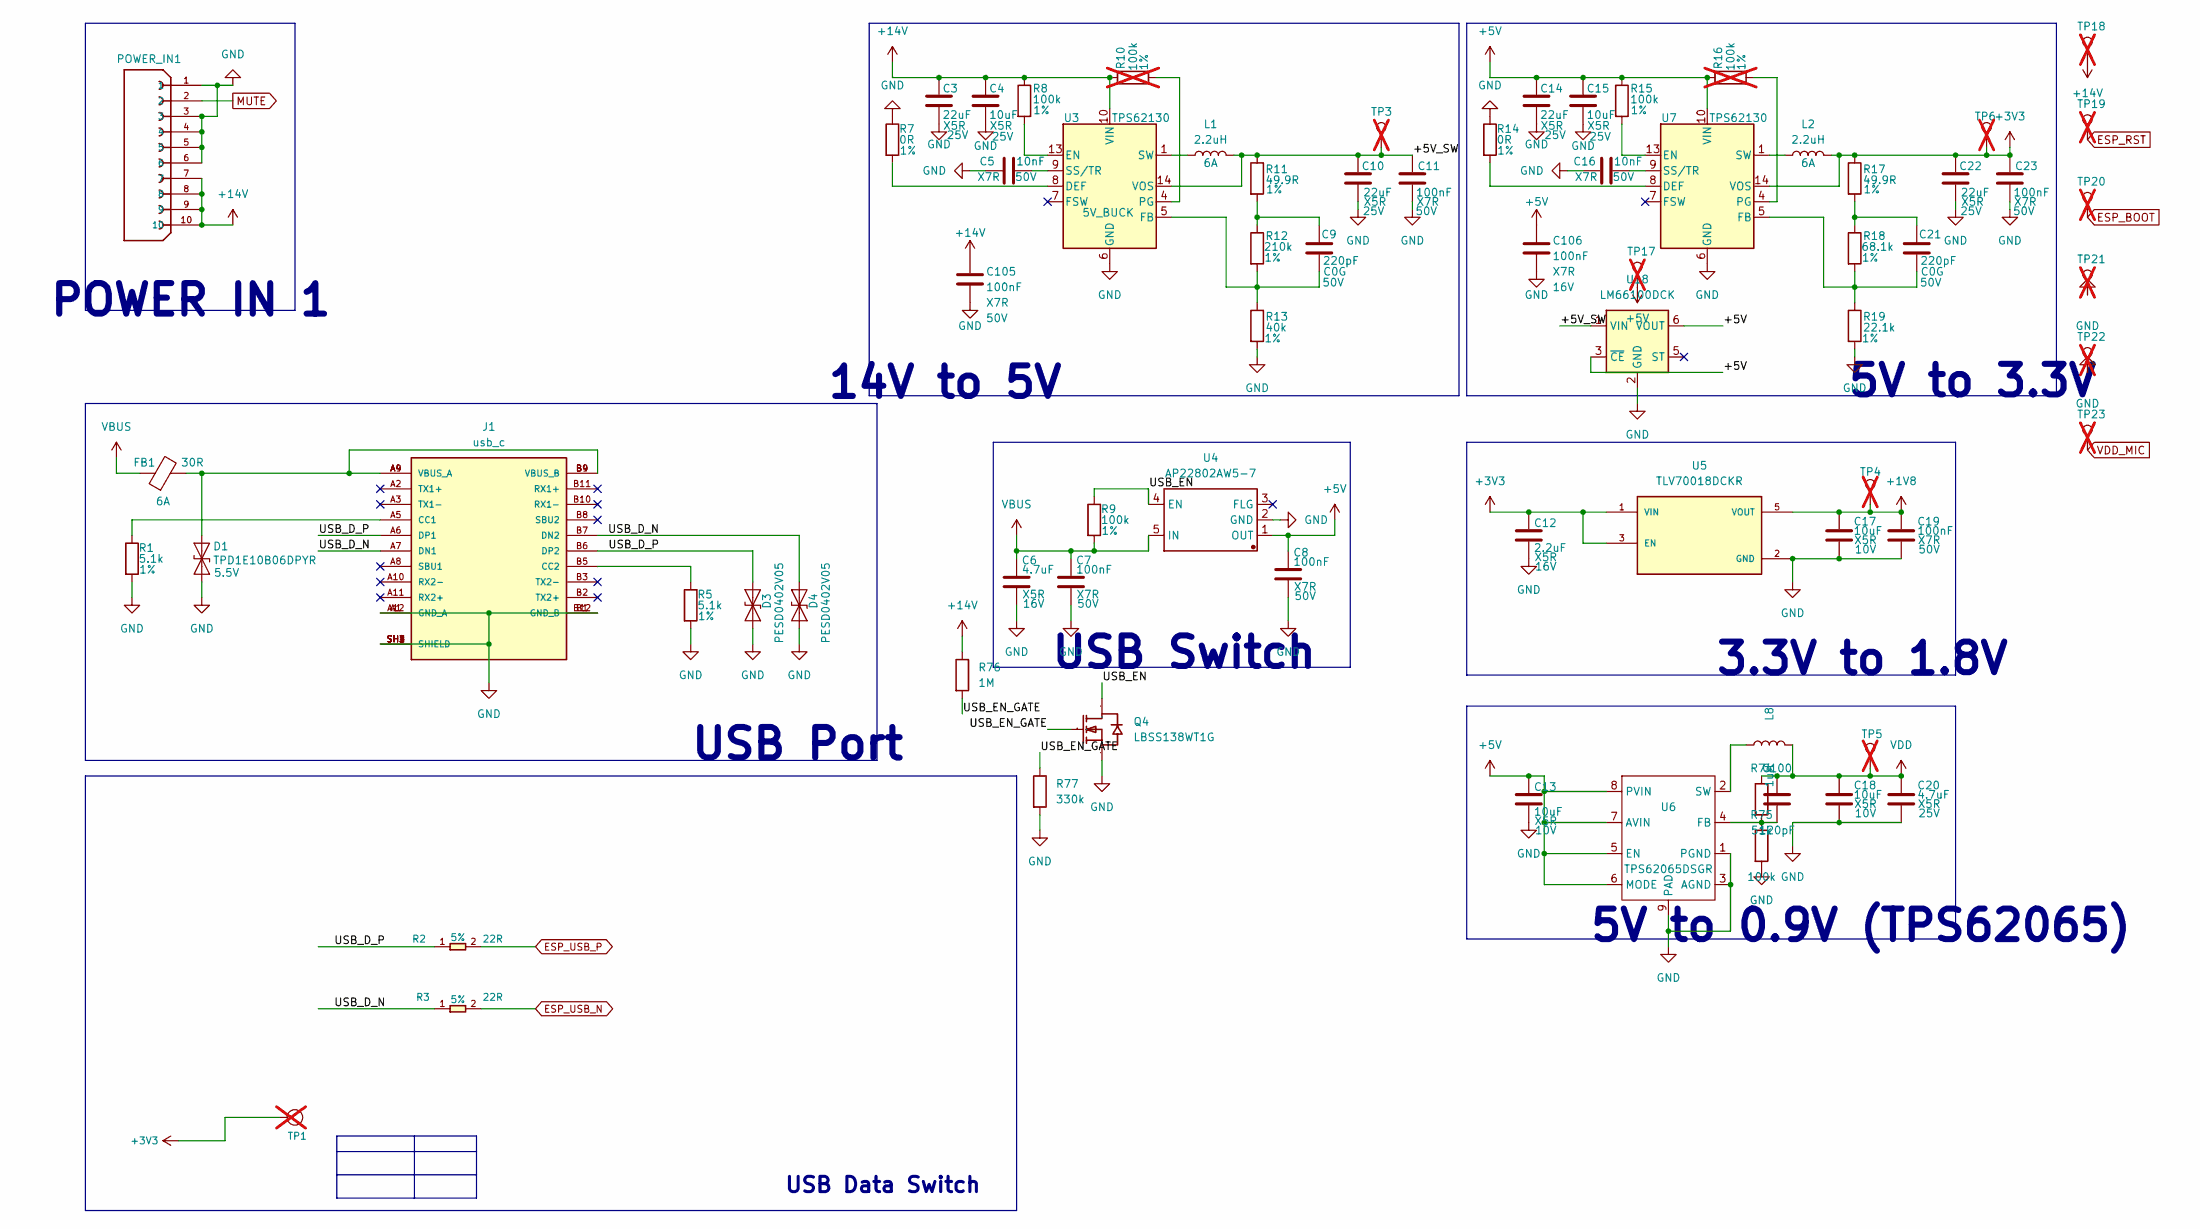
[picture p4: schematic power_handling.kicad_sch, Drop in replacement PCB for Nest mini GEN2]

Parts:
C3, C10, C14, C22: 22uF; C_0805_2012Metric; Voltage 25V; Manufacturer Part CL21A226MAQNNNE; LCSC Part # C45783
C4, C15: 10uF; C_0805_2012Metric; Voltage 25V; Manufacturer Part CL21A106KAYNNNE; LCSC Part # C15850
C5, C16: 10nF; C_0402_1005Metric; Voltage 50V; Manufacturer Part CL05B103KB5NNNC; LCSC Part # C15195
C6: 4.7uF; C_0603_1608Metric; Voltage 16V; Manufacturer Part CL10A475KO8NNNC; LCSC Part # C19666
C7, C8: 100nF; C_0603_1608Metric; Voltage 50V; Manufacturer Part CC0603KRX7R9BB104; LCSC Part # C14663
C9, C21: 220pF; C_0603_1608Metric; Voltage 50V; Manufacturer Part 0603CG221J500NT; LCSC Part # C156398
C11, C19, C23: 100nF; C_0805_2012Metric; Voltage 50V; Manufacturer Part CC0805KRX7R9BB104; LCSC Part # C49678
C12: 2.2uF; C_0603_1608Metric; Voltage 16V; Manufacturer Part CL10A225KO8NNNC; LCSC Part # C23630
C13, C17, C18: 10uF; C_0603_1608Metric; Voltage 10V; Manufacturer Part CL10A106KP8NNNC; LCSC Part # C19702
C20: 4.7uF; C_0805_2012Metric; Voltage 25V; Manufacturer Part CL21A475KAQNNNE; LCSC Part # C1779
C100: 120pF; C_0402_1005Metric; Voltage 50V; Manufacturer Part 0402CG121J500NT; LCSC Part # C40059
C105: 100nF; C_0402_1005Metric; Voltage 50V; Manufacturer Part CL05B104KB54PNC; LCSC Part # C307331
C106: 100nF; C_0402_1005Metric; Voltage 16V; Manufacturer Part CL05B104KO5NNNC; LCSC Part # C1525
D1: TPD1E10B06DPYR; TPD1E05U06DPYR; Voltage 5.5V; Manufacturer Part TPD1E10B06DPYR; LCSC Part # C48260
D3: PESD0402V05; D_0402_1005Metric; Part C19626254; LCSC Part # C19626254
D4: PESD0402V05; D_0402_1005Metric; Manufacturer Part PESD0402V05; LCSC Part # C19626254
FB1: 30R; R_0603_1608Metric; Part number BLM18PG300SN1D; LCSC Part # C17305
J1: usb_c; USB-C-SMD_TYPE-C-USB-18; Manufacturer Part 1054500101; LCSC Part # C134092
L1, L2: 2.2uH; L_Bourns_SRP4020TA; Manufacturer Part SRP4020TA-2R2M; LCSC Part # C719179
L8: 1uH; L_Murata_DFE201610P; Manufacturer Part WPN201610U1R0MTY01; LCSC Part # C395545
POWER_IN1: FH34SRJ-10S-0.5SH_50_; HRS_FH34SRJ-10S-0.5SH_50_; Manufacturer Part FH34SRJ-10S-0.5SH(50); LCSC Part # C324723
Q4: LBSS138WT1G; SOT-323_SC-70; Manufacturer Part LBSS138WT1G; LCSC Part # C383201
R1, R5: 5.1k; R_0402_1005Metric; Tolerance 1%; Manufacturer Part 0402WGF5101TCE; LCSC Part # C25905
R2, R3: 22R; R_0402_1005Metric; Tolerance 5%; MPN RC0402JR-0722RL; LCSC Part # C25092
R7, R14: 0R; R_0402_1005Metric; Tolerance 1%; Manufacturer Part 0402WGF0000TCE; LCSC Part # C17168
R8, R9, R15: 100k; R_0402_1005Metric; Tolerance 1%; Manufacturer Part 0402WGF1003TCE; LCSC Part # C25741
R10, R16: 100k; R_0402_1005Metric; Tolerance 1%; Manufacturer Part 0402WGJ0104TCE; LCSC Part # C25530; not fitted
R11, R17: 49.9R; R_0603_1608Metric; Tolerance 1%; Manufacturer Part 0603WAF499JT5E; LCSC Part # C23185
R12: 210k; R_0603_1608Metric; Tolerance 1%; Manufacturer Part 0603WAF2103T5E; LCSC Part # C22952
R13: 40k; R_0603_1608Metric; Tolerance 1%; Manufacturer Part RT0603BRD0740KL; LCSC Part # C861392
R18: 68.1k; R_0603_1608Metric; Tolerance 1%; Manufacturer Part 0603WAF6812T5E; LCSC Part # C25976
R19: 22.1k; R_0603_1608Metric; Tolerance 1%; Manufacturer Part 0603WAF2212T5E; LCSC Part # C25961
R74: 51k; R_0402_1005Metric; Manufacturer Part 0402WGF5102TCE; LCSC Part # C25794
R75: 100k; R_0402_1005Metric; Manufacturer Part 0402WGF1003TCE; LCSC Part # C25741
R76: 1M; R_0402_1005Metric; Manufacturer Part 0402WGF1004TCE; LCSC Part # C26083
R77: 330k; R_0402_1005Metric; Manufacturer Part 0402WGF3303TCE; LCSC Part # C25778
TP1, TP6: 3V3; TestPoint_Pad_D1.0mm; not fitted
TP3: 5V_SW; TestPoint_Pad_D1.0mm; not fitted
TP4: 1V8; TestPoint_Pad_D1.0mm; not fitted
TP5: VDD; TestPoint_Pad_D1.0mm; not fitted
TP17: 5V; TestPoint_Pad_D1.0mm; not fitted
TP18: 14V; TestPoint_Pad_D1.0mm; not fitted
TP19: RST; TestPoint_Pad_D1.0mm; not fitted
TP20: BOOT; TestPoint_Pad_D1.0mm; not fitted
TP21, TP22: GND; TestPoint_Pad_D1.0mm; not fitted
TP23: VMIC; TestPoint_Pad_D1.0mm; not fitted
U3, U7: TPS62130; VQFN-16-1EP_3x3mm_P0.5mm_EP1.68x1.68mm_ThermalVias; Manufacturer Part TPS62130ARGTR; LCSC Part # C337502
U4: AP22802AW5-7; SOT-23-5; Manufacturer Part AP22802AW5-7; LCSC Part # C211404
U5: TLV70018DCKR; SOT65P210X110-5N; PARTREV 3.1 - July 16, 2013; LCSC Part # C133796
U6: TPS62065DSGR; Texas_DSG0008A_WSON-8-1EP_2x2mm_P0.5mm_EP0.9x1.6mm; Manufacturer Part TPS62065DSGR; LCSC Part # C398352
U18: LM66100DCK; SOT-363_SC-70-6; Manufacturer Part LM66100DCKR; LCSC Part # C2869734

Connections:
+1V8: C17.1, C19.1, TP4.1, U5.5 (VOUT); also elsewhere on the board
+3V3: C12.1, C22.1, C23.1, L2.2, R17.1, TP1.1 (T), TP6.1, U5.1 (VIN), U5.3 (EN), U7.14 (VOS); also elsewhere on the board
+5V: C8.1, C13.1, C14.1, C15.1, C106.1, R15.1, R16.1, TP17.1, U4.1 (OUT), U6.5 (EN), U6.6 (MODE), U6.7 (AVIN), U6.8 (PVIN), U7.10 (VIN), U7.11 (VIN), U7.12 (VIN), U18.3 (~CE), U18.6 (VOUT); also elsewhere on the board
+14V: C3.1, C4.1, C105.1, POWER_IN1.7, POWER_IN1.8, POWER_IN1.9, POWER_IN1.10, R8.1, R10.1, R76.1, TP18.1, U3.10 (VIN), U3.11 (VIN), U3.12 (VIN); also elsewhere on the board
/Power/+5V_SW: C10.1, C11.1, L1.2, R11.1, TP3.1, U3.14 (VOS), U18.1 (VIN)
/Power/USB_D_N: D4.2 (A2), J1.A7 (DN1), J1.B7 (DN2), R3.1
/Power/USB_D_P: D3.2 (A2), J1.A6 (DP1), J1.B6 (DP2), R2.1
/Power/USB_EN: Q4.3 (D), R9.1, U4.4 (EN)
/Power/USB_EN_GATE: Q4.1 (G), R76.2, R77.1
ESP_BOOT: TP20.1; also elsewhere on the board
ESP_RST: TP19.1; also elsewhere on the board
ESP_USB_N: R3.2; also elsewhere on the board
ESP_USB_P: R2.2; also elsewhere on the board
GND: C3.2, C4.2, C5.1, C6.2, C7.2, C8.2, C10.2, C11.2, C12.2, C13.2, C14.2, C15.2, C16.1, C17.2, C18.2, C19.2, C20.2, C22.2, C23.2, C105.2, C106.2, D1.1 (A1), D3.1 (A1), D4.1 (A1), J1.A1 (GND_A), J1.A12 (GND_A), J1.B1 (GND_B), J1.B12 (GND_B), J1.SH1 (SHIELD), J1.SH2 (SHIELD), J1.SH3 (SHIELD), J1.SH4 (SHIELD), POWER_IN1.1, POWER_IN1.3, POWER_IN1.4, POWER_IN1.5, POWER_IN1.6, Q4.2 (S), R1.2, R5.2, R7.1, R13.2, R14.1, R19.2, R75.2, R77.2, TP21.1, TP22.1, U3.6 (GND), U3.15 (GND), U3.16 (GND), U3.17 (GND), U4.2 (GND), U5.2 (GND), U6.1 (PGND), U6.3 (AGND), U6.9 (PAD), U7.6 (GND), U7.15 (GND), U7.16 (GND), U7.17 (GND), U18.2 (GND); also elsewhere on the board
MUTE: POWER_IN1.2; also elsewhere on the board
unnamed: C9.1, R11.2, R12.1
unnamed: C21.1, R17.2, R18.1
unnamed: D1.2 (A2), FB1.2, J1.A4 (VBUS_A), J1.A9 (VBUS_A), J1.B4 (VBUS_B), J1.B9 (VBUS_B)
unnamed: J1.A5 (CC1), R1.1
unnamed: J1.B5 (CC2), R5.1
unnamed: L1.1, U3.1 (SW), U3.2 (SW), U3.3 (SW)
unnamed: L2.1, U7.1 (SW), U7.2 (SW), U7.3 (SW)
unnamed: R7.2, U3.8 (DEF)
unnamed: R8.2, U3.13 (EN)
unnamed: C9.2, R12.2, R13.1, U3.5 (FB)
unnamed: R10.2, U3.4 (PG)
unnamed: C5.2, U3.9 (SS/TR)
unnamed: C100.2, R74.2, R75.1, U6.4 (FB)
unnamed: L8.1, U6.2 (SW)
unnamed: R14.2, U7.8 (DEF)
unnamed: R15.2, U7.13 (EN)
unnamed: C21.2, R18.2, R19.1, U7.5 (FB)
unnamed: R16.2, U7.4 (PG)
unnamed: C16.2, U7.9 (SS/TR)
VBUS: C6.1, C7.1, FB1.1, R9.2, U4.5 (IN); also elsewhere on the board
VDD: C18.1, C20.1, C100.1, L8.2, R74.1, TP5.1; also elsewhere on the board
VDD_MIC: TP23.1; also elsewhere on the board

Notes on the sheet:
USB Port
POWER IN 1
14V to 5V
USB Switch
USB Data Switch
3.3V to 1.8V
5V to 3.3V
5V to 0.9V (TPS62065)

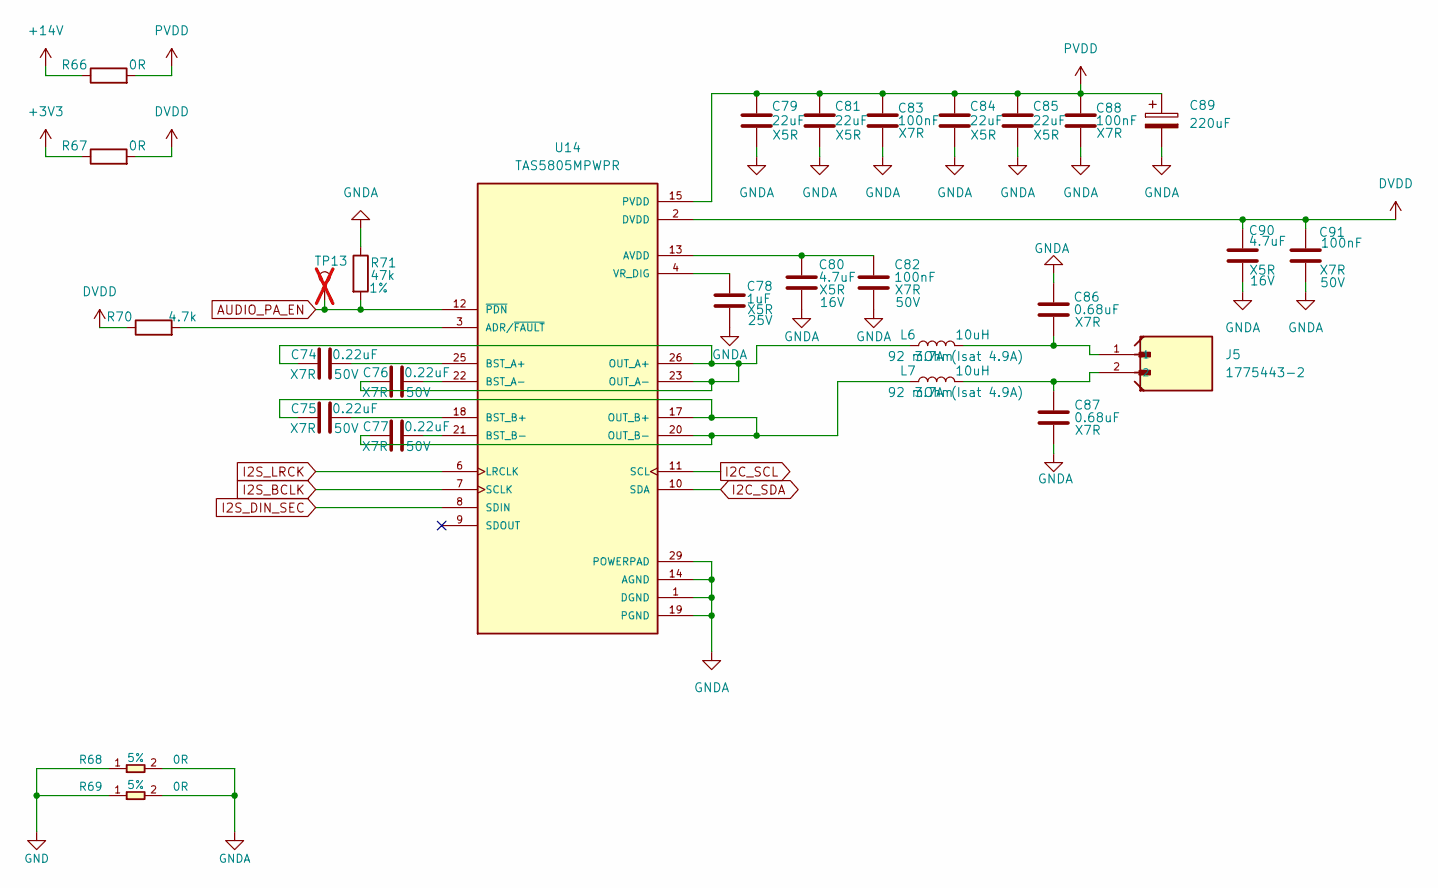
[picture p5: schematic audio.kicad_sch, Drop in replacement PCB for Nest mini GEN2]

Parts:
C74, C75, C76, C77: 0.22uF; C_0603_1608Metric; Voltage 50V; Manufacturer Part CC0603KRX7R9BB224; LCSC Part # C107083
C78: 1uF; C_0402_1005Metric; Voltage 25V; Manufacturer Part CL05A105KA5NQNC; LCSC Part # C52923
C79, C81, C84, C85: 22uF; C_0805_2012Metric; Voltage 25V; Manufacturer Part CL21A226MAQNNNE; LCSC Part # C45783
C80, C90: 4.7uF; C_0603_1608Metric; Voltage 16V; MPN CL10A475KO8NNNC; LCSC Part # C19666
C82, C91: 100nF; C_0603_1608Metric; Voltage 50V; Manufacturer Part CC0603KRX7R9BB104; LCSC Part # C14663
C83, C88: 100nF; C_0402_1005Metric; Voltage 50V; Manufacturer Part CL05B104KB54PNC; LCSC Part # C307331
C86, C87: 0.68uF; C_0805_2012Metric; Voltage 50V; Manufacturer Part CC0805KKX7R9BB684; LCSC Part # C107133
C89: 220uF; C_Elec_6.3x7.7; Voltage 25V; Manufacturer Part MA25V220M6X8; LCSC Part # C46550464
J5: 1775443-2; PARTREV B5; LCSC Part # C5162845
L6, L7: 10uH; MTQH404030S100MBT; Manufacturer Part MTQH404030S100MBT; LCSC Part # C51883185
R66: 0R; R_1206_3216Metric; Manufacturer Part 1206W4F0000T5E; LCSC Part # C17888
R67: 0R; R_0603_1608Metric; Manufacturer Part 0603WAF0000T5E; LCSC Part # C21189
R68, R69: 0R; R_0805_2012Metric; Tolerance 5%; MPN 0805W8F0000T5E; LCSC Part # C17477
R70: 4.7k; R_0402_1005Metric; Tolerance 5%; Manufacturer Part 0402WGF4701TCE; LCSC Part # C25900
R71: 47k; R_0402_1005Metric; Tolerance 1%; Manufacturer Part 0402WGF4702TCE; LCSC Part # C25792
TP13: PA_EN; TestPoint_Pad_D1.0mm; not fitted
U14: TAS5805MPWPR; Manufacturer Part TAS5805MPWPR; LCSC Part # C478472

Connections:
+3V3: R67.1; also elsewhere on the board
+14V: R66.1; also elsewhere on the board
AUDIO_PA_EN: R71.2, TP13.1, U14.12 (~PDN); also elsewhere on the board
DVDD: C90.1, C91.1, R67.2, R70.1, U14.2 (DVDD)
GND: R68.1, R69.1; also elsewhere on the board
GNDA: C78.2, C79.2, C80.2, C81.2, C82.2, C83.2, C84.2, C85.2, C86.2, C87.2, C88.2, C89.2, C90.2, C91.2, R68.2, R69.2, R71.1, U14.1 (DGND), U14.5 (DGND), U14.14 (AGND), U14.19 (PGND), U14.24 (PGND), U14.29 (POWERPAD), U14.30 (POWERPAD), U14.31 (POWERPAD), U14.32 (POWERPAD), U14.33 (POWERPAD), U14.34 (POWERPAD), U14.35 (POWERPAD), U14.36 (POWERPAD), U14.37 (POWERPAD), U14.38 (POWERPAD), U14.39 (POWERPAD), U14.40 (POWERPAD), U14.41 (POWERPAD), U14.42 (POWERPAD), U14.43 (POWERPAD), U14.44 (POWERPAD), U14.45 (POWERPAD), U14.46 (POWERPAD), U14.47 (POWERPAD), U14.48 (POWERPAD), U14.49 (POWERPAD), U14.50 (POWERPAD), U14.51 (POWERPAD), U14.52 (POWERPAD), U14.53 (POWERPAD)
I2C_SCL: U14.11 (SCL); also elsewhere on the board
I2C_SDA: U14.10 (SDA); also elsewhere on the board
I2S_BCLK: U14.7 (SCLK); also elsewhere on the board
I2S_DIN_SEC: U14.8 (SDIN); also elsewhere on the board
I2S_LRCK: U14.6 (LRCLK); also elsewhere on the board
unnamed: C86.1, J5.1, L6.2
unnamed: C87.1, J5.2, L7.2
unnamed: R70.2, U14.3 (ADR/~FAULT)
unnamed: C80.1, C82.1, U14.13 (AVDD)
unnamed: C74.2, U14.25 (BST_A+)
unnamed: C76.2, U14.22 (BST_A-)
unnamed: C75.2, U14.18 (BST_B+)
unnamed: C77.2, U14.21 (BST_B-)
unnamed: C74.1, C76.1, L6.1, U14.23 (OUT_A-), U14.26 (OUT_A+)
unnamed: C75.1, C77.1, L7.1, U14.17 (OUT_B+), U14.20 (OUT_B-)
unnamed: C78.1, U14.4 (VR_DIG)
PVDD: C79.1, C81.1, C83.1, C84.1, C85.1, C88.1, C89.1, R66.2, U14.15 (PVDD), U14.16 (PVDD), U14.27 (PVDD), U14.28 (PVDD)

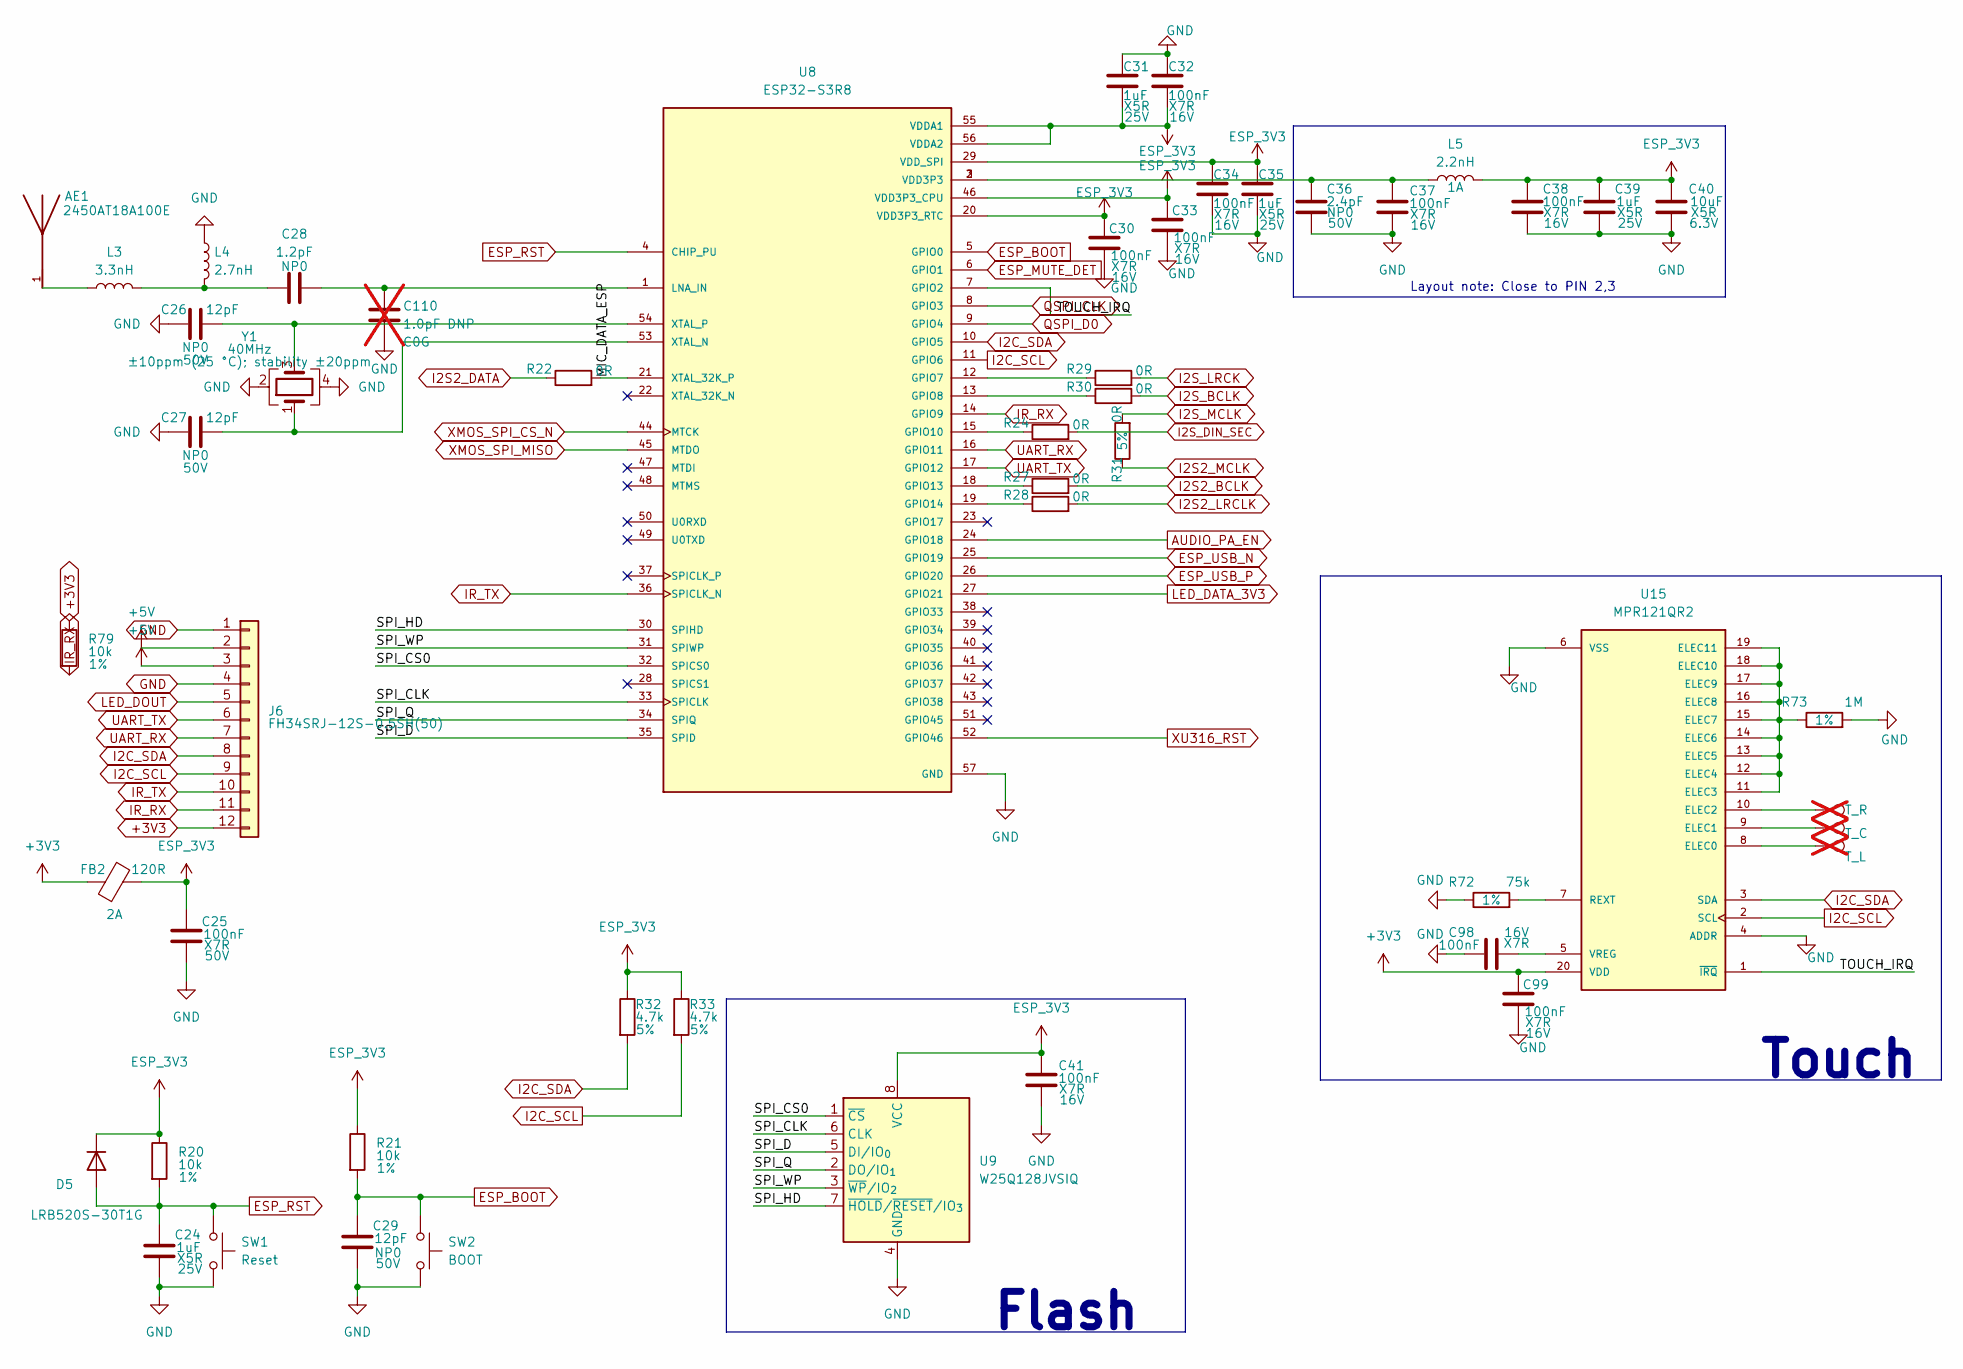
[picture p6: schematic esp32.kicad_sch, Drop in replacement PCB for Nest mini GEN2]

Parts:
AE1: 2450AT18A100E; Johanson_2450AT18x100; PARTREV 1.3; LCSC Part # C89334
C24, C31, C35, C39: 1uF; C_0402_1005Metric; Voltage 25V; Manufacturer Part CL05A105KA5NQNC; LCSC Part # C52923
C25: 100nF; C_0603_1608Metric; Voltage 50V; Manufacturer Part CC0603KRX7R9BB104; LCSC Part # C14663
C26, C27, C29: 12pF; C_0402_1005Metric; Voltage 50V; Manufacturer Part 0402CG120J500NT; LCSC Part # C1547
C28: 1.2pF; C_0402_1005Metric; Voltage 50V; Manufacturer Part CC0402BRNPO9BN1R2; LCSC Part # C327292
C30, C32, C33, C34, C37, C38, C41, C98, C99: 100nF; C_0402_1005Metric; Voltage 16V; Manufacturer Part CL05B104KO5NNNC; LCSC Part # C1525
C36: 2.4pF; C_0402_1005Metric; Voltage 50V; Manufacturer Part 0402CG2R4C500NT; LCSC Part # C48346
C40: 10uF; C_0402_1005Metric; Voltage 6.3V; Manufacturer Part CL05A106MQ5NUNC; LCSC Part # C15525
C110: 1.0pF DNP; C_0201_0603Metric; Voltage 50V; Manufacturer Part GRM0335C1H1R0BA01D; LCSC Part # C85893; not fitted
D5: LRB520S-30T1G; D_SOD-523; Manufacturer Part LRB520S-30T1G; LCSC Part # C83680
FB2: 120R; BLM18PG121SN1D; Part number BLM18PG121SN1D; LCSC Part # C14709
J6: FH34SRJ-12S-0.5SH(50); HRS_FH34SRJ-12S-0.5SH_50_; Manufacturer Part FH34SRJ-12S-0.5SH(50); LCSC C424659
L3: 3.3nH; L_0402_1005Metric; Manufacturer Part SDCL1005C3N3STDF; LCSC Part # C16526
L4: 2.7nH; L_0402_1005Metric; Manufacturer Part MHQ1005P2N7BT000; LCSC Part # C434826
L5: 2.2nH; L_0402_1005Metric; Manufacturer Part LQG15HS2N2B02D; LCSC Part # C162540
R20, R21: 10k; R_0402_1005Metric; Tolerance 1%; Manufacturer Part 0402WGF1002TCE; LCSC Part # C25744
R22, R24, R27, R28, R29, R30, R31: 0R; R_0402_1005Metric; Tolerance 5%; Manufacturer Part 0402WGF0000TCE; LCSC Part # C17168
R32, R33: 4.7k; R_0402_1005Metric; Tolerance 5%; Manufacturer Part 0402WGF4701TCE; LCSC Part # C25900
R72: 75k; R_0402_1005Metric; Tolerance 1%; Manufacturer Part 0402WGF7502TCE; LCSC Part # C25798
R73: 1M; R_0402_1005Metric; Tolerance 1%; Manufacturer Part 0402WGF1004TCE; LCSC Part # C26083
R79: 10k; R_0402_1005Metric; Tolerance 1%; Manufacturer Part 0402WGF1002TCE; LCSC C25744
SW1: Reset; SW-SMD_4P-L4.2-W3.2-P2.15-LS4.5; Manufacturer Part PTS810SJS250SMTRLFS; LCSC Part # C221897
SW2: BOOT; SW-SMD_4P-L4.2-W3.2-P2.15-LS4.5; Manufacturer Part PTS810SJS250SMTRLFS; LCSC Part # C221897
TP14: T_R; TestPoint_Pad_2.5x2.5mm; not fitted
TP15: T_C; TestPoint_Pad_2.5x2.5mm; not fitted
TP16: T_L; TestPoint_Pad_2.5x2.5mm; not fitted
U8: ESP32-S3R8; QFN40P700X700X90-57N; Manufacturer Part ESP32-S3R8; LCSC Part # C2913194
U9: W25Q128JVSIQ; SOIC-8_5.3x5.3mm_P1.27mm; Manufacturer Part W25Q128JVSIQ; LCSC Part # C97521
U15: MPR121QR2; MPN MPR121QR2; LCSC Part # C91322
Y1: 40MHz; Crystal_SMD_2016-4Pin_2.0x1.6mm; Tolerance ±10ppm (25 °C); stability ±20ppm; Manufacturer Part Y201640MDBCX; LCSC Part # C49158179

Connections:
+3V3: C99.1, FB2.1, J6.12, R79.1, U15.20 (VDD); also elsewhere on the board
+5V: J6.2, J6.3; also elsewhere on the board
/ESP32-S3R8/MIC_DATA_ESP: R22.2, U8.21 (XTAL_32K_P)
/ESP32-S3R8/SPI_CLK: U8.33 (SPICLK), U9.6 (CLK)
/ESP32-S3R8/SPI_CS0: U8.32 (SPICS0), U9.1 (~CS)
/ESP32-S3R8/SPI_D: U8.35 (SPID), U9.5 (DI/IO_{0})
/ESP32-S3R8/SPI_HD: U8.30 (SPIHD), U9.7 (~HOLD/~RESET/IO_{3})
/ESP32-S3R8/SPI_Q: U8.34 (SPIQ), U9.2 (DO/IO_{1})
/ESP32-S3R8/SPI_WP: U8.31 (SPIWP), U9.3 (~WP/IO_{2})
/ESP32-S3R8/TOUCH_IRQ: U8.7 (GPIO2), U15.1 (~IRQ)
AUDIO_PA_EN: U8.24 (GPIO18); also elsewhere on the board
ESP_3V3: C25.1, C30.1, C31.2, C32.2, C33.1, C34.1, C35.1, C38.1, C39.1, C40.1, C41.1, D5.1 (K), FB2.2, L5.2, R20.1, R21.1, R32.1, R33.1, U8.20 (VDD3P3_RTC), U8.29 (VDD_SPI), U8.46 (VDD3P3_CPU), U8.55 (VDDA1), U8.56 (VDDA2), U9.8 (VCC); also elsewhere on the board
ESP_BOOT: C29.1, R21.2, SW2.1, U8.5 (GPIO0); also elsewhere on the board
ESP_MUTE_DET: U8.6 (GPIO1); also elsewhere on the board
ESP_RST: C24.1, D5.2 (A), R20.2, SW1.1, U8.4 (CHIP_PU); also elsewhere on the board
ESP_USB_N: U8.25 (GPIO19); also elsewhere on the board
ESP_USB_P: U8.26 (GPIO20); also elsewhere on the board
GND: C24.2, C25.2, C26.1, C27.1, C29.2, C30.2, C31.1, C32.1, C33.2, C34.2, C35.2, C36.2, C37.2, C38.2, C39.2, C40.2, C41.2, C98.1, C99.2, C110.2, J6.1, J6.4, L4.1, R72.1, R73.2, SW1.2, SW2.2, U8.57 (GND), U9.4 (GND), U15.4 (ADDR), U15.6 (VSS), Y1.2, Y1.4; also elsewhere on the board
I2C_SCL: J6.9, R33.2, U8.11 (GPIO6), U15.2 (SCL); also elsewhere on the board
I2C_SDA: J6.8, R32.2, U8.10 (GPIO5), U15.3 (SDA); also elsewhere on the board
I2S2_BCLK: R27.2; also elsewhere on the board
I2S2_DATA: R22.1; also elsewhere on the board
I2S2_LRCLK: R28.2; also elsewhere on the board
I2S2_MCLK: R31.1; also elsewhere on the board
I2S_BCLK: R30.2; also elsewhere on the board
I2S_DIN_SEC: R24.2; also elsewhere on the board
I2S_LRCK: R29.2; also elsewhere on the board
I2S_MCLK: R31.2; also elsewhere on the board
IR_RX: J6.11, R79.2, U8.14 (GPIO9)
IR_TX: J6.10, U8.36 (SPICLK_N)
LED_DATA_3V3: U8.27 (GPIO21); also elsewhere on the board
LED_DOUT: J6.5; also elsewhere on the board
unnamed: AE1.1, L3.1
unnamed: C28.1, L3.2, L4.2
unnamed: C36.1, C37.1, L5.1, U8.2 (VDD3P3), U8.3 (VDD3P3)
unnamed: R29.1, U8.12 (GPIO7)
unnamed: R30.1, U8.13 (GPIO8)
unnamed: R24.1, U8.15 (GPIO10)
unnamed: R27.1, U8.18 (GPIO13)
unnamed: R28.1, U8.19 (GPIO14)
unnamed: C28.2, C110.1, U8.1 (LNA_IN)
unnamed: C27.2, U8.53 (XTAL_N), Y1.1
unnamed: C26.2, U8.54 (XTAL_P), Y1.3
unnamed: TP16.1, U15.8 (ELEC0)
unnamed: TP15.1, U15.9 (ELEC1)
unnamed: TP14.1, U15.10 (ELEC2)
unnamed: R73.1, U15.11 (ELEC3), U15.12 (ELEC4), U15.13 (ELEC5), U15.14 (ELEC6), U15.15 (ELEC7), U15.16 (ELEC8), U15.17 (ELEC9), U15.18 (ELEC10), U15.19 (ELEC11)
unnamed: R72.2, U15.7 (REXT)
unnamed: C98.2, U15.5 (VREG)
QSPI_CLK: U8.8 (GPIO3); also elsewhere on the board
QSPI_D0: U8.9 (GPIO4); also elsewhere on the board
UART_RX: J6.7, U8.16 (GPIO11)
UART_TX: J6.6, U8.17 (GPIO12)
XMOS_SPI_CS_N: U8.44 (MTCK); also elsewhere on the board
XMOS_SPI_MISO: U8.45 (MTDO); also elsewhere on the board
XU316_RST: U8.52 (GPIO46); also elsewhere on the board

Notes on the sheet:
Touch
Layout note: Close to PIN 2,3
Flash

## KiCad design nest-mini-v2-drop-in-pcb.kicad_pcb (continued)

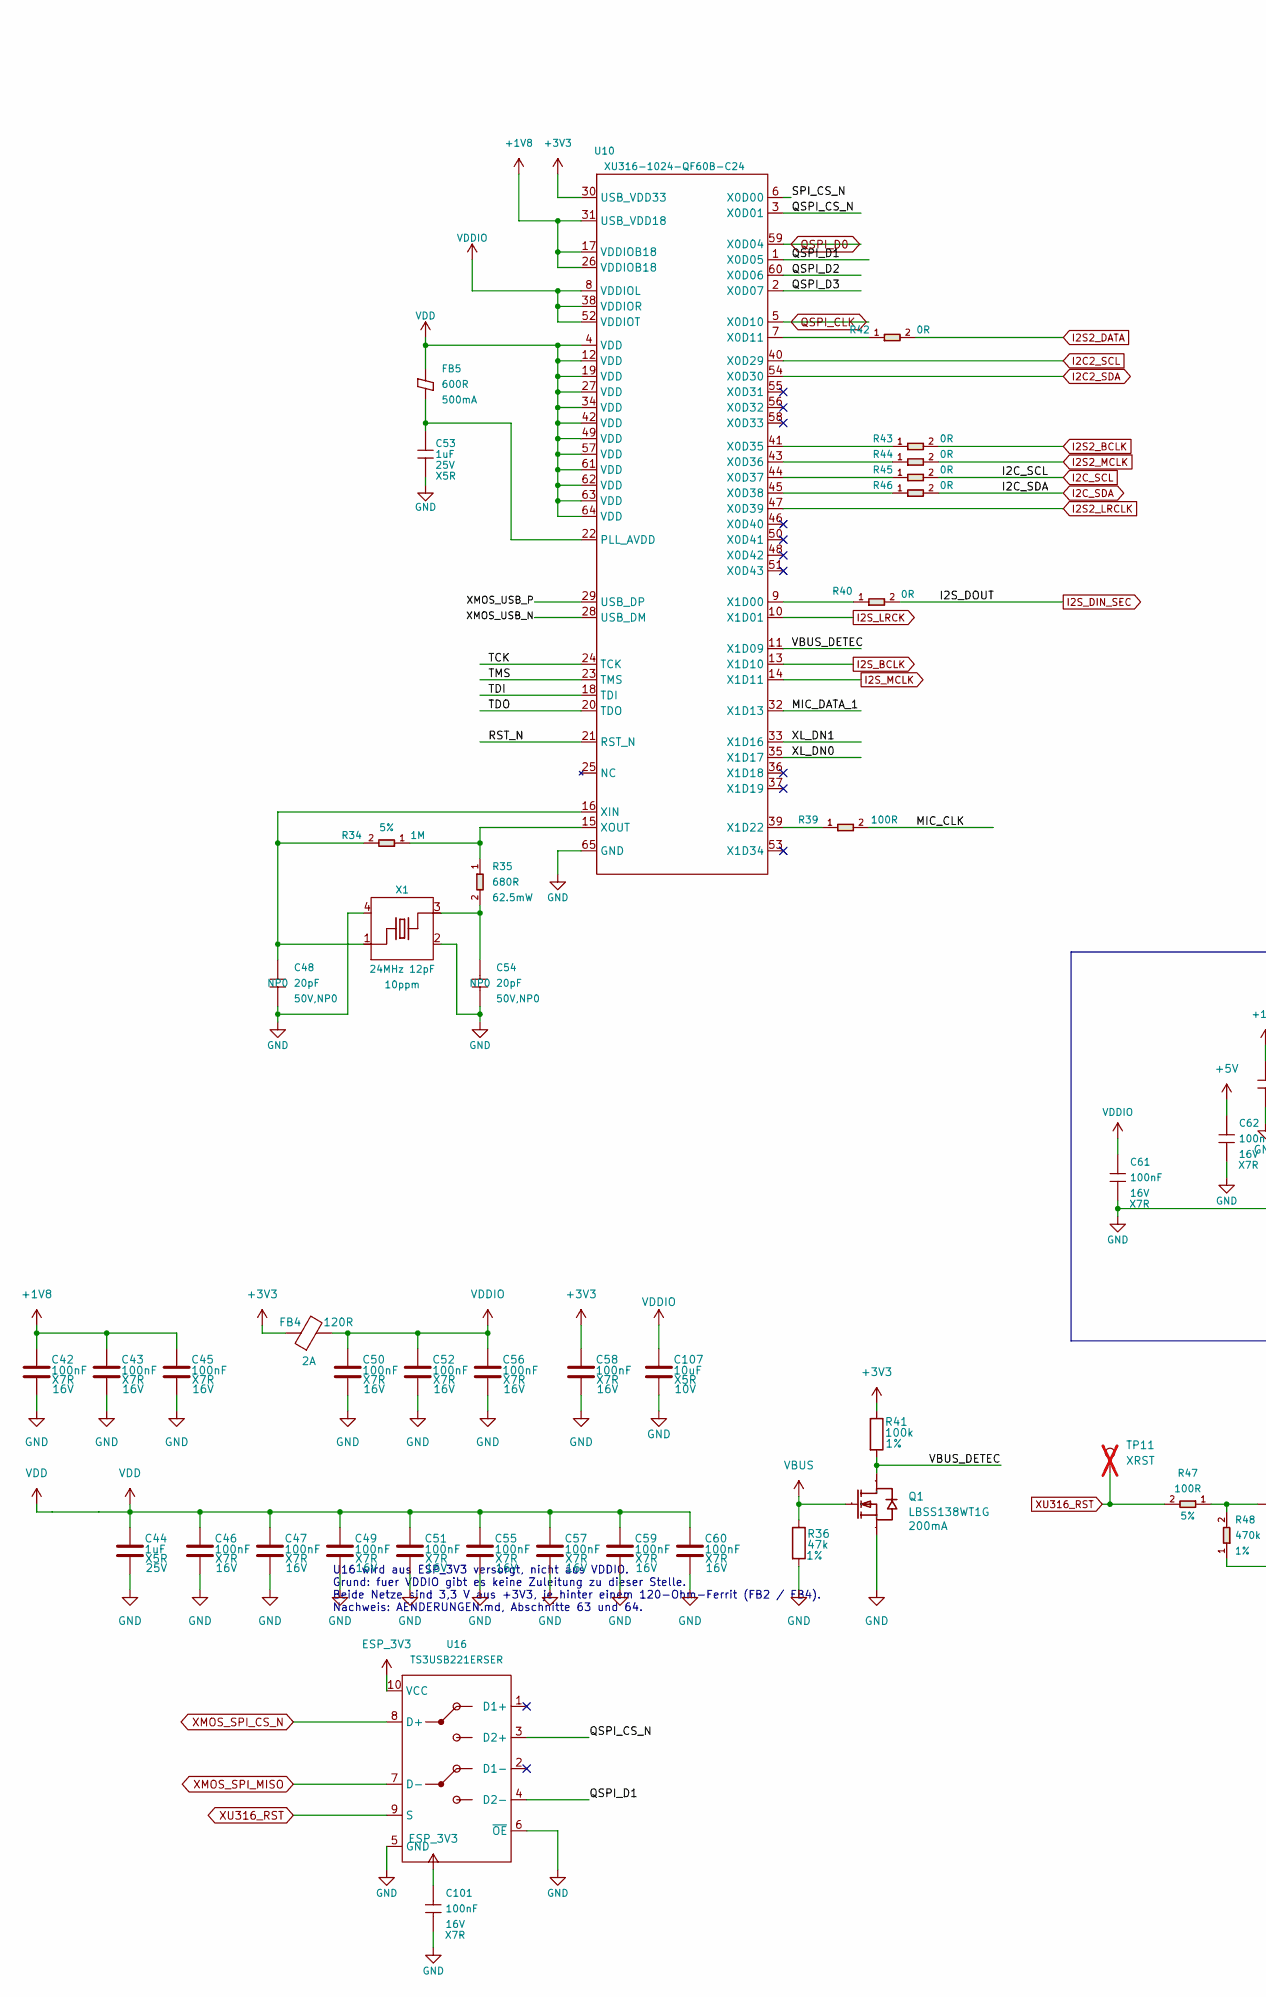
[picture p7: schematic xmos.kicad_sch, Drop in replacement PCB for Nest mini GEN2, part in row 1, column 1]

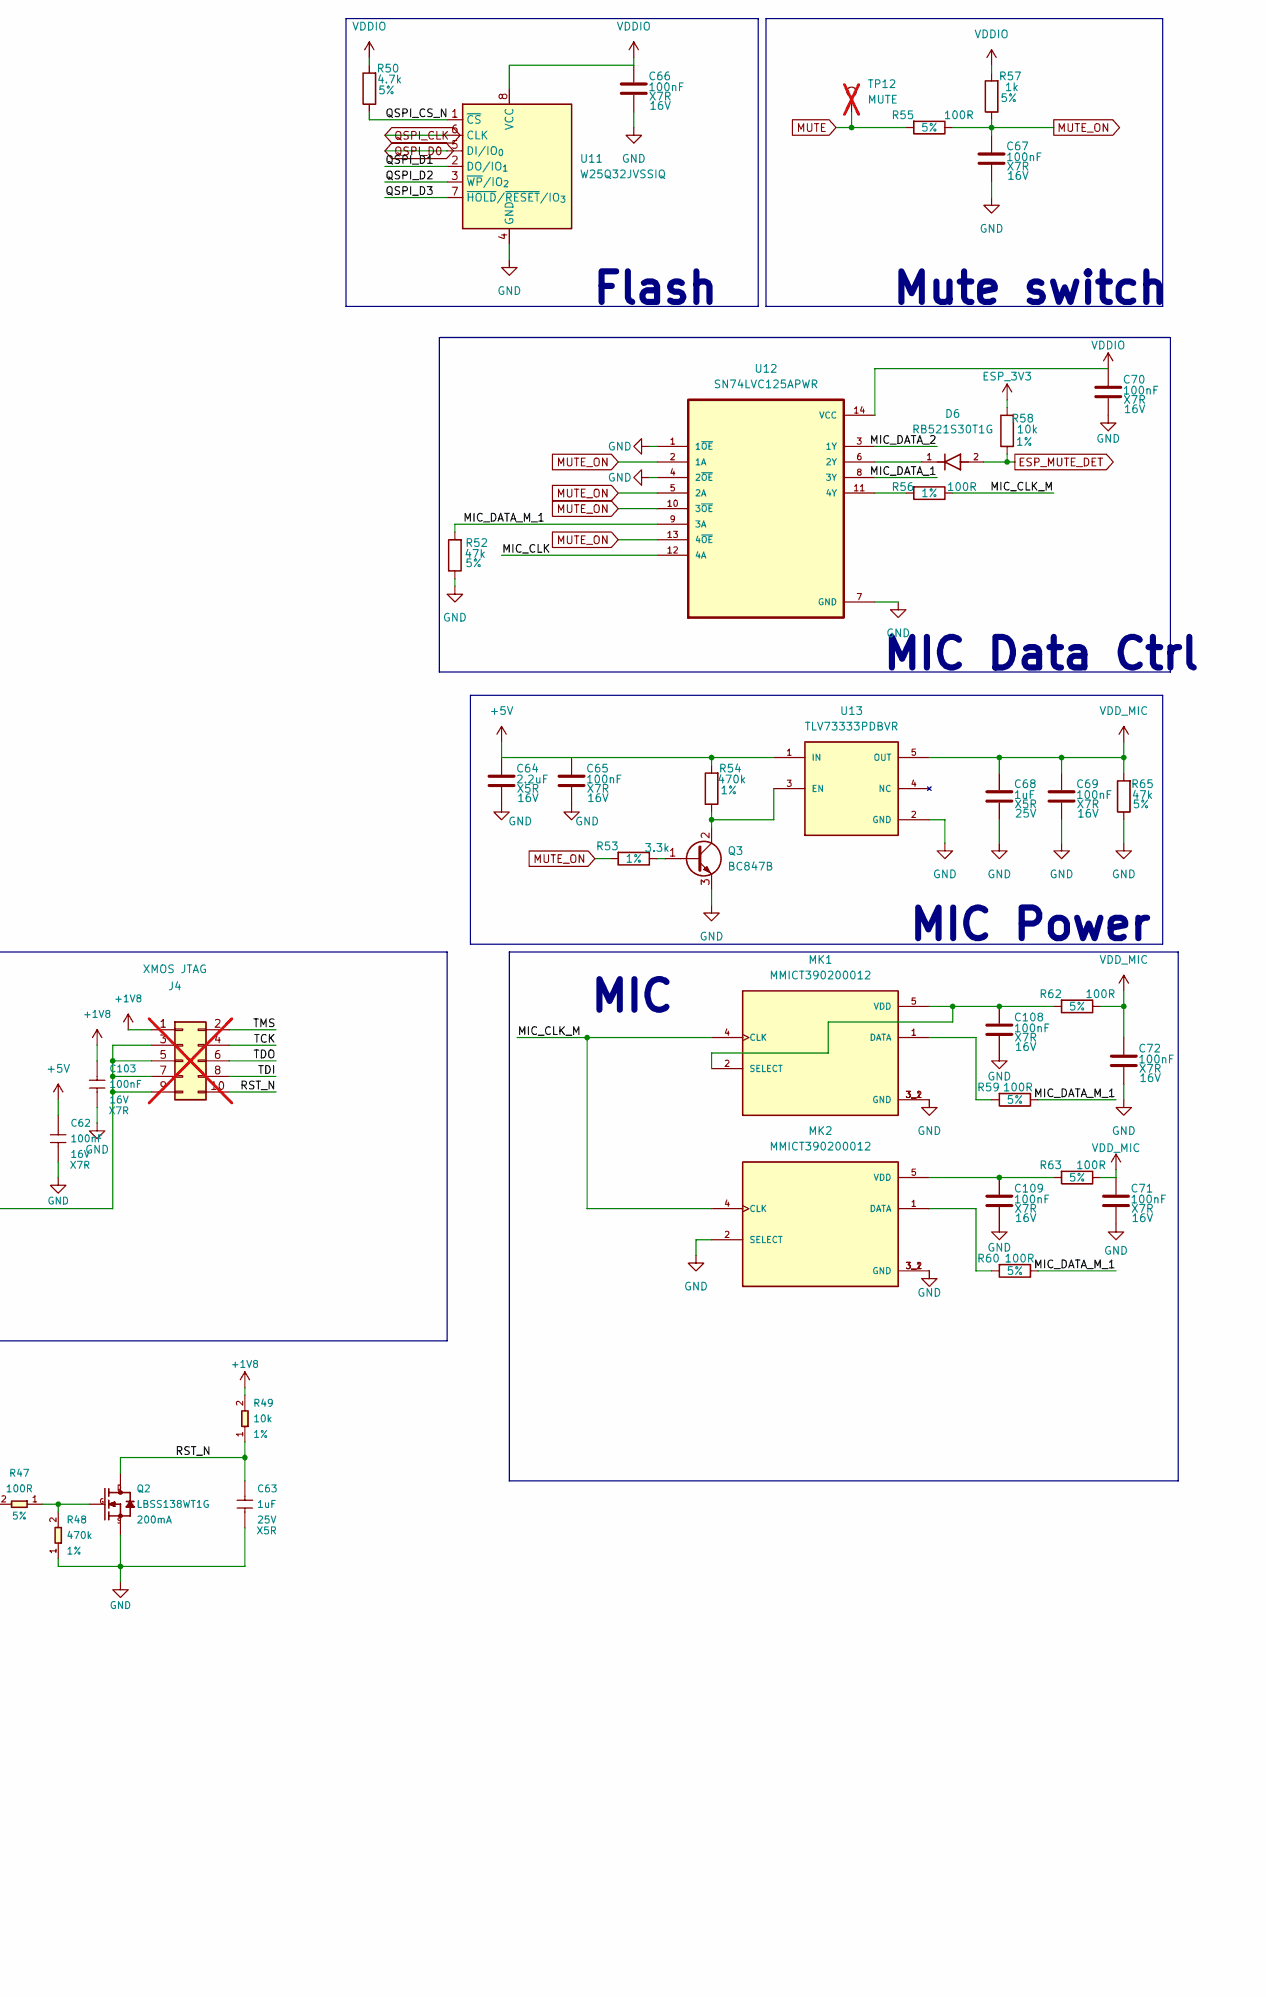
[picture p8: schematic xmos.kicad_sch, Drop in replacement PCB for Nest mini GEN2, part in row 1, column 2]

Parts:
C42, C43, C45, C46, C47, C49, C50, C51, C52, C55, C56, C57, C58, C59, C60, C65, C66, C67, C69, C70, C71, C72, C108, C109: 100nF; C_0402_1005Metric; Voltage 16V; Manufacturer Part CL05B104KO5NNNC; LCSC Part # C1525
C44, C68: 1uF; C_0402_1005Metric; Voltage 25V; Manufacturer Part CL05A105KA5NQNC; LCSC Part # C52923
C48, C54: 20pF; C_0402_1005Metric; Voltage Rating 50V,NP0; Voltage 50V; MPN 0402CG200J500NT; LCSC Part # C1554
C53: 1uF; C_0402_1005Metric; Voltage Rating 25V; Voltage 25V; MPN CL05A105KA5NQNC; LCSC Part # C52923
C61, C62: 100nF; C_0402_1005Metric; Voltage Rating 16V; Voltage 16V; MPN CL05B104KO5NNNC; LCSC Part # C1525
C63: 1uF; C_0402_1005Metric; Voltage Rating 25V; MPN CL05A105KA5NQNC; LCSC Part # C52923
C64: 2.2uF; C_0603_1608Metric; Voltage 16V; Manufacturer Part CL10A225KO8NNNC; LCSC Part # C23630
C101, C103: 100nF; C_0402_1005Metric; Voltage Rating 16V; MPN CL05B104KO5NNNC; LCSC Part # C1525
C107: 10uF; C_0603_1608Metric; Voltage 10V; Manufacturer Part CL10A106KP8NNNC; LCSC Part # C19702
D6: RB521S30T1G; DIOM168X70N; PARTREV 7/11/1905; LCSC Part # C27636108
FB4: 120R; BLM18PG121SN1D; Part number BLM18AG121SN1D; LCSC Part # C14709
FB5: 600R; BLM18PG121SN1D; Rating 500mA; MPN BLM18KG601SN1D; LCSC Part # C85833
J4: XMOS JTAG; xSYS2_2x05_P1.27mm_Pads; not fitted
MK1, MK2: MMICT390200012; MIC_T3902; PARTREV 1.0; LCSC Part # C3171752
Q1: LBSS138WT1G; SC-70-3_L2.1-W1.3-P0.65-LS2.1-BR; Manufacturer Part LBSS138WT1G; LCSC Part # C383201
Q2: LBSS138WT1G; SOT-323_SC-70; Rating 200mA; MPN LBSS138WT1G; LCSC Part # C383201
Q3: BC847B; SOT-23; Manufacturer Part BC847B; LCSC Part # C20069135
R34: 1M; R_0402_1005Metric; Power Rating 5%; MPN 0402WGF1004TCE; LCSC Part # C26083
R35: 680R; R_0402_1005Metric; Power Rating 62.5mW; MPN CR0402FF6800G; LCSC Part # C100510
R36: 47k; R_0402_1005Metric; Tolerance 1%; Manufacturer Part 0402WGF4702TCE; LCSC Part # C25792
R39: 100R; R_0402_1005Metric; Power Rating 5%; MPN 0402WGF1000TCE; LCSC Part # C25076
R40, R43, R44, R45, R46: 0R; R_0402_1005Metric; Power Rating 5%; MPN 0402WGF0000TCE; LCSC Part # C17168
R41: 100k; R_0402_1005Metric; Tolerance 1%; Manufacturer Part 0402WGF1003TCE; LCSC Part # C25741
R42: 0R; R_0402_1005Metric; Tolerance 5%; MPN 0402WGF0000TCE; LCSC Part # C17168
R47: 100R; R_0402_1005Metric; Power Rating 5%; MPN RC0402JR-07100RL; LCSC Part # C25076
R48: 470k; R_0402_1005Metric; Power Rating 1%; MPN RC0402FR-07470KL; LCSC Part # C25790
R49: 10k; R_0402_1005Metric; Power Rating 1%; MPN RC0402FR-0710KL; LCSC Part # C25744
R50: 4.7k; R_0402_1005Metric; Tolerance 5%; Manufacturer Part 0402WGF4701TCE; LCSC Part # C25900
R52, R65: 47k; R_0402_1005Metric; Tolerance 5%; Manufacturer Part 0402WGF4702TCE; LCSC Part # C25792
R53: 3.3k; R_0402_1005Metric; Tolerance 1%; Manufacturer Part 0402WGF3301TCE; LCSC Part # C25890
R54: 470k; R_0402_1005Metric; Tolerance 1%; Manufacturer Part 0402WGF4703TCE; LCSC Part # C25790
R55, R59, R60, R62, R63: 100R; R_0402_1005Metric; Tolerance 5%; Manufacturer Part 0402WGF1000TCE; LCSC Part # C25076
R56: 100R; R_0402_1005Metric; Tolerance 1%; Manufacturer Part 0402WGF1000TCE; LCSC Part # C25076
R57: 1k; R_0402_1005Metric; Tolerance 5%; Manufacturer Part 0402WGF1001TCE; LCSC Part # C11702
R58: 10k; R_0402_1005Metric; Tolerance 1%; Manufacturer Part 0402WGF1002TCE; LCSC Part # C25744
TP11: XRST; TestPoint_Pad_D1.0mm; not fitted
TP12: MUTE; TestPoint_Pad_D1.0mm; not fitted
U10: XU316-1024-QF60B-C24; MPN XU316-1024-QF60B-C24; LCSC Part # C6617472
U11: W25Q32JVSSIQ; SOIC-8_5.3x5.3mm_P1.27mm; Manufacturer Part W25Q32JVSSIQ; LCSC Part # C179173
U12: SN74LVC125APWR; SOP65P640X120-14N; Manufacturer Part SN74LVC125APWR; LCSC Part # C7813
U13: TLV73333PDBVR; PARTREV C; LCSC Part # C134139
U16: TS3USB221ERSER; MPN TS3USB221ERSER; LCSC Part # C129313
X1: 24MHz 12pF; X4-SMD-2.0X1.6MM; Rating 10ppm; MPN 7F24000E12UCG; LCSC Part # C252273

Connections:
+1V8: C42.1, C43.1, C45.1, C103.1, J4.1, R49.2, U10.17 (VDDIOB18), U10.26 (VDDIOB18), U10.31 (USB_VDD18); also elsewhere on the board
+3V3: C58.1, FB4.1, R41.1, U10.30 (USB_VDD33); also elsewhere on the board
+5V: C62.1, C64.1, C65.1, R54.2, U13.1 (IN); also elsewhere on the board
/XMOS/MIC_CLK: R39.2, U12.12 (4A)
/XMOS/MIC_CLK_M: MK1.4 (CLK), MK2.4 (CLK), R56.1
/XMOS/MIC_DATA_1: U10.32 (X1D13), U12.8 (3Y)
/XMOS/MIC_DATA_2: U12.3 (1Y)
/XMOS/MIC_DATA_M_1: R52.2, R59.1, R60.1, U12.9 (3A)
/XMOS/QSPI_CS_N: R50.1, U10.3 (X0D01), U11.1 (~CS), U16.3 (D2+)
/XMOS/QSPI_D1: U10.1 (X0D05), U11.2 (DO/IO_{1}), U16.4 (D2-)
/XMOS/QSPI_D2: U10.60 (X0D06), U11.3 (~WP/IO_{2})
/XMOS/QSPI_D3: U10.2 (X0D07), U11.7 (~HOLD/~RESET/IO_{3})
/XMOS/RST_N: C63.1, J4.10, Q2.3 (D), R49.1, U10.21 (RST_N)
/XMOS/SPI_CS_N: U10.6 (X0D00)
/XMOS/TCK: J4.4, U10.24 (TCK)
/XMOS/TDI: J4.8, U10.18 (TDI)
/XMOS/TDO: J4.6, U10.20 (TDO)
/XMOS/TMS: J4.2, U10.23 (TMS)
/XMOS/VBUS_DETEC: Q1.3 (D), R41.2, U10.11 (X1D09)
/XMOS/XL_DN0: U10.35 (X1D17)
/XMOS/XL_DN1: U10.33 (X1D16)
/XMOS/XMOS_USB_N: U10.28 (USB_DM)
/XMOS/XMOS_USB_P: U10.29 (USB_DP)
ESP_3V3: C101.1, R58.2, U16.10 (VCC); also elsewhere on the board
ESP_MUTE_DET: D6.2, R58.1; also elsewhere on the board
GND: C42.2, C43.2, C44.2, C45.2, C46.2, C47.2, C48.2, C49.2, C50.2, C51.2, C52.2, C53.2, C54.2, C55.2, C56.2, C57.2, C58.2, C59.2, C60.2, C61.2, C62.2, C63.2, C64.2, C65.2, C66.2, C67.2, C68.2, C69.2, C70.2, C71.2, C72.2, C101.2, C103.2, C107.2, C108.2, C109.2, J4.3, J4.5, J4.7, J4.9, MK1.3_1 (GND), MK1.3_2 (GND), MK2.2 (SELECT), MK2.3_1 (GND), MK2.3_2 (GND), Q1.2 (S), Q2.2 (S), Q3.3 (E), R36.2, R48.1, R52.1, R65.1, U10.65 (GND), U11.4 (GND), U12.1 (1~OE), U12.4 (2~OE), U12.7 (GND), U13.2 (GND), U16.5 (GND), U16.6 (~OE), X1.2, X1.4; also elsewhere on the board
I2C2_SCL: U10.40 (X0D29)
I2C2_SDA: U10.54 (X0D30)
I2C_SCL: R45.2; also elsewhere on the board
I2C_SDA: R46.2; also elsewhere on the board
I2S2_BCLK: R43.2; also elsewhere on the board
I2S2_DATA: R42.2; also elsewhere on the board
I2S2_LRCLK: U10.47 (X0D39); also elsewhere on the board
I2S2_MCLK: R44.2; also elsewhere on the board
I2S_BCLK: U10.13 (X1D10); also elsewhere on the board
I2S_DIN_SEC: R40.2; also elsewhere on the board
I2S_LRCK: U10.10 (X1D01); also elsewhere on the board
I2S_MCLK: U10.14 (X1D11); also elsewhere on the board
MUTE: R55.2, TP12.1; also elsewhere on the board
MUTE_ON: C67.1, R53.2, R55.1, R57.1, U12.2 (1A), U12.5 (2A), U12.10 (3~OE), U12.13 (4~OE)
unnamed: C54.1, R35.2, X1.3
unnamed: MK1.1 (DATA), R59.2
unnamed: C108.1, MK1.2 (SELECT), MK1.5 (VDD), R62.2
unnamed: MK2.1 (DATA), R60.2
unnamed: C109.1, MK2.5 (VDD), R63.2
unnamed: Q2.1 (G), R47.1, R48.2
unnamed: Q3.1 (B), R53.1
unnamed: Q3.2 (C), R54.1, U13.3 (EN)
unnamed: C53.1, FB5.1, U10.22 (PLL_AVDD)
unnamed: R42.1, U10.7 (X0D11)
unnamed: R43.1, U10.41 (X0D35)
unnamed: R44.1, U10.43 (X0D36)
unnamed: R45.1, U10.44 (X0D37)
unnamed: R46.1, U10.45 (X0D38)
unnamed: R40.1, U10.9 (X1D00)
unnamed: R39.1, U10.39 (X1D22)
unnamed: C48.1, R34.2, U10.16 (XIN), X1.1
unnamed: R34.1, R35.1, U10.15 (XOUT)
unnamed: D6.1, U12.6 (2Y)
unnamed: R56.2, U12.11 (4Y)
QSPI_CLK: U10.5 (X0D10), U11.6 (CLK); also elsewhere on the board
QSPI_D0: U10.59 (X0D04), U11.5 (DI/IO_{0}); also elsewhere on the board
VBUS: Q1.1 (G), R36.1; also elsewhere on the board
VDD: C44.1, C46.1, C47.1, C49.1, C51.1, C55.1, C57.1, C59.1, C60.1, FB5.2, U10.4 (VDD), U10.12 (VDD), U10.19 (VDD), U10.27 (VDD), U10.34 (VDD), U10.42 (VDD), U10.49 (VDD), U10.57 (VDD), U10.61 (VDD), U10.62 (VDD), U10.63 (VDD), U10.64 (VDD); also elsewhere on the board
VDDIO: C50.1, C52.1, C56.1, C61.1, C66.1, C70.1, C107.1, FB4.2, R50.2, R57.2, U10.8 (VDDIOL), U10.38 (VDDIOR), U10.52 (VDDIOT), U11.8 (VCC), U12.14 (VCC)
VDD_MIC: C68.1, C69.1, C71.1, C72.1, R62.1, R63.1, R65.2, U13.5 (OUT); also elsewhere on the board
XMOS_SPI_CS_N: U16.8 (D+); also elsewhere on the board
XMOS_SPI_MISO: U16.7 (D-); also elsewhere on the board
XU316_RST: R47.2, TP11.1, U16.9 (S); also elsewhere on the board

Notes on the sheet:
Flash
MIC
Mute switch
MIC Power
MIC Data Ctrl
U16 wird aus ESP_3V3 versorgt, nicht aus VDDIO. Grund: fuer VDDIO gibt es keine Zuleitung zu dieser Stelle. Beide Netze sind 3,3 V aus +3V3, je hinter einem 120-Ohm-Ferrit (FB2 / FB4). Nachweis: AENDERUNGEN.md, Abschnitte 63 und 64.

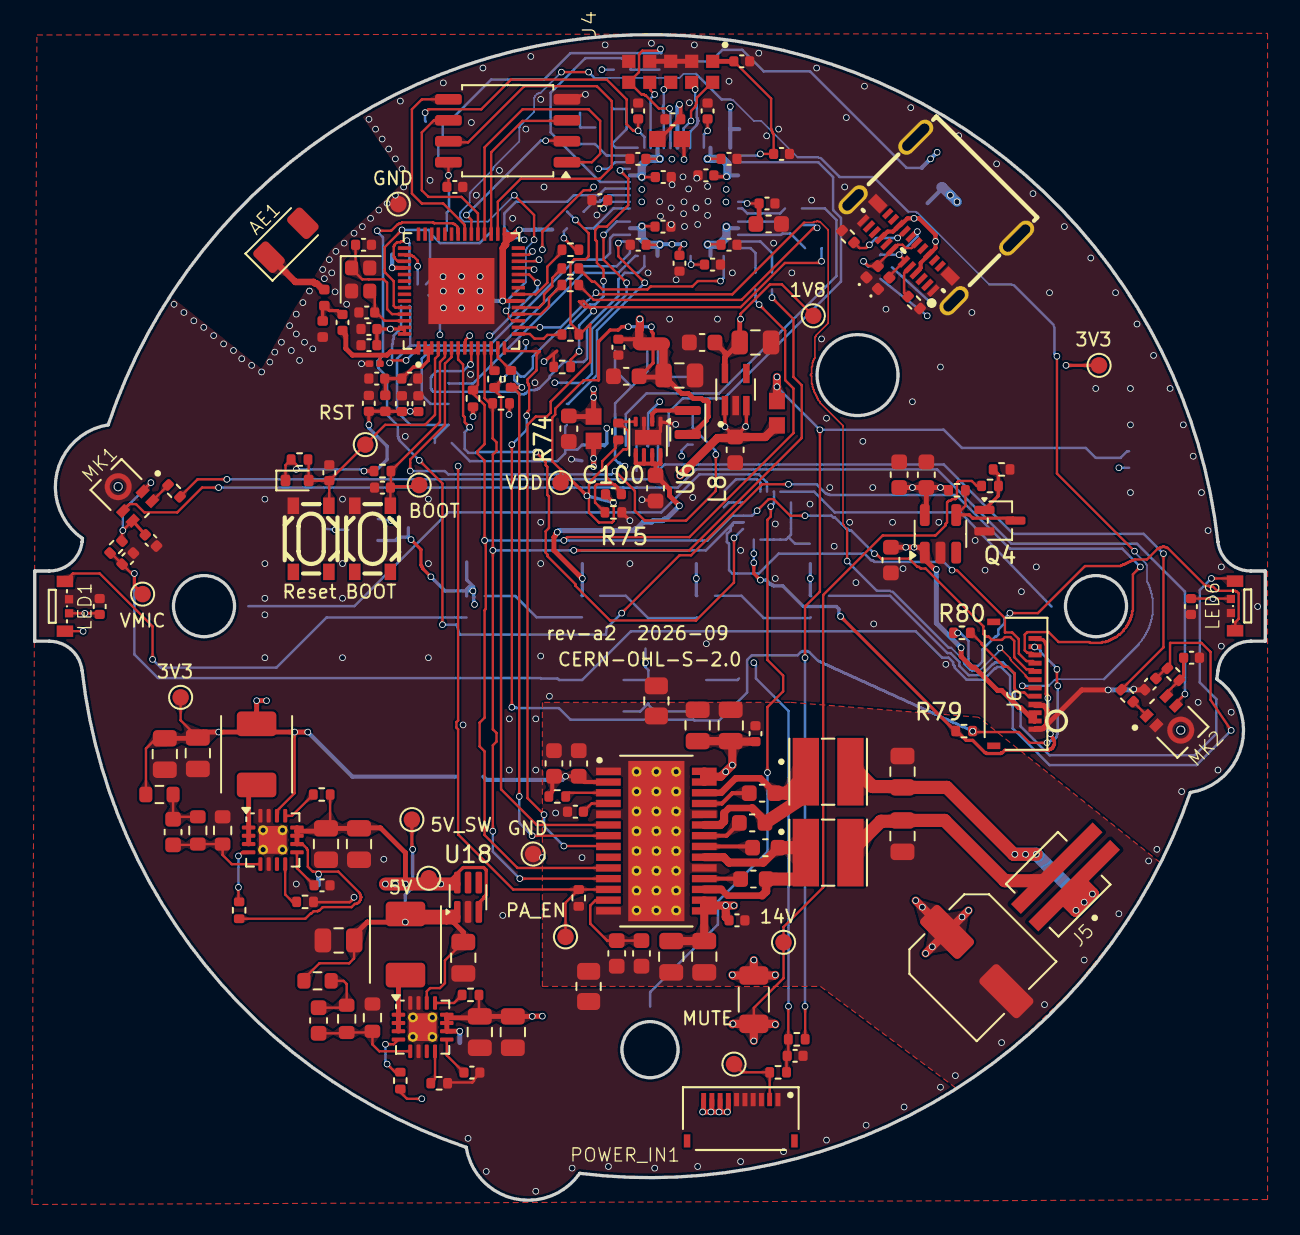
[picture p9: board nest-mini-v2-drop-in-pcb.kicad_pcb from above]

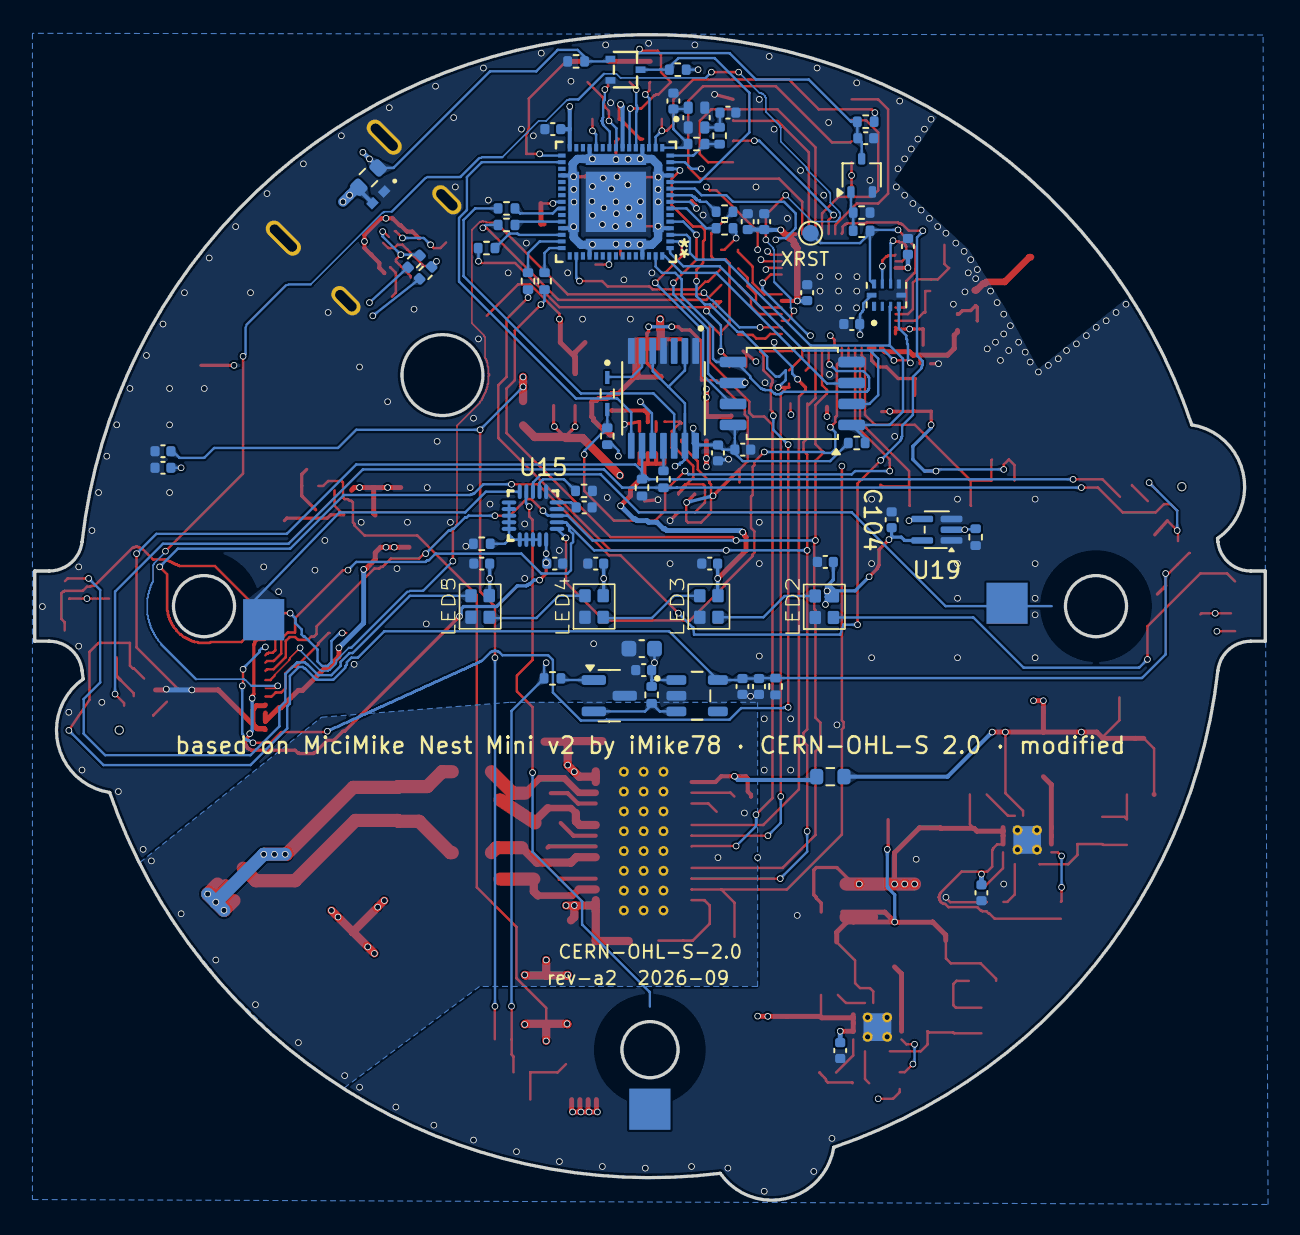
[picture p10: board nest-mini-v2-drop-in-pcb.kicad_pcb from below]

Board: 4 copper layers, 74.5 x 70.6 mm, 249 parts (75 on the bottom side), 143 nets.

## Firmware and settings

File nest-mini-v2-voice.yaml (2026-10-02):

# SPDX-FileCopyrightText: 2026 marceldale
# SPDX-License-Identifier: MIT
substitutions:
  # Phases of the Voice Assistant
  # The voice assistant is ready to be triggered by a wake word
  voice_assist_idle_phase_id: '1'
  # The voice assistant is waiting for a voice command (after being triggered by the wake word)
  voice_assist_waiting_for_command_phase_id: '2'
  # The voice assistant is listening for a voice command
  voice_assist_listening_for_command_phase_id: '3'
  # The voice assistant is currently processing the command
  voice_assist_thinking_phase_id: '4'
  # The voice assistant is replying to the command
  voice_assist_replying_phase_id: '5'
  # The voice assistant is not ready
  voice_assist_not_ready_phase_id: '10'
  # The voice assistant encountered an error
  voice_assist_error_phase_id: '11'
  # Change this to true in case you ahve a hidden SSID at home.
  hidden_ssid: "false"
  # Abschluss: die Verweise ${device_name} (AP-SSID) und ${friendly_name}
  #     (Neustart-Knoepfe) liefen seit F4 ins Leere - hier wieder definiert.
  device_name: nest-mini-v2
  friendly_name: Nest Mini v2

esphome:
  # F4: Name und Anzeigename ersetzt. Den Anzeigenamen habe ich aus dem Geraetenamen
  #     abgeleitet - falls er anders lauten soll, ist es diese eine Zeile.
  name: nest-mini-v2
  friendly_name: Nest Mini v2
  # K-B10: mit dieser Version uebersetzt und geprueft (ESPHome 2026.9.0 -> ESP-IDF 5.5.5
  #     ueber framework: version: recommended). Voice PE d4e6fa4: ebenso.
  min_version: 2026.9.0
  on_boot:
    - then:
      - light.turn_on:
          id: led_ring
          effect: slow_pulse
          red: 100%
          green: 60%
          blue: 0%
      - wait_until:
          condition:
            wifi.connected:
      - light.turn_on:
          id: led_ring
          effect: pulse
          red: 0%
          green: 100%
          blue: 0%
      - wait_until:
          condition:
            api.connected:
      - light.turn_on:
          id: led_ring
          effect: none
          red: 0%
          green: 100%
          blue: 0%
      - delay: 1s
      - script.execute: reset_led
    # MPR121: nur ELE0-ELE2 messen. ESPHome schaltet die Elektroden als Bereich 0..n ein und
    # setzt n mindestens auf 3 (mpr121/__init__.py: max_touch_channel = 3; ECR = 0x80 | (n + 1)
    # = 0x84), misst also auch ELE3. ELE3-ELE11 liegen auf einem gemeinsamen Netz mit R73
    # (1 MOhm) nach GND, wie in der Gen1-Basis 7de6eec6. Datenblatt MPR121 Rev. 4 (02/2013),
    # Abschnitt 5.11: nur die benutzten Kanaele einschalten spart Abtastzeit; nicht
    # eingeschaltete Elektroden sind hochohmig (Abschnitt GPIO, S. 20). ECR 0x83 = CL 10,
    # ELE0-ELE2. Erst in den Stop Mode (0x00), dann in den Run Mode; nach dem setup() der
    # Komponente, das ECR nach 100 ms schreibt.
    - priority: -100
      then:
        - delay: 500ms
        - lambda: |-
            if (!id(mpr121_component).is_failed()) {
              id(mpr121_component).write_byte(0x5E, 0x00);
              id(mpr121_component).write_byte(0x5E, 0x83);
            }


# Pin-Audit U8-B6: auf der Platine belegt, in dieser Firmware absichtlich ungenutzt (Reserve, nach
# Reset hochohmig):
#   GPIO3  QSPI_CLK, GPIO4 QSPI_D0   -> XU316-Boot-Flash U11, nie treiben (siehe U10-B7)
#   GPIO39 XMOS_SPI_CS_N, GPIO40 XMOS_SPI_MISO -> ueber U16, nur bei XU316_RST = 1 durchgeschaltet
#   GPIO9  IR_RX (R79 10k Pull-up), GPIO48 IR_TX, GPIO11 UART_RX, GPIO12 UART_TX -> J6 (Erweiterung)
# XMOS-Update: I2C-DFU ueber voice_kit; Erstprogrammierung XU316: JTAG J4 (firmware/xmos/README.md).
esp32:
  board: esp32-s3-devkitc-1
  cpu_frequency: 240MHz
  variant: esp32s3
  flash_size: 16MB
  framework:
    type: esp-idf
    version: recommended
    sdkconfig_options:
      CONFIG_ESP32S3_DATA_CACHE_64KB: "y"
      CONFIG_ESP32S3_DATA_CACHE_LINE_64B: "y"
      CONFIG_ESP32S3_INSTRUCTION_CACHE_32KB: "y"

      # Moves instructions and read only data from flash into PSRAM on boot.
      # Both enabled allows instructions to execute while a flash operation is in progress without needing to be placed in IRAM.
      # Considerably speeds up mWW at the cost of using more PSRAM.
      CONFIG_SPIRAM_RODATA: "y"
      CONFIG_SPIRAM_FETCH_INSTRUCTIONS: "y"

      CONFIG_BT_ALLOCATION_FROM_SPIRAM_FIRST: "y"
      CONFIG_BT_BLE_DYNAMIC_ENV_MEMORY: "y"

      CONFIG_MBEDTLS_EXTERNAL_MEM_ALLOC: "y"
      CONFIG_MBEDTLS_SSL_PROTO_TLS1_3: "y"  # TLS1.3 support isn't enabled by default in IDF 5.1.5
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

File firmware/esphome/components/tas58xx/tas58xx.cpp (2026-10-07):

// Modified 2026-10-05 by marceldale for nest-mini-v2-voice: DC and over-current faults are no longer cleared
// automatically on the next update (output stays off until restart). Original:
// https://github.com/mrtoy-me/esphome-tas58xx @ 89f29cf. See firmware/esphome/PATCH.md.
#include "tas58xx.h"
#include "tas58xx_minimal.h"
#include "tas58xx_helpers.h"

#include "esphome/core/log.h"
#include "esphome/core/application.h"

namespace esphome::tas58xx {

#ifdef USE_TAS5805M_DAC
static constexpr const char* TAG = "tas5805m";
#else
static constexpr const char* TAG = "tas5825m";
#endif

static constexpr const char* ERROR = "Error";
static constexpr const char* MIXER_MODE = "Mixer Mode";
static constexpr const char* EQ_BAND = "EQ Band";

static constexpr uint8_t TAS58XX_MUTE_CONTROL = 0x08; // bit mask for mute control

static constexpr uint8_t DELAY_LOOPS = 40;  // 40 loop iterations ~ 300ms initial delay in 'loop' before writing eq settings

static constexpr uint16_t INITIAL_UPDATE_DELAY = 4000;  // initial ms delay before starting fault updates

void Tas58xxComponent::setup() {
  ESP_LOGCONFIG(TAG, "Running setup");
  if (this->enable_pin_ != nullptr) {
    this->enable_pin_->setup();
    this->enable_pin_->digital_write(false);
    delay(1);
    this->enable_pin_->digital_write(true);
    delay(5);
  }

  if (!this->configure_registers_()) {
    this->error_code_ = CONFIGURATION_FAILED;
    this->mark_failed();
  }

  // rescale -103db to 24db digital volume range to register digital volume range 254 to 0
  this->tas58xx_raw_volume_max_ = (uint8_t)((this->tas58xx_volume_max_ - 24) * -2);
  this->tas58xx_raw_volume_min_ = (uint8_t)((this->tas58xx_volume_min_ - 24) * -2);
}

bool Tas58xxComponent::configure_registers_() {
  static constexpr uint8_t ESPHOME_MAXIMUM_DELAY = 5; // milliseconds

  uint16_t i = 0;
  uint16_t counter = 0;
  uint16_t number_configurations = sizeof(TAS58XX_CONFIG) / sizeof(TAS58XX_CONFIG[0]);

  while (i < number_configurations) {
    switch (TAS58XX_CONFIG[i].addr) {
      case TAS58XX_CFG_META_DELAY:
        if (TAS58XX_CONFIG[i].value > ESPHOME_MAXIMUM_DELAY) return false;
        delay(TAS58XX_CONFIG[i].value);
        break;
      default:
        if (!this->tas58xx_write_byte_(TAS58XX_CONFIG[i].addr, TAS58XX_CONFIG[i].value)) return false;
        counter++;
        break;
    }
    i++;
  }
  this->number_registers_configured_ = counter;

  // enable Tas58xx
  if (!this->set_deep_sleep_off_()) return false;

  if (!this->set_modulation_scheme_(this->tas58xx_modulation_scheme_)) return false;

  if (!this->set_dac_mode_(this->tas58xx_dac_mode_)) return false;

  if (!this->set_analog_gain_(this->tas58xx_analog_gain_)) return false;

  if (!this->set_state_(CTRL_PLAY)) return false;

  this->start_time_ = App.get_loop_component_start_time();
  return true;
}

void Tas58xxComponent::loop() {
  // 'play_file' is initiated by YAML on_boot with priority 220.0f
  // 'refresh_eq_settings' is triggered by Number 'left_eq_gain_16000hz' or 'right_eq_gain_16000hz' or Select 'eq_mode'
  // each with setup priority AFTER_CONNECTION = 100.0f
  // delay refreshing EQ settings until refresh is triggered so tas58xx has detected i2s clock through sound being played

  // loop_setup_stage_ is initially WAIT_FOR_TRIGGER

  switch (this->loop_setup_stage_) {
    case WAIT_FOR_TRIGGER:
      return;

    case RUN_DELAY_LOOP:
      if (this->loop_counter_ < DELAY_LOOPS) {    // loop_count was initialised to 0
        this->loop_counter_++;
        return;
      }
      this->loop_setup_stage_ = INPUT_MIXER_SETUP;
      return;

    case INPUT_MIXER_SETUP:
      // setup Eq Mode first
      if (!this->set_eq_mode_(this->tas58xx_eq_mode_)) {
         ESP_LOGW(TAG, "%s setting EQ Mode: %s", ERROR, EQ_MODE_TEXT[this->tas58xx_eq_mode_]);
      }

      if (!this->set_mixer_mode(this->tas58xx_mixer_mode_)) {
        ESP_LOGW(TAG, "%s setting %s: %s", ERROR, MIXER_MODE, MIXER_MODE_TEXT[this->tas58xx_mixer_mode_]);
      }
      this->loop_setup_stage_ = LR_VOLUME_SETUP;
      return;

    case LR_VOLUME_SETUP:
#ifdef USE_TAS58XX_CHANNEL_VOLUMES
      if (!this->set_channel_volume(LEFT_CHANNEL, this->tas58xx_channel_volume_[LEFT_CHANNEL])) {
        ESP_LOGW(TAG, "%s setting Left Channel Gain: %ddb", ERROR, this->tas58xx_channel_volume_[LEFT_CHANNEL]);
      }

      if (!this->set_channel_volume(RIGHT_CHANNEL, this->tas58xx_channel_volume_[RIGHT_CHANNEL])) {
        ESP_LOGW(TAG, "%s setting Right Channel Gain: %ddb", ERROR, this->tas58xx_channel_volume_[RIGHT_CHANNEL]);
      }
#endif

#ifdef USE_TAS58XX_EQ_GAINS
      this->loop_setup_stage_ = EQ_BANDS_SETUP;
#endif

#ifdef USE_TAS58XX_EQ_PRESETS
      this->loop_setup_stage_ = EQ_PRESETS_SETUP;
#endif

      // if loop_setup_stage_ has not changed then no EQ configured
      if (this->loop_setup_stage_ == LR_VOLUME_SETUP) this->loop_setup_stage_ = SETUP_COMPLETE;
      return;

    case EQ_BANDS_SETUP:
#ifdef USE_TAS58XX_EQ_GAINS
      if (this->refresh_band_ == NUMBER_EQ_BANDS) {     // refresh_band_ was initialised to 0
        // finished writing all bands
        this->loop_setup_stage_ = SETUP_COMPLETE;
        this->refresh_band_ = 0;
        return;
      }

      if (!this->set_eq_gain(LEFT_CHANNEL, this->refresh_band_, this->tas58xx_eq_gain_[LEFT_CHANNEL][this->refresh_band_])) {
#ifdef USE_TAS58XX_EQ_BIAMP
        ESP_LOGW(TAG, "%s setting Gain Left %s: %d", ERROR, EQ_BAND, this->refresh_band_ + 1);
#else
        ESP_LOGW(TAG, "%s setting Gain %s: %d", ERROR, EQ_BAND, this->refresh_band_ + 1);
#endif
      }

#ifdef USE_TAS58XX_EQ_BIAMP
      if (!this->set_eq_gain(RIGHT_CHANNEL, this->refresh_band_, this->tas58xx_eq_gain_[RIGHT_CHANNEL][this->refresh_band_])) {
        ESP_LOGW(TAG, "%s setting Gain Right %s: %d", ERROR, EQ_BAND, this->refresh_band_ + 1);
      }
#endif

      this->refresh_band_++;
#endif // USE_TAS58XX_EQ_GAINS
      return;

    case EQ_PRESETS_SETUP:
#ifdef USE_TAS58XX_EQ_PRESETS
      if (!this->set_eq_preset(LEFT_CHANNEL, this->tas58xx_channel_preset_[LEFT_CHANNEL])) {
        ESP_LOGW(TAG, "%s setting Left Channel Preset index: %d", ERROR, this->tas58xx_channel_preset_[LEFT_CHANNEL]);
      }
      if (!this->set_eq_preset(RIGHT_CHANNEL, this->tas58xx_channel_preset_[RIGHT_CHANNEL])) {
        ESP_LOGW(TAG, "%s setting Right Channel Preset index: %d", ERROR, this->tas58xx_channel_preset_[RIGHT_CHANNEL]);
      }
      this->loop_setup_stage_ = SETUP_COMPLETE;
#endif
      return;

    case SETUP_COMPLETE:
      this->disable_loop(); // requires Esphome 2025.7.0 or greater
      return;
  }
}
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

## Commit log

2026-10-02 rev A2 — 2026-10-02, from rev-a2-endstand (0630744)
    [BOM_JLCPCB.csv, BOM_PCBWay.csv, BOM_PCBWay.xlsx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]
2026-10-02 rev A2 (rotations corrected after the JLCPCB preview) — 2026-10-02, from rev-a2-endstand (f736024)
    [BOM_JLCPCB.csv, BOM_PCBWay.csv, BOM_PCBWay.xlsx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]
2026-10-02 rev A2 ordered — 2026-10-02, from rev-a2-ordered (ac2d784)
2026-10-02 rev A2.2 (XMOS bus flasher, BLE Improv) — 2026-10-02, from rev-a2-firmware (13ca8fc)
2026-10-07 rev A2.3 (in production) — 2026-10-07, from rev-a2-fertigung (05839b2)
    [BOM_JLCPCB.csv, BOM_PCBWay.csv, Positionen_KiCad.csv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]

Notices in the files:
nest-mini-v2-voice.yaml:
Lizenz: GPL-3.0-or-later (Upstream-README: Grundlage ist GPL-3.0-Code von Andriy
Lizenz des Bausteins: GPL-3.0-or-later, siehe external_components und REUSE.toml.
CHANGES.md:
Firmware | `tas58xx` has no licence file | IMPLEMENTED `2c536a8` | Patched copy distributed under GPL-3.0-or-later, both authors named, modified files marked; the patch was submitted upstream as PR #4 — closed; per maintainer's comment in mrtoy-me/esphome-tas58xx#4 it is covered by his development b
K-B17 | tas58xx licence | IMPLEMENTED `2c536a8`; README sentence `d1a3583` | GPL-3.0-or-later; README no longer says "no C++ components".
